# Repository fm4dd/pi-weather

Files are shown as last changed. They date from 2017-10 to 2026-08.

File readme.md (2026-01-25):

# Pi-Weather

An outdoor weather station build around the Raspberry Pi

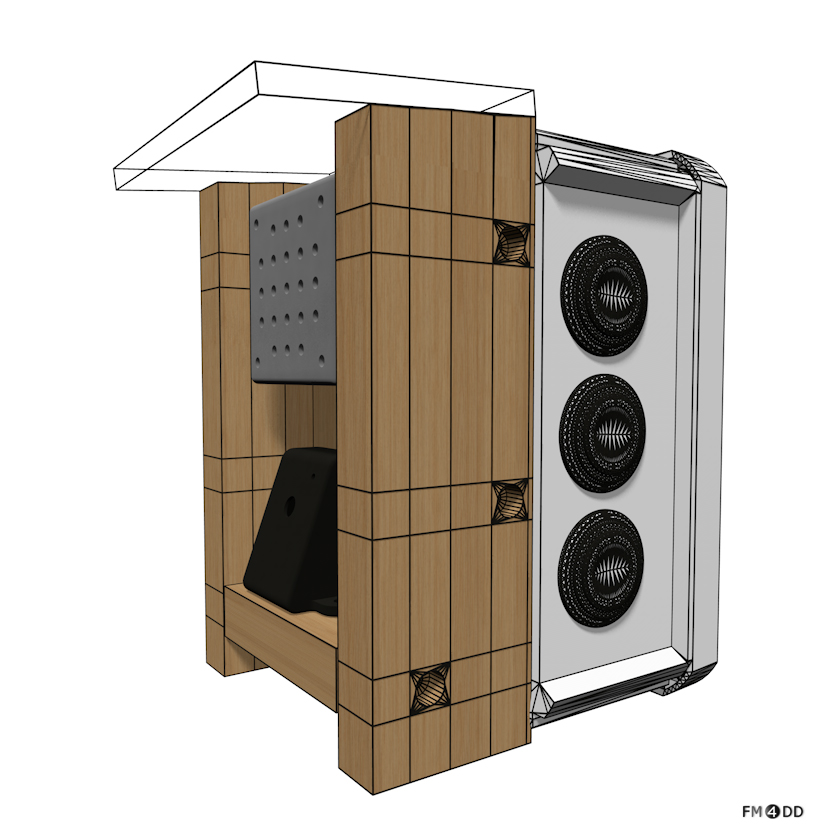
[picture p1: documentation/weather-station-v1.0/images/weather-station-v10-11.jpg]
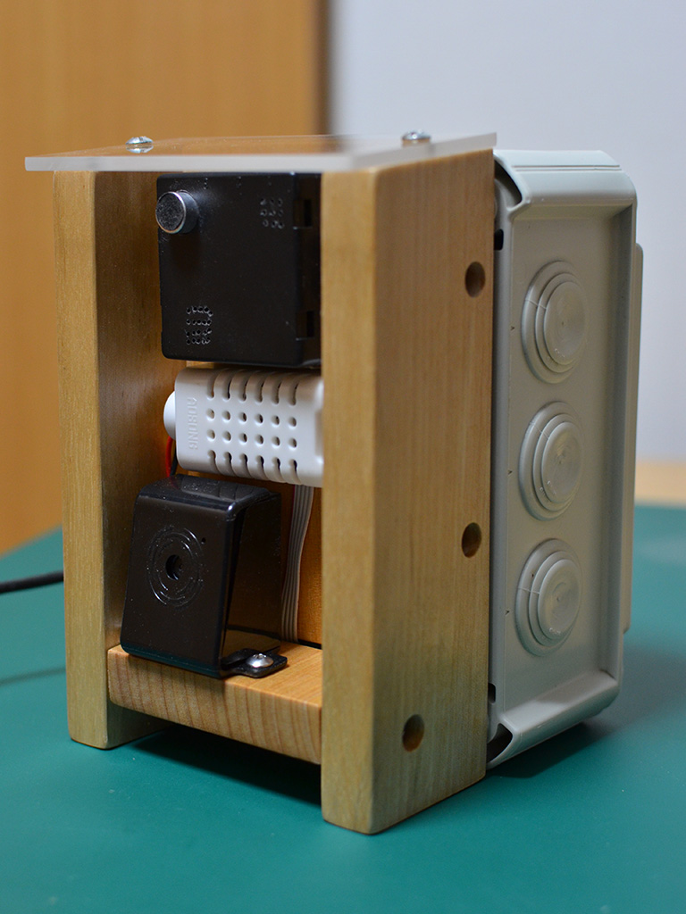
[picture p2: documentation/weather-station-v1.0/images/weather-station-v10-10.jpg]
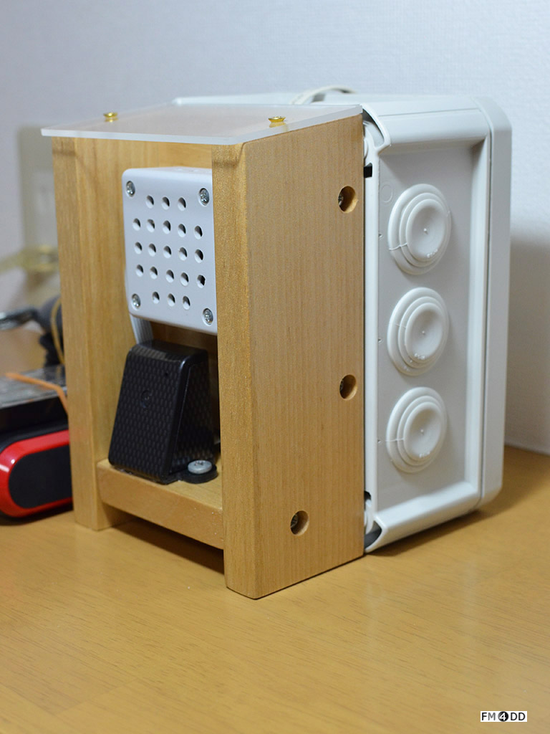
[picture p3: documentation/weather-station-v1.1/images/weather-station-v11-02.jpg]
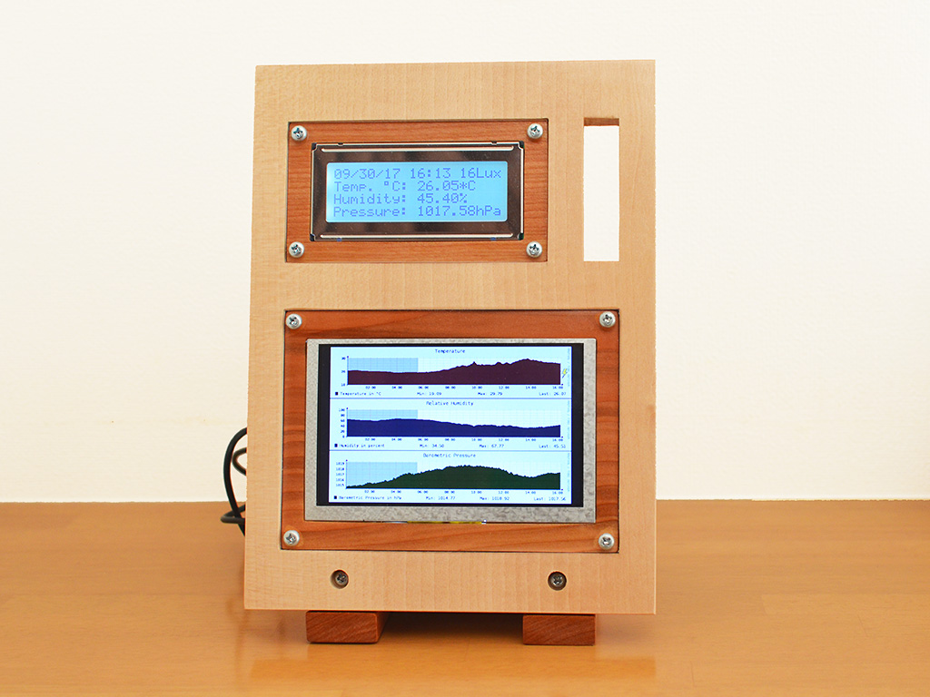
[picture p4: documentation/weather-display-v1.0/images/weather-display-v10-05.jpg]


This project contains the physical build documentation and software for running a Raspberry Pi powered outdoor weather station. With the rise of small form factor single board computers coupled with affordable sensors, monitoring of weather parameters like temperature, humidity, and air pressure allows for longterm observation, data logging and trending.

## Live Weather URL

The weather station started to work in September 2016, and its data can be seen live at <a href="http://weather.fm4dd.com/">http://weather.fm4dd.com/</a>. Besides showing actual data data readings, the weather data is presented as a graph over time. For example, the temperature data graph looks like this:

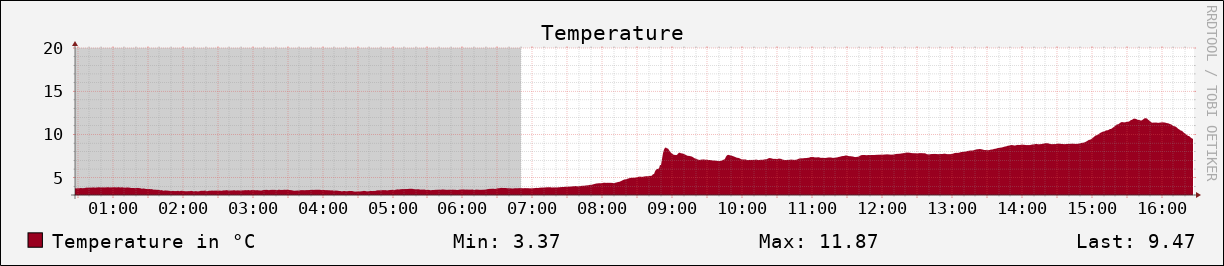
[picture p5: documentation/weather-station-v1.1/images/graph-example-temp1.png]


## Project Goals

Weather is defined as the temporary, day-to-day, minute-to-minute state of the atmosphere at a specific time and place. It is characterized by the interaction of several physical variables in the lower atmosphere (troposphere), which is constantly changing. The primary physical weather characteristics are:
* **Temperature**: Describes how hot or cold the air is, influenced by solar radiation and heat absorption.
* **Atmospheric Pressure**: The weight of the air above a given point. High pressure indicates clear skies, low pressure unsettled, cloudy, or stormy weather.
* **Wind**: The movement of air caused by differences in pressure, characterized by both speed and direction.
* **Humidity**: The amount of water vapor in the air, expressed as relative humidity, the percentage of water vapor relative to the maximum.
* **Precipitation**: Water in liquid or solid form falling from the sky as rain, snow, sleet, or hail.
* **Clouds**: Visible masses of water droplets or ice crystals suspended in the atmosphere, precursor to eventual precipitation.
* **Visibility**: The distance at which objects can be seen, which is reduced by fog, rain, or snow.

Based on available sensors, this weather station collects 3 input values, recording **Temperature**, **Atmospheric Pressure**, and **Humidity**. Because **Temperature** is strongly impacted by solar radiation, a **"Daylight"** flag based on sunrise/sunset times for the specific location provides the reference tho visualize daytime/nightime temperature ranges.

## High-level Design

Building a weather station around a Raspberry Pi allows to create a system that can long-term operate stand-alone, and has enough CPU power process environmental images in addition to sensor data. The built-in network stack can send collected data into a central consolidation site, and electrical power needs are still within range for small scale solar power. A waterproof switchbox protects the Raspberry, and a wood frame mounts the sensors together with the Raspberry Pi camera.

The <a href="documentation">documentation</a> directory has hardware BOM and CAD drawings to build the weather station and the weather display.

The necessary software can be cloned from the branches for the <a href="weather-station">weather station</a>, the optional <a href="weather-display">weather display</a>, and for the Internet accessible <a href="weather-web">website</a> that consolidates multiple weather stations from various time zones. Each weather station can operate "standalone" and self-contained, without needign to connect to a central portal.

The environmental weather data is collected through a Bosch BME280 sensor, connected to the RaspBerry Pi GPIO terminal, using the I2C bus.

## RRD Database

Sensor data is written in 1-minute intervals to an RRD database named `weather.rrd`. This database has been designed for 20 years longterm trending. It has the following parameters:

### 1. Data Source (DS) Configuration
These are the input variables stored in the database:

| DS Name | Index | Type | Min Value | Max Value | Heartbeat | Description |
| :--- | :---: | :--- | :---: | :---: | :---: | :--- |
| **temp** | 0 | GAUGE | -100 | 100 | 300s | Temperature |
| **humi** | 1 | GAUGE | 0 | 100 | 300s | Humidity (%) |
| **bmpr** | 2 | GAUGE | 0 | 200,000 | 300s | Barometric Pressure |
| **dayt** | 3 | GAUGE | 0 | 1 | 300s | Daylight Flag (Boolean) |

### 2. Round Robin Archive (RRA) Configuration
These are the retention settings, showing how data is consolidated and how long it is retained:

| RRA | Consolidation (CF) | Steps (PDP) | Resolution | Rows | Retention Period |
| :--- | :--- | :---: | :--- | :---: | :--- |
| **0** | AVERAGE | 1 | 1 Minute | 20,160 | 14 Days |
| **1** | AVERAGE | 60 | 1 Hour | 17,568 | 2 Years |
| **2** | AVERAGE | 1440 | 1 Day | 7,320 | 20 Years |
| **3** | MIN | 60 | 1 Hour | 17,568 | 2 Years |
| **4** | MAX | 60 | 1 Hour | 17,568 | 2 Years |
| **5** | MIN | 1440 | 1 Day | 7,320 | 20 Years |
| **6** | MAX | 1440 | 1 Day | 7,320 | 20 Years |

### 3. Database Characteristics

#### Data Integrity & Heartbeat:

The `minimal_heartbeat` is set to **300s** (5 minutes). With a base step of 60 seconds, the database will tolerate up to 4 consecutive missing updates. If no data is received for 5 minutes (5), the entry will be recorded as `UNKNOWN` (NaN).

All archives use an Consolidation Threshold `xff` of **0.5**. This is called the xfiles factor, and means that as long as at least 50% of the primary data points in a given interval are known, the consolidated archive entry will be calculated; otherwise, it will be stored as `UNKNOWN`.

#### High Resolution:

With a base step of **60 seconds**, the database keeps 1-minute granular data for exactly **14 days** (20,160 rows) in RRA 0.

#### Long-Term History:

The daily archives (RRA 2, 5, 6) are configured to retain data for **20 years** (7,320 rows), making this schema ideal for long-term climate trend analysis.

#### Statistical Tracking:

The schema tracks not only the **AVERAGE** values but also the **MIN** and **MAX** values for hourly and daily intervals. This prevents "averaging out" extreme weather events (like temperature spikes or pressure drops) in long-term logs.

#### Database Size:

The database uses 3MB disk space.

```
pi@pi-ws01:~ $ du -sh /home/pi/pi-ws01/rrd/weather.rrd
2.9M    /home/pi/pi-ws01/rrd/weather.rrd
```
The xml extracted database dump is 13MB.
```
pi@pi-ws01:~ $ du -sh /tmp/tmp.xml
13M     /tmp/tmp.xml
```

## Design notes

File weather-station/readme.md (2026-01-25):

## Pi Weather Station Software Package

This directory is tagged as a branch, to be cloned or copied into the weather stations Raspberry Pi OS. It contains the scripts for setup, upgrade and maintenance of weather station code and data. The weather station software is a mix of C programs and shell scripts. Data collection is using standard cron entries. RRD is used as the backend database.

## Installer Directory Overview

```
weather-station/
├── backup/ ................. (empty) Used to store local configuration and data during software upgrades
│
├── etc/ .................... Contains the configuration template, which is the first file that needs to be edited.
│
├── install/ ................ Contains the scripts to create and upgrade the station software, or repair data.
│
├── src/ .................... Contains C source code for the station software.
│                             Compilation and install is done through setup.sh inside the install directory.
└── web/ .................... Contains the template files for the local website that runs on the weather station.
                              The files are moved into place through setup.sh located in the "install" folder.
 ```

## Prerequisites

The weather stations Raspberry Pi's use Rasbian OS in the "lite" version, which fills the SD cards disk space to about 1.2 GB. The network should be configured for Internet access. The install process will get about 300 MB of additional required packages. The network connectivity can be either through Wifi or Ethernet, the weather station can work with either one.

Before I write the Rasbian OS image to SD card, I modify the image to add local network information, which lets me bring up the Pi into the local network and connect immediately at first boot. For modification, I mount the stock image file from a Linux VM as follows:

- Get file system layout

```
root@linvm:~ # fdisk -l 2017-04-10-raspbian-jessie-lite.img 
Disk 2017-04-10-raspbian-jessie-lite.img: 1.2 GiB, 1297862656 bytes, 2534888 sectors
Units: sectors of 1 * 512 = 512 bytes
Sector size (logical/physical): 512 bytes / 512 bytes
I/O size (minimum/optimal): 512 bytes / 512 bytes
Disklabel type: dos
Disk identifier: 0x84fa8189

Device                               Boot Start     End Sectors  Size Id Type
2017-04-10-raspbian-jessie-lite.img1       8192   92159   83968   41M  c W95 FAT32 (LBA)
2017-04-10-raspbian-jessie-lite.img2      92160 2534887 2442728  1.2G 83 Linux
```

- Mount the Linux partition by calculating its offset

```
root@linvm:~ # mount 2017-04-10-raspbian-jessie-lite.img -o loop,offset=$((512 * 92160)) /mnt
root@linvm:~ # ls /mnt/
```

- Update network and other configuration files

```
vi /mnt/etc/network/interfaces
vi /mnt/etc/wpa_supplicant/wpa_supplicant.conf
vi /mnt/etc/hosts
vi /mnt/etc/hostname
vi /mnt/etc/rsyslog.conf
vi /mnt/etc/modprobe.d/bcm2835_gpiomem.conf
ln -s /etc/init.d/ssh /etc/rc3.d/S02ssh
ln -s /etc/init.d/ssh /etc/rc5.d/S02ssh (or manually create a empty file called "ssh" in the boot partition of the SD card).
umount /mnt
```

Latest version of Rasbian was updated to Debian 9 Stretch, and works. It required only two package name updates (librrd4->librrd8, php5-cgi->php-cgi). Stretch added systemd logging noise which  had to be filtered to save the sdcard from extra wear.

## Software Installation

After first boot, run raspi-config to enable the I2C-bus and camera, configure timezone. Download the weather-station SW package (git or manual .gtgz package download).

First, create or update the configuration file `pi-weather.conf` in the `etc` directory. The following settings are minimum to be configured:

- *pi-weather-sid* --> Station ID that must be unique to each station. The value is used to set the hostname, and for data uploads to the centralized Internet website. The schema is pi-wsXX. XX is a two-digit number that is simply counted up.

- *pi-weather-lat* --> GPS latitude of the weather stations location. Value needs to be in decimal format.

- *pi-weather-lon* --> GPS longitude of the weather stations location. Decimal format.

- *pi-weather-tzs* --> Weather stations timezone setting (match entry in /usr/share/zoneinfo).

- *sensor-type=bme280* --> One of the supported sensor types.
*sensor-addr=0x76* --> The sensors I2C address.

Next, change directory into the `install` folder, and execute the script `setup.sh`. The script should run tests to confirm the sensor function. It creates the weather stations work directory named after the station ID, e.g. `pi-ws01`, containing the binaries and data directories.

#### Installed Spplication Folder Structure

```
pi-ws01/
├── bin/ .................... [Executables & Shell Scripts]
│                             (Data processing binaries and .sh scripts)
├── etc/ .................... [Configuration & Batch Files]
│                             (System .conf and SFTP transfer .bat files)
├── log/ .................... [Text Logs]
│                             (.log files for monitoring background tasks)
├── rrd/ .................... [Database Files]
│                             (.rrd files for time-series weather data)
├── var/ .................... [Data, Compressed XML & Logs]
│   │                         (Raw .txt data, .xml.gz, and .log files)
│   └── tmp/ ................ [Temporary Directory]
└── web/ .................... [Web Application Files]
    │                         (Web logic .php, templates .htm, and .json)
    ├── images/ ............. [Visual Assets & Generated Charts]
    │                         (UI .gif files and sensor .png/.jpg graphs)
    └── wcam/ ............... [Webcam Directory]
                              (Sub-folders for webcam media storage)
```

## Local Station Operation

After completion, reboot the Pi. The weather station software installed a local web service (Lightttp) that allows pointing a browser to the stations IP address. The cron jobs should start collecting sensor data filling the RRD, and taking camera pictures in 1 minute intervals. Any issues can be investigated by looking at the files in `var` and `log` directories.

- Check the sensor data file existence and timestamp

```
pi@pi-ws01:~ $ ls -l pi-ws01/var/sensor.txt
-rw-r--r-- 1 pi pi 61 Oct 29 11:54 pi-ws01/var/sensor.txt
```

- Check the sensor data content

```
pi@pi-ws01:~ $ cat pi-ws01/var/sensor.txt
1509245646 Temp=14.83*C Humidity=91.26% Pressure=100555.85Pa
```

- Check the RRD database update log

```
pi@pi-ws01:~ $ cat pi-ws01/var/rrdupdate.log
rrdupdate.sh: Run at Sun 29 Oct 11:55:11 JST 2017
rrdupdate.sh: Config file [/home/pi/pi-ws01/bin/../etc/pi-weather.conf]
rrdupdate.sh: Sensor Data [1509245706 Temp=14.84*C Humidity=91.20% Pressure=100561.37Pa]
rrdupdate.sh: Temperature [14.84] outlier detection OK.
rrdupdate.sh: Humidity [91.20] outlier detection OK.
rrdupdate.sh: Pressure [100561.37] outlier detection OK.
rrdupdate.sh: daytime flag /home/pi/pi-ws01/bin/daytcalc -t 1509245706 -x 139.628999 -y 35.610381
rrdupdate.sh: daytcalc 1509245706 returned [0] [day].
/usr/bin/rrdtool update /home/pi/pi-ws01/rrd/weather.rrd 1509245706:14.84:91.20:100561.37:0
return_value = 0
[1509245700]RRA[AVERAGE][1]DS[temp] = 1.4839000000e+01
[1509245700]RRA[AVERAGE][1]DS[humi] = 9.1206000000e+01
[1509245700]RRA[AVERAGE][1]DS[bmpr] = 1.0056081800e+05
[1509245700]RRA[AVERAGE][1]DS[dayt] = 0.0000000000e+00
Creating image /home/pi/pi-ws01/web/images/daily_temp.png... 700x150
Creating image /home/pi/pi-ws01/web/images/daily_humi.png... 700x150
Creating image /home/pi/pi-ws01/web/images/daily_bmpr.png... 700x150
rrdupdate.sh: Finished Sun 29 Oct 11:55:12 JST 2017
```

## Integration with the Internet-based Web Server

The weather station is typically part of a private (home) network that allows only outbound Internet access. To access the weather stations data remotely, the station can be set to send its sensor and camera data to the central Internet web server (e.g. http://weather.fm4dd.com). The script `send-setup.sh` in the `install` directory collects the necessary information and copies it into the Internet server.

After the Internet web server has been set up, the sensor data is feed to Internet web server in parallel to the local RRD database updates. To compensate for temporary local network outages, a daily transmission sends the full RRD database to the Internet server. 

Because RRD databases are CPU-specific, they can't be copied from a Raspi (ARM) to an Intel environment. For RRD database migrations, the `rrdtool dump` command creates a XML extract that can be restored to different platforms. For manal DB transmission, below commands serve as an example:

- Raspi side

```
pi@pi-ws01:~ $ rrdtool dump /home/pi/sensor/rrd/weather.rrd > weather.xml
pi@pi-ws01:~ $ scp weather.xml user@weather.fm4dd.com:~
```

- Internet server side

```
ws01@weatherweb:~ $ rrdtool restore /home/ws01/weather.xml pi-ws01.rrd
```

## Optional Hardware Setup

The script `rtcenable.sh` can enable an optional battery-buffered real-time clock module. The RTC is helpful for weather stations without permanent Internet access. If they are unable to sync their time from the net, they are at risk of running wrong system time, which in turn could break the sensor data collection.

## Sensor Failures and Recovery

Due to age or sever weather conditions, sensors break down after some time. Instead of just stopping operations, they often start to send wrong data readings. It is not uncommon to see -2 temperature, 500000 Pa pressure or 100% humidity in such circumstances. While the weather station has a "outlier" function to identify and eliminate sporadic, single miss-reads, the continous reporting of false data from a broken sensor is harder to handle. After fixing the sensor hardware, database cleanup is done to eradicate the erroneous longterm data which take hold in the MIN/MAX aggregations. With the database type being RRD, there is no easy way to edit or update individual entries.

### rrdrepair.sh

The script `rrdrepair.sh` was created to help with database cleanup in between current data updates. It exports the RRD content into XML, which is then updated by a prepared vi source file before being re-imported into RRD. Due to the RRD size, XML line count is quite high, which slows down vi's line matching. Ideally the RRD repair process is done in between the 1-minute data readings to prevent loss of a reading. `rrdrepair.sh` therefore catches the moment right after the latest file update to maximise the time window.

### wsreplace.sh

The script `wsreplace.sh` automates the transfer of the weather station work directory and other necessary data to a second station in order to let it take over the function of the first. This allows for a quick swap of a complete weather station for repairs or upgrades. Before, this swap needed too much time for extracting the old stations micro SD card.

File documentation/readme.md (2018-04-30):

# Pi-Weather Design and Build Documentation

This folder contains documentation for the physical build of the outdoor weather station and the weather display. It includes CAD drawings, wiring schemas, bill of materials (BOM) and build pictures.

## Weather Display, Version 1.0

A permanent weather display was on the back of my mind. A 20x4 LCD character display for displaying the weather stations data, and a 5 inch TFT screen for showing the graphs. The control unit is a Raspberry Pi A Plus. It is interfacing with the TFT display though a HDMI board, and through an I2C with the character LCD. 

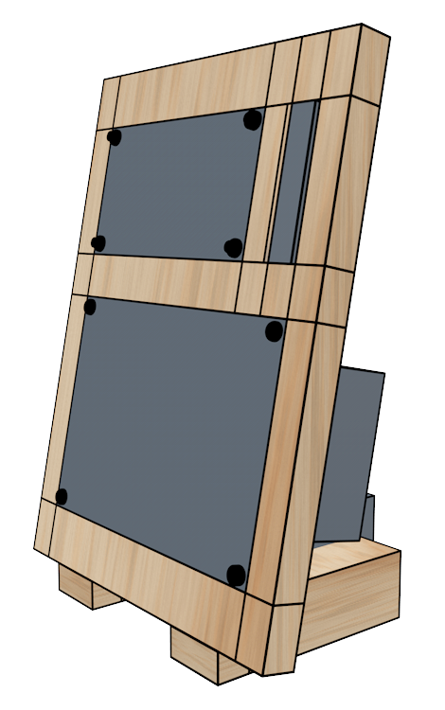
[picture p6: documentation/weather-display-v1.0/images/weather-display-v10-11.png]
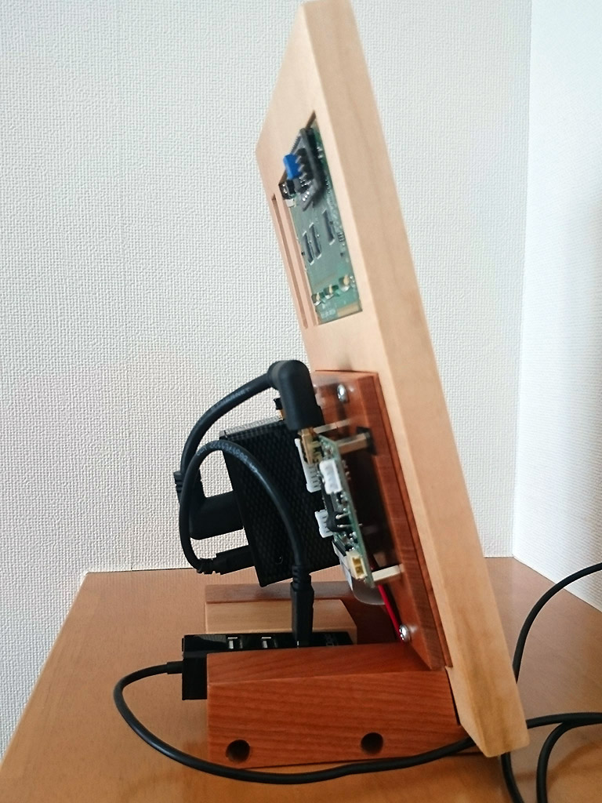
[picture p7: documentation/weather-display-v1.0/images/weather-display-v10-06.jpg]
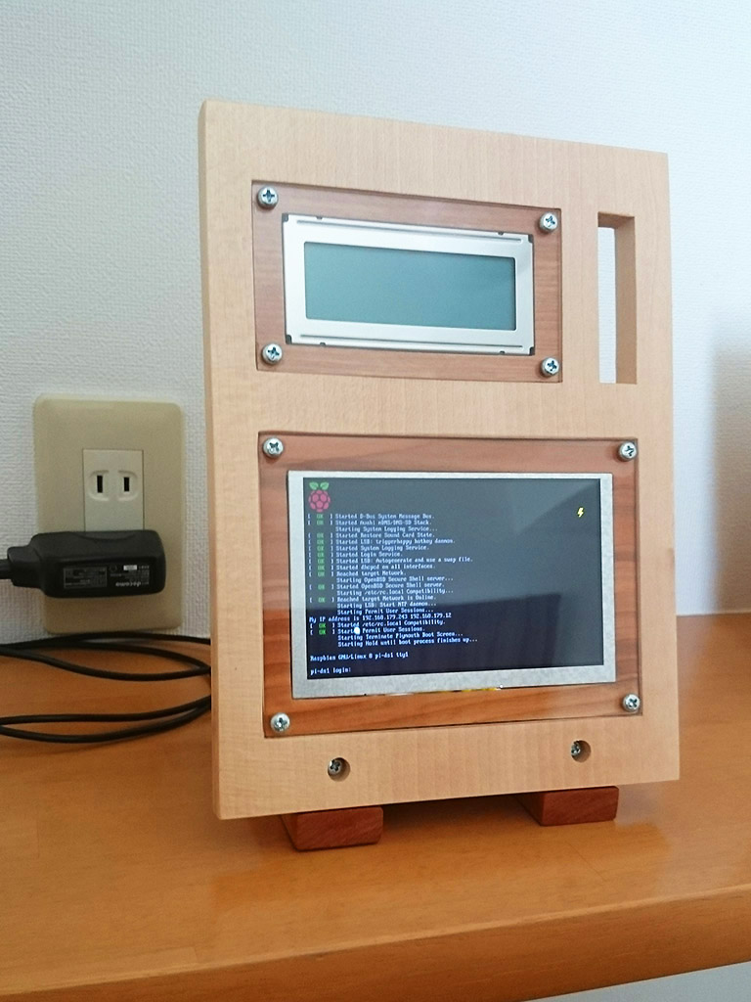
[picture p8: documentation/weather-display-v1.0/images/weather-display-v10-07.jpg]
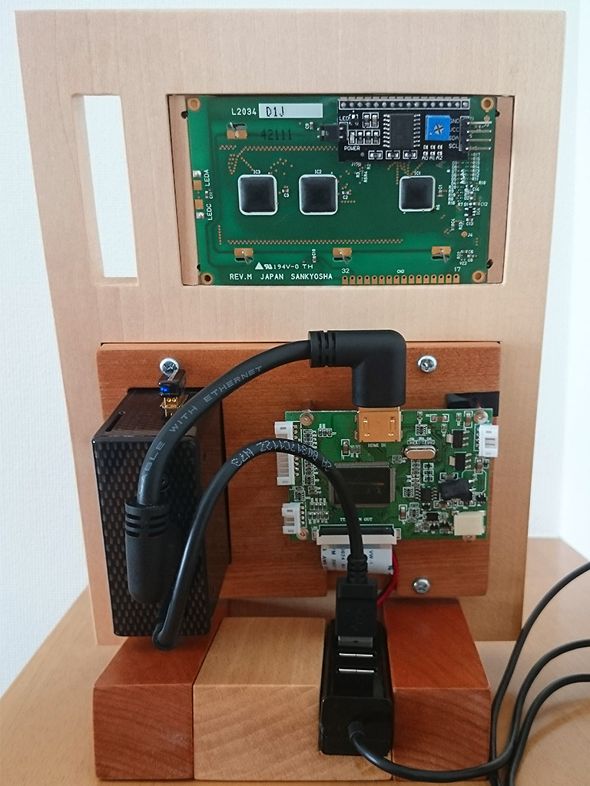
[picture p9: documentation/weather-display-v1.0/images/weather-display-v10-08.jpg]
    

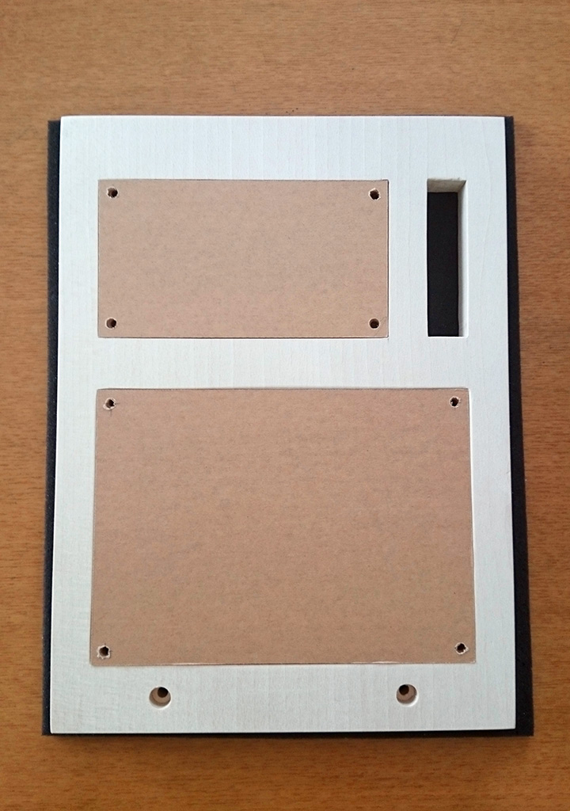
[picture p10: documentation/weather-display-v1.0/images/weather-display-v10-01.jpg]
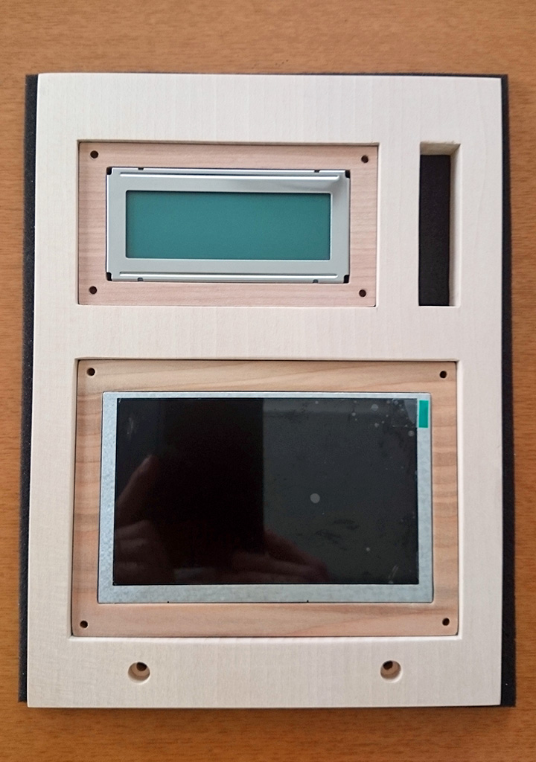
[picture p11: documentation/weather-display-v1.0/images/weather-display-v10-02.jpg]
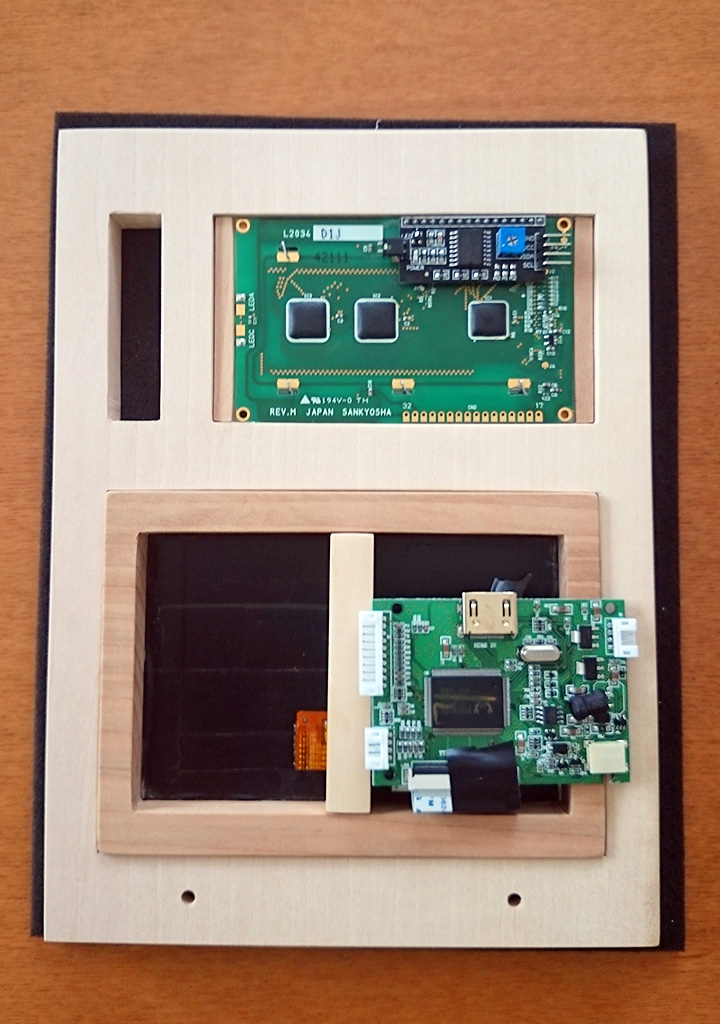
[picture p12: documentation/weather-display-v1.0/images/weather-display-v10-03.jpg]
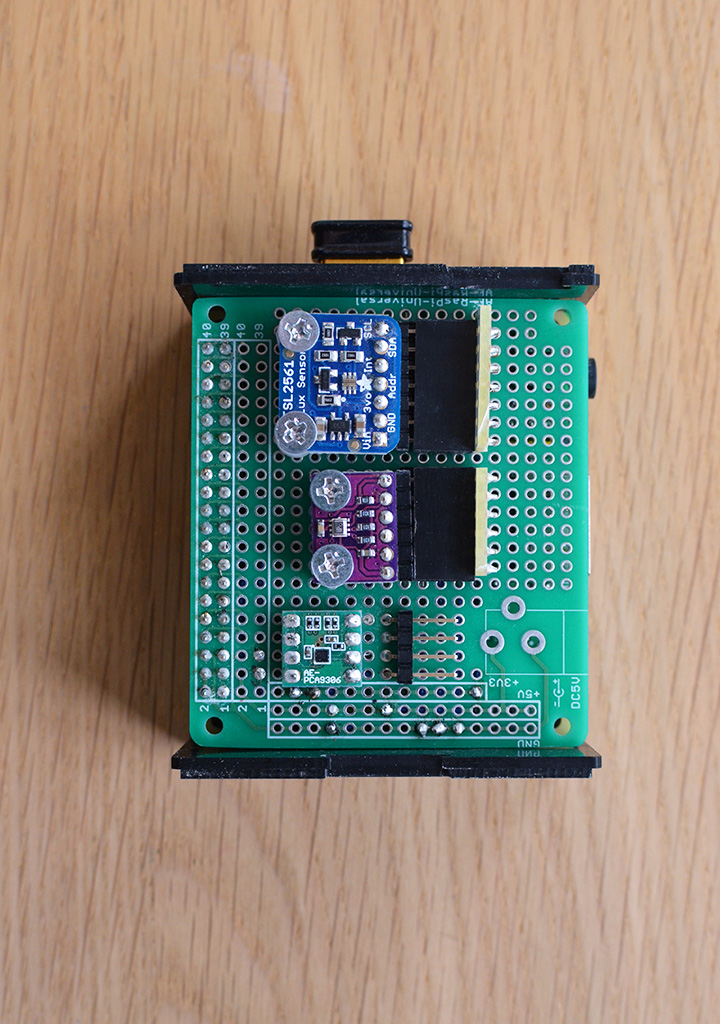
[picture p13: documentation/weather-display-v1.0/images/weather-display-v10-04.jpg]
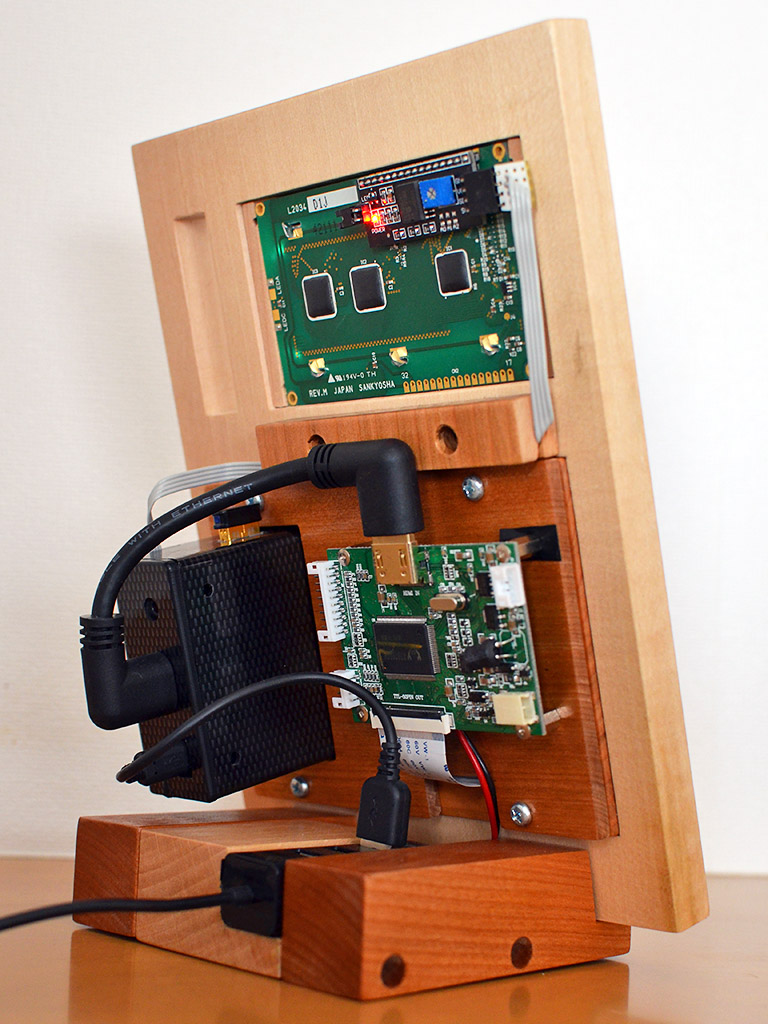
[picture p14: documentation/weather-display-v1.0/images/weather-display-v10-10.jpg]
    

## Weather Station, Version 1.1

 After five months of operation, the weather stations sensor AM2302 started to fail, with humidity getting stuck permanently at 100%. Research found this is a common and rather frequent problem. The search of an alternate sensor lead to the Bosch BME280. It offered several benefits by combining temperature, humidity and air pressure in one small package. The I2C interface seemed easier to handle than the non-standard bit-banging protocol of the AM2302. A suitable case was found for housing the BME280 sensor, and the wood frame received small changes to reduce manufacture effort. The sensor is made pluggable for easy replacement.

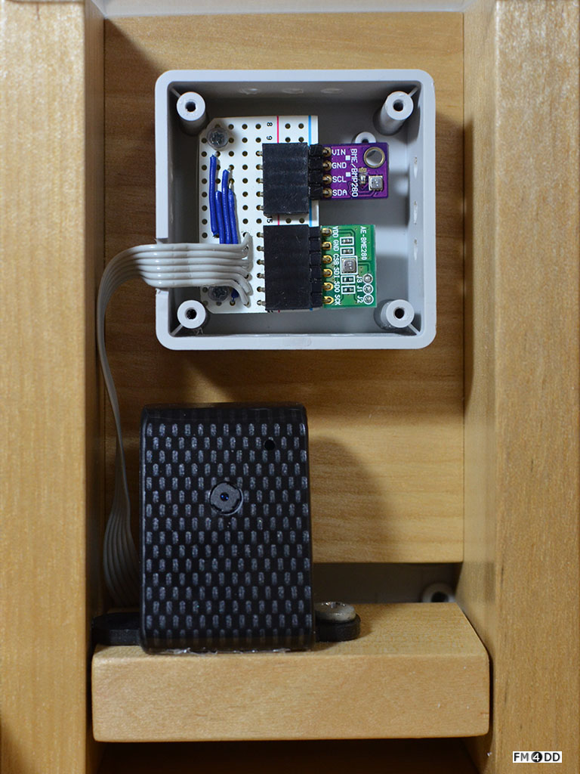
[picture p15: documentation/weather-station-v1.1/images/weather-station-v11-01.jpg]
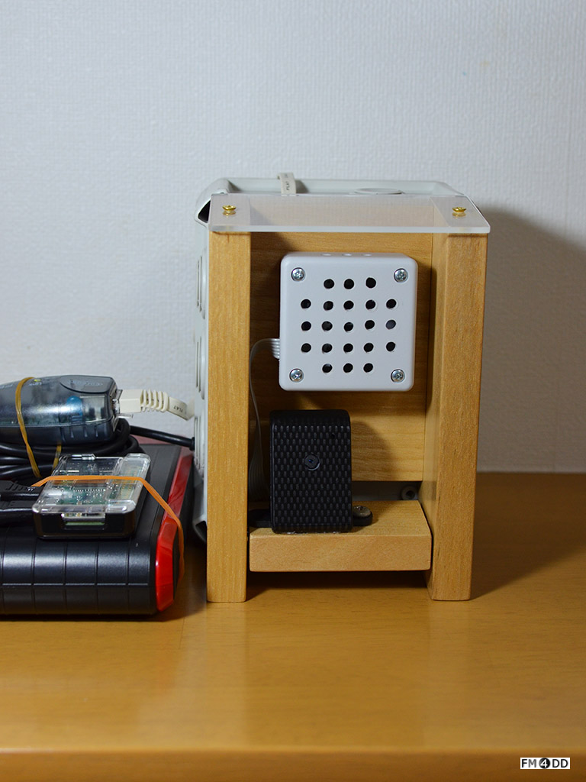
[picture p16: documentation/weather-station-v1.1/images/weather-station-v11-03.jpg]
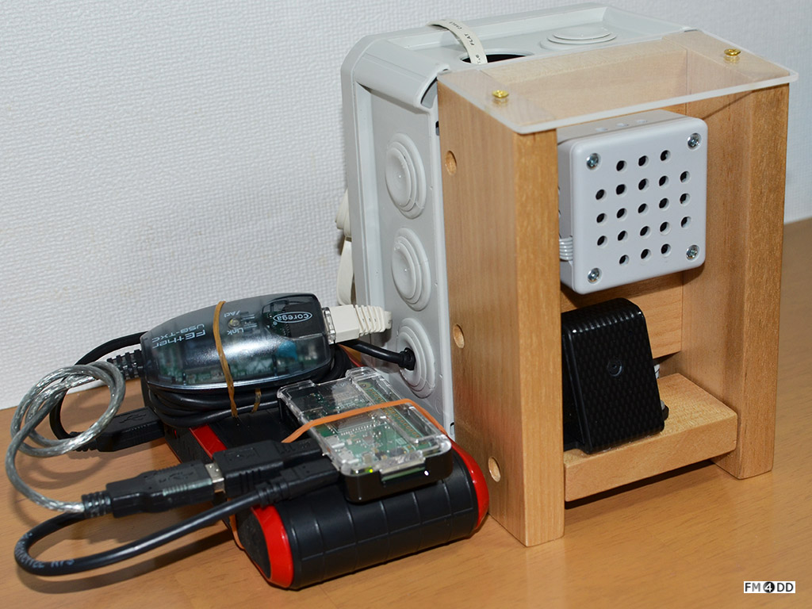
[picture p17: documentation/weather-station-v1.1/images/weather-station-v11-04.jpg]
   

This version started to use the Raspberry Pi 3 with built-in WiFi for network connectivity. Together with the new sensor case, the interface wiring slightly changed from version 1.0. A serial line addition is prepared to obtain data from a Victron charge controller (solar-powered "off-the-grid" operation).

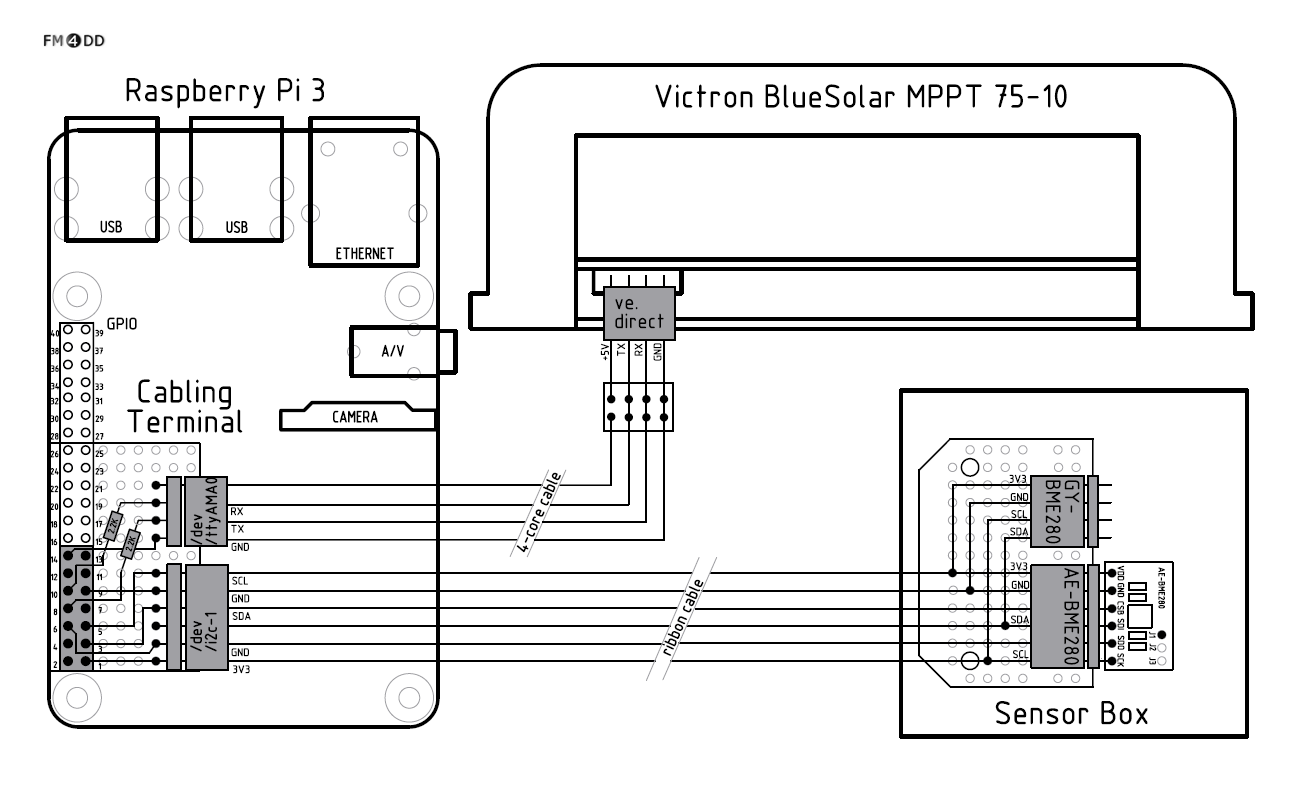
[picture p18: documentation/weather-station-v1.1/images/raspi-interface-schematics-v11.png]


## Weather Station, Version 1.0

This was the first weather station build. It used a AM2302 temperature/humidity sensor from <a href="http://www.aosong.com/en/home/index.asp">Aosong</a>. After functional tests confirmed the sensors function, a suitable weather-proof box for housing the Raspberry Pi was found at <a href="https://www.conrad.de/">Conrad</a>, Bettermans junction box <a href="https://obo.de/article/display/en-wo/junction-box-t-100-plug-in-seal.html">OBO T100</a>.

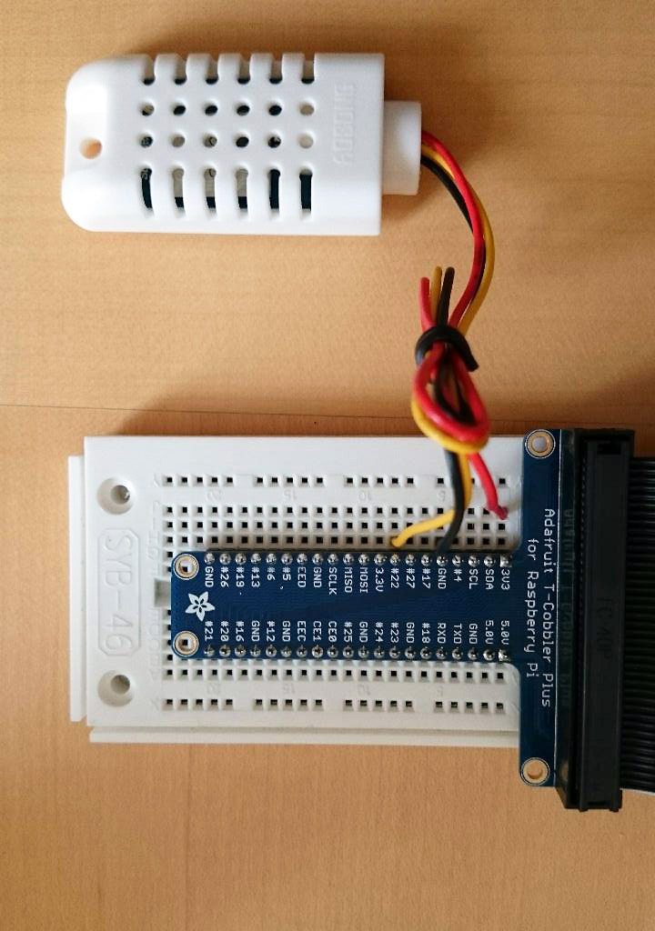
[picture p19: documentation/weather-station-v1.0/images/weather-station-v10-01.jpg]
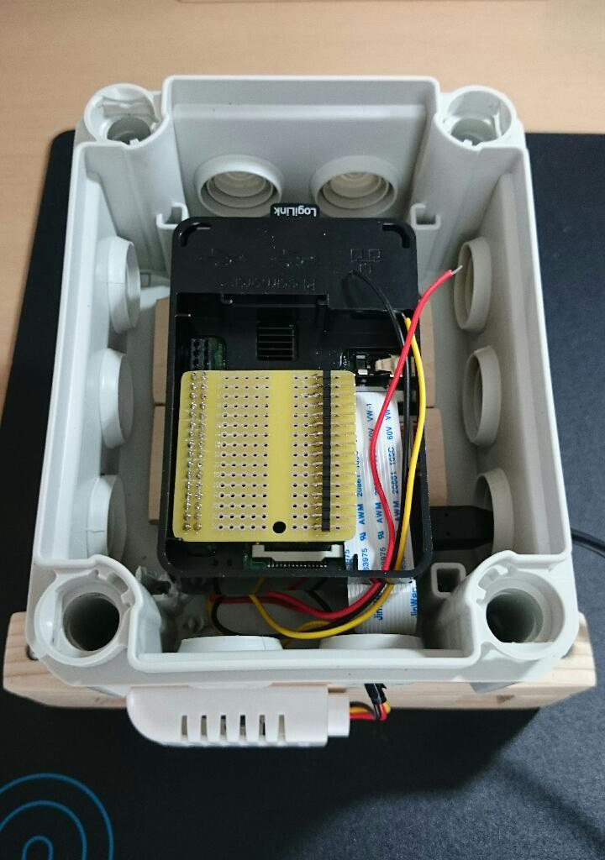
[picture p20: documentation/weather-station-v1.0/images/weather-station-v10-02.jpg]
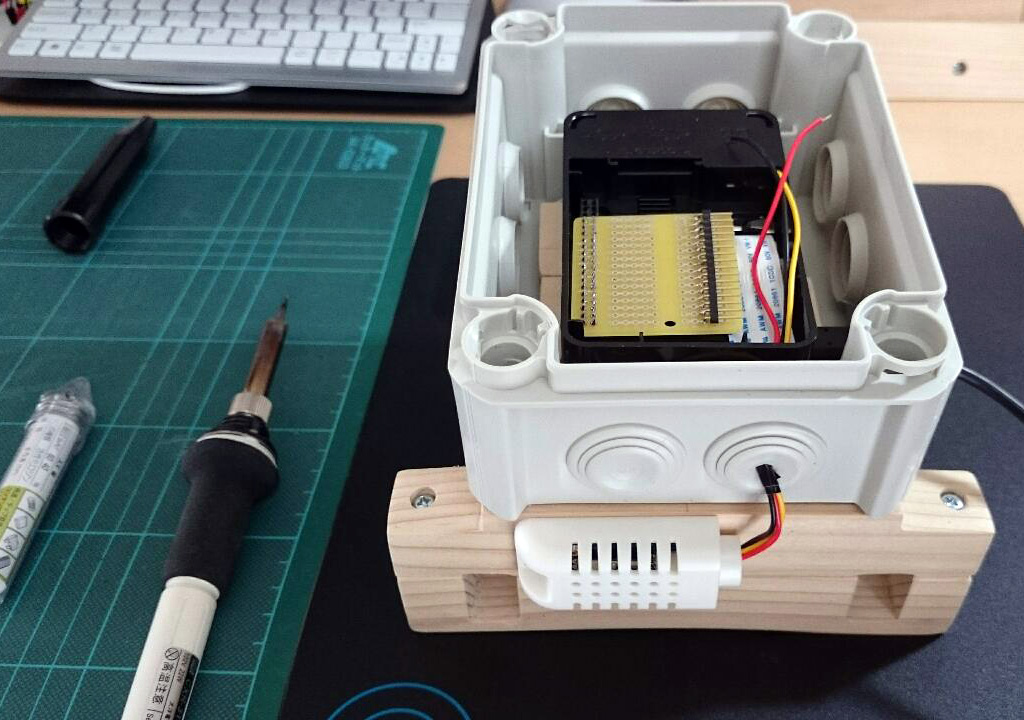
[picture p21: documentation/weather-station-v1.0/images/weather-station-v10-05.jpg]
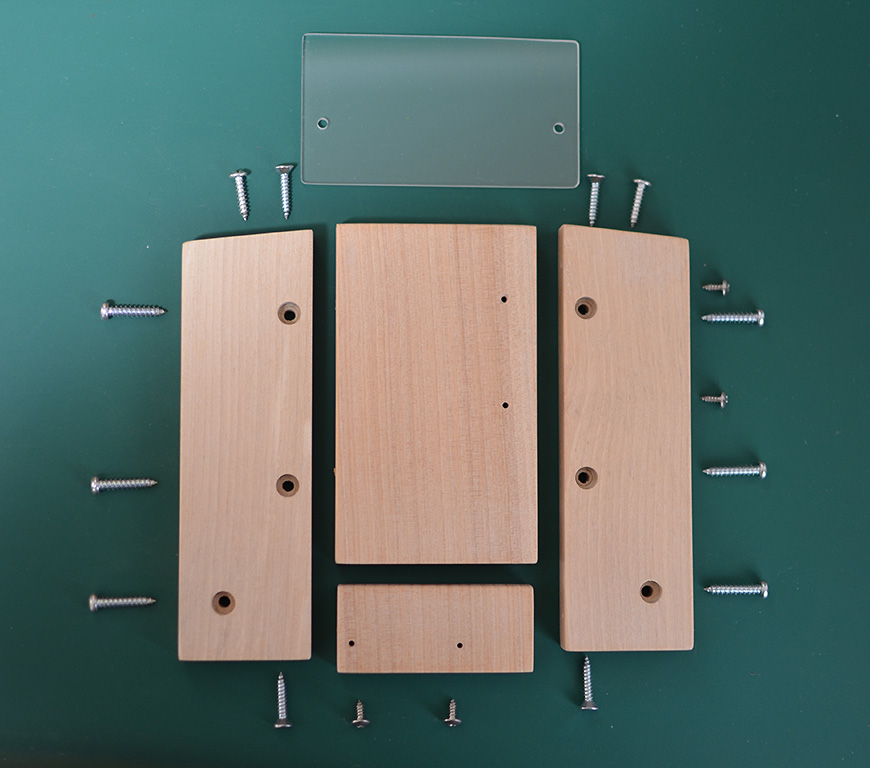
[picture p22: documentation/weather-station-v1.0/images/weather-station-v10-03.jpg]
   

With the AM2302 sensor working, adding Raspberry Pi camera required a suitable mount. The wooden frame was drawn up and made.

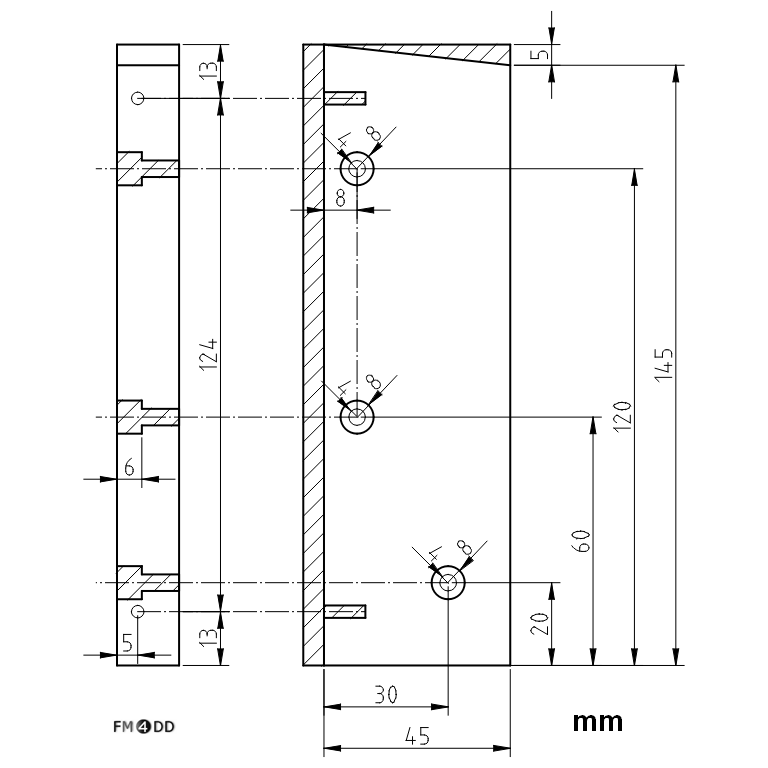
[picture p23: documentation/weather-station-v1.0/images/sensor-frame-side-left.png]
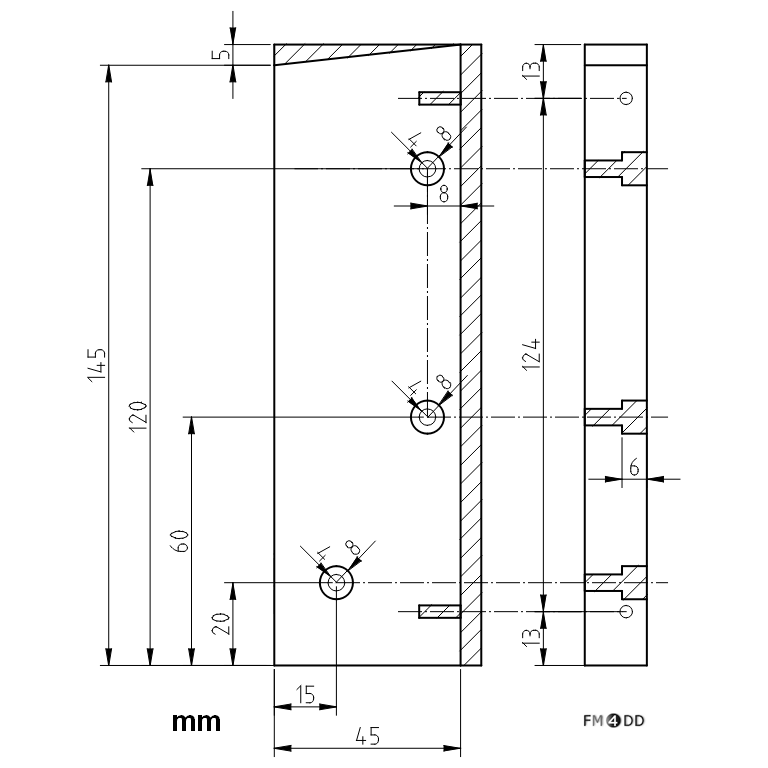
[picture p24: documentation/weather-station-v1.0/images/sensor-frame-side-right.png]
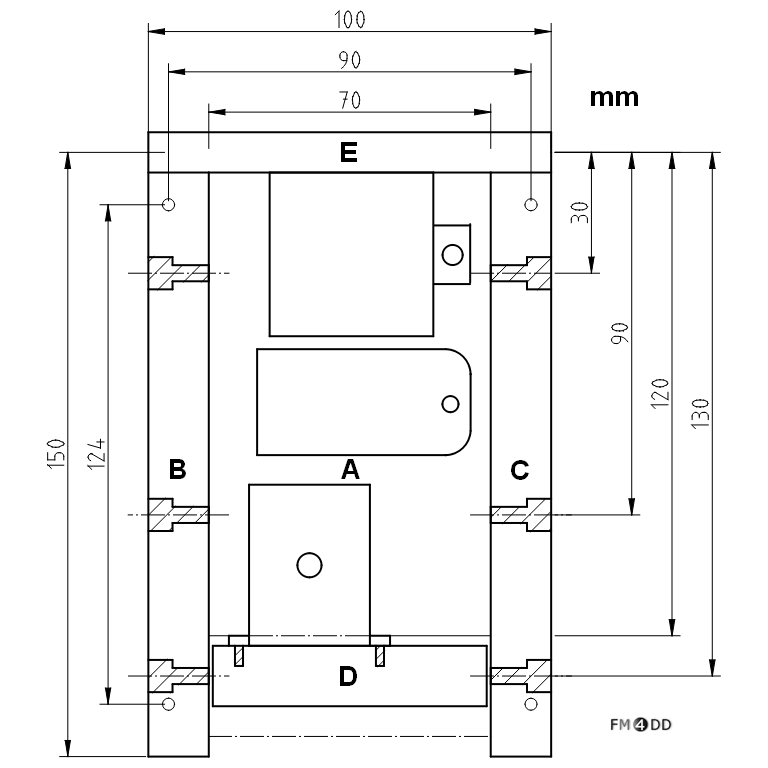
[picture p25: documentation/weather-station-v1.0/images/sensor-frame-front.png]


After 3 months of operation, a second sensor Bosch BMP180 has been added through i2C for recording barometric air pressure. The wiring schematics below show the connectivity.

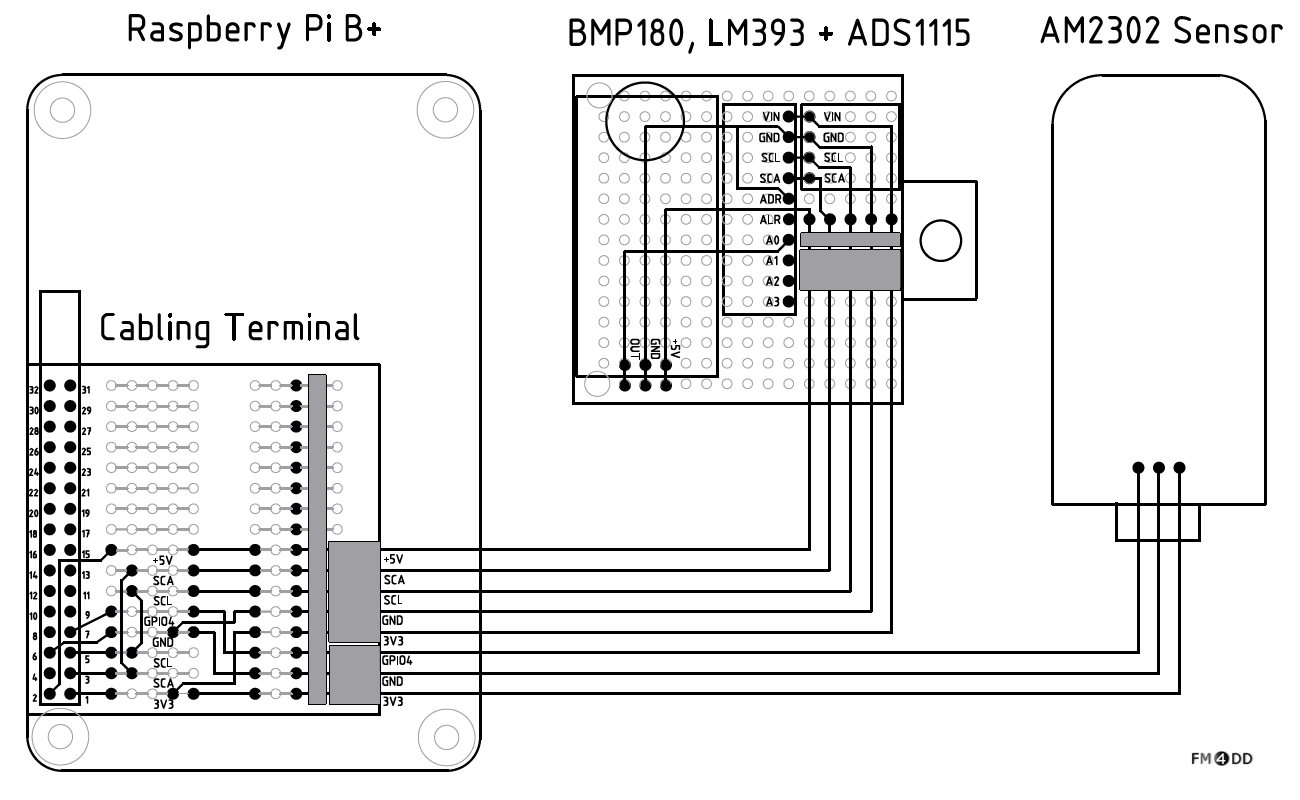
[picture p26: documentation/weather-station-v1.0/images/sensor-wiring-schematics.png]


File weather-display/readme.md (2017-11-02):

# Weather Display Software Package

## Background

The Pi-Weather Display is a Raspberry Pi A+ powered device for
permanently showing the outdoor weather data provided by the
Pi-Weather station. In its current design, it has a 20x4 Char
LCD screen for text output of date, temperature, humidity and
barometric pressure.

Additionally, a 5 inch TFT display connects through HDMI, and
shows the current data graphs vertically aligned. Both LCD and
TFT data is refreshed in 1 minute intervals, matching the data
collection frequency of the Raspberry Pi weather station.

It is equipped with a Adafruit TSL2561 light sensor to power
down the display at night, and wake it up with first light.

## 5 inch TFT screen component function

By default and out of the box, the TFT screen runs the Raspberry 
Pi commandline console. to display images, the "fbi" package has
been installed.

To display images on the TFT with the "fbi" program, see the
following example:

```sudo fbi --autozoom --noverbose --vt 1 out.png```

If it does not work try another vt terminal number, sometimes it
runs on 2. 

Raspbian runs multiple virtual terminals, they can be switched with
command "chvt".

The TFT screen can be turned off with command "tvservice -o", and
on with "tvservice -p". It seems more reliable to use the command 
"vcgencmd display_power 0" and "vcgencmd display_power 1".

For displaying a single picture with the "fbi" command, we need
to combine the separate graph pictures into a single image. This
can be done with the ImageMagick package. Using the "convert"
program, images can be aligned vertically, horizontally, clockwise,
embedding text or logos, etc. Its very powerful.

This is an example for aligning the 3 graph images into a single pic:

```convert \( daily_temp.png daily_humi.png daily_bmpr.png -append \) +append out.png```

## 20x4 character LCD component function

The 20x4 character LCD connects via a PCF8574 I2C-to-HD44780 LCD 
backpack module. Since the LCD is a 5V device while the Raspberry Pi
GPIO level is 3.3V, the PCA9306 I2C-bus 3.3-5V level converter
is in line. I am currently using a small python driver library for
writing to the LCD display. The driver is lightweight and only needs
installation of the " python-smbus" package.

## Component integration

Above display and sensor components are controlled though a main bash
script "display.sh", which in turn calls "lux" for reading the light
sensor, and sensor.py for parsing the raw weather data and displaying
it to the character LCD. 

## Power consumption

Daylight mode:	approx 760 ~ 830 mA
Nighttime mode: approx 360 ~ 410 mA

## TODO

Implement improved error handling to identify various conditions
such as Weather Station down, Wifi down, SCP error.

Build and integrate a push-button control panel to switch modes,
e.g. use the integrated I2C sensor GY-BME280 for indoor temperature
display mode.

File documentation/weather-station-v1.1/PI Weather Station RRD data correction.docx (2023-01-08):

### Pi Weather Station RRD Data Correction

### Introduction

### The PI weather station writes sensor data into the RRDtool database - https://oss.oetiker.ch/rrdtool/.

### In severe weather conditions, a sensor may fail which results in recording wrong values, such as high negative temperatures at -37 C, humidity at 0%, or barometric pressure at 600 hPa.

### Although the sensor update code function eliminates only very short one-time outliers, sensor failures occurring over several minutes to hours will create wrong database entries. Below are outlier.log entries showing the start of a failure.

Mon, 29 Mar 2021 13:35:01 +0900 [1616992446 Temp=-2.00*C Humidity=0.00% Pressure=nanPa] -> temperature outlier [-2.00].

Mon, 29 Mar 2021 13:36:01 +0900 [1616992506 Temp=99.73*C Humidity=100.00% Pressure=406245.38Pa] -> temperature outlier [99.73].

Mon, 29 Mar 2021 16:22:01 +0900 [1617002466 Temp=-89.14*C Humidity=0.00% Pressure=909878.38Pa] -> temperature outlier [-89.14].

Sun, 04 Apr 2021 19:29:01 +0900 [1617532086 Temp=-2.00*C Humidity=0.00% Pressure=nanPa] -> temperature outlier [-2.00].

Sun, 04 Apr 2021 19:29:01 +0900 [1617532086 Temp=-2.00*C Humidity=0.00% Pressure=nanPa] -> humidity outlier [0.00].

Mon, 05 Apr 2021 01:05:01 +0900 [1617552246 Temp=-143.99*C Humidity=0.00% Pressure=165870.38Pa] -> temperature outlier [-143.99].

### Sensor failures on March 29 and April 4, shown as gaps in the database-extracted temperature graph:

The Bosch BME280 sensor often recovers from these failures when weather conditions improve. Appropriate sensor protection from direct water intake in severe storms is very important. Here is the procedure to manually update wrong sensor data inside RRD to restore proper data aggregation. Keeping wrong recorded values distorts the average, and sets from min/max values.

### Identify Failed Database Entries:

### The first step is to create the instructions for database record updates in the file rrdrepair.vi located under /home/pi/pi-weather/install. We extract the database values as readable XML format into the tmp folder:

pi@pi-ws01:~/pi-weather/install $ rrdtool dump /home/pi/pi-ws01/rrd/weather.rrd /tmp/tmp.xml

pi@pi-ws01:~/pi-weather/install $ ls -l /tmp/tmp.xml

-rw-r--r-- 1 pi pi 13307568 Apr 26 09:47 /tmp/tmp.xml

pi@pi-ws01:~/pi-weather/install $ head -3 /tmp/tmp.xml

<?xml version="1.0" encoding="utf-8"?>

<!DOCTYPE rrd SYSTEM "http://oss.oetiker.ch/rrdtool/rrdtool.dtd">

<!-- Round Robin Database Dump -->

### Now we identify failed records inside the XML extract. A sensor failure would record NaN values as below:

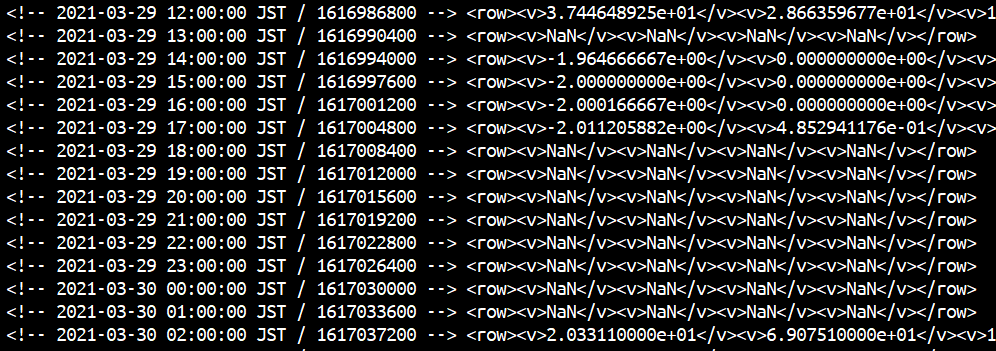
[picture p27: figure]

### Create Database Record Update Instructions:

The database update instructions will be written into a VI instruction file named repair.vi. We can re-use a old repair.vi.<date> backup as an example. The content typically has a positioning instruction that identifies the wrong entry by its data and time, followed by a substitute instruction that updates the wrong values. Important is the correct escaping of forward slash (/) and dot (.) characters to replace correctly.

pi@pi-ws01:~/pi-weather/install $ cp rrdrepair.vi.20190803 rrdrepair.vi

pi@pi-ws01:~/pi-weather/install $ vi rrdrepair.vi

:" ##########################################################

:" rrdrepair.vim: This file is read by rrdrepair.sh as input.

:" Below lines have been prepared to fix the RRD data lines

:" with wrong sensor readings, e.g. -13.7 Celsius instead of 30

:" ##########################################################

:/<!-- 2021-03-29 13:00:00 JST \/ 1616990400 --> <row><v>NaN

:.,+12:s/NaN<\/v><v>NaN<\/v><v>NaN<\/v><v>NaN/2.844648925e+01<\/v><v>2\.866359677e+01<\/v><v>1\.000874246e+05<\/v><v>0\. 000000000e+00/

:1

:/<!-- 2021-03-29 14:00:00 JST \/ 1616994000 --> <row><v>-1\.964666667e+00

:.,+4s/-[12]\..........e+00<\/v><v>.\..........e.0.<\/v><v>NaN/2.944648925e+01<\/v><v>2\.866359677e+01<\/v><v>1\.0008742 46e+05/

:1

:" 1st set done

### For position control, its good practice to jump back to the beginning of the file with ‘:1’.

### Test Database Record Update Instructions:

### The DB instructions should be tested on the temporary extracted DB. Verify the update of the correct records. Check correct line selection, and check correct update format, e.g. no missing field markers.

### Update the DB:

To make the DB update run rrdrepair.sh. If run without options, the update is simulated. The argument ‘-p’ does the real production update. The script catches the moment right after the last DB update by monitoring the file age. With an update frequency of every minute, there are 60 seconds time to repair before the next data update comes in.

pi@pi-ws01:~/pi-weather/install $ ./rrdrepair.sh

rrdrepair.sh start: Mon Apr 26 12:30:57 JST 2021

# 1. Check for prd argument, and load the config file

rrdrepair.sh: Reading file [../etc/pi-weather.conf] with [17] values

rrdrepair.sh: test run, simulating execution. Use ./rrdrepair.sh -p for PRD run.

Done.

# 2. Catch the time after the existing RRD DB was updated

date: Mon Apr 26 12:30:57 JST 2021 file update: Mon Apr 26 12:30:11 JST 2021 rrdage: 46

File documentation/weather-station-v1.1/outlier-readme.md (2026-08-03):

# outlier

THe program "outlier" is a pre-write sanity check. It is given a freshly
measured sensor value that is *about to be written* to the RRD, and compares
it against the last recorded RRD value for that data source.
It checks whether the new measurement is implausible before it gets written to
the RRD database. It returns '0' if the measurement looks plausible, and '1'
if the measurement is too far outside of a expected deviation range.

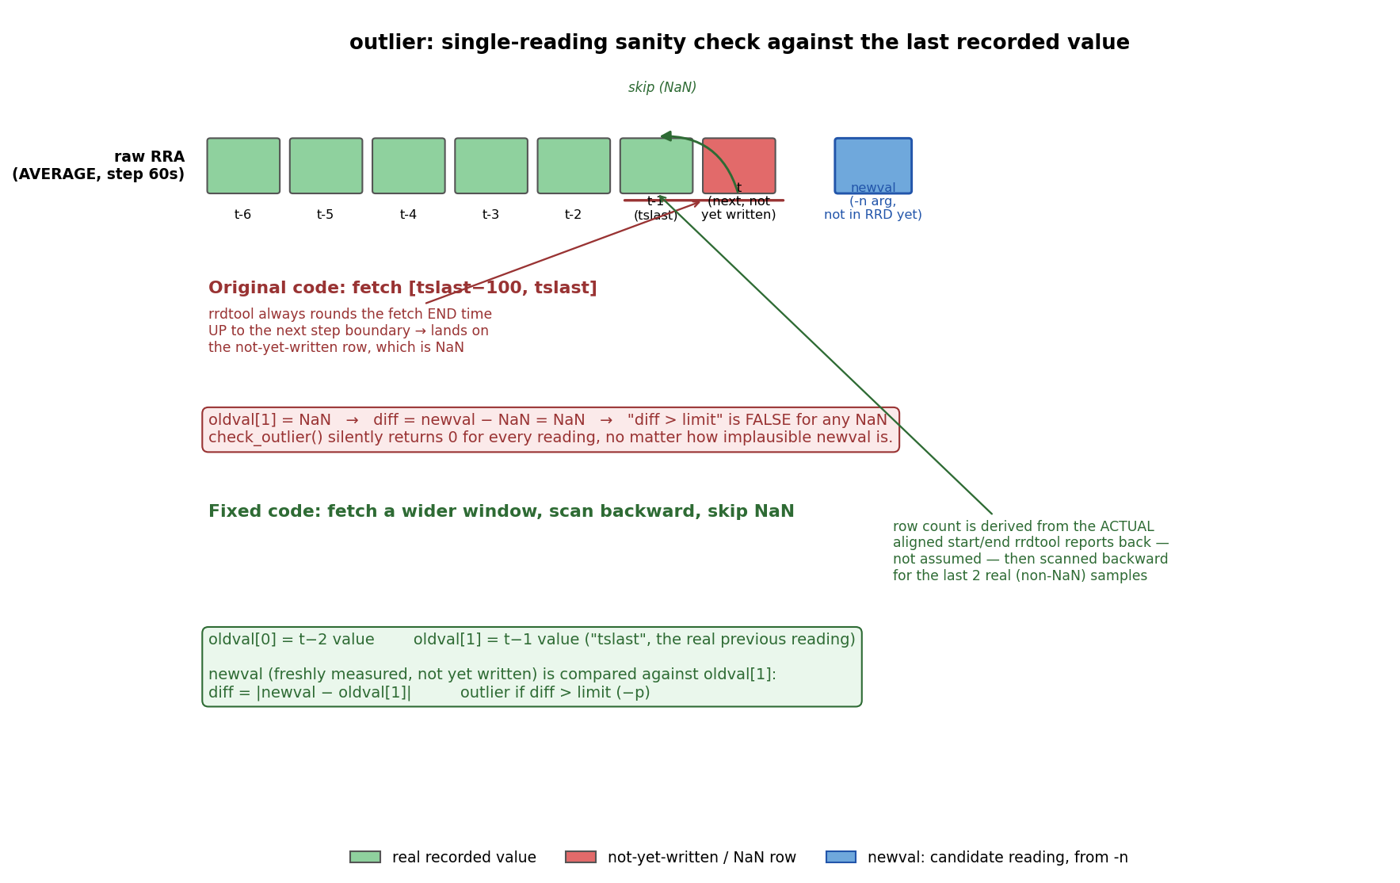
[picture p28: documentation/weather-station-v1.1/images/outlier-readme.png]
outlier detection diagram


## 1. Purpose

`outlier` is meant to run **inline**, as part of the read/write cycle:

1. `getsensor` takes a fresh reading.
2. `outlier` is called with that reading (`-n`) before it's written.
3. If `outlier` returns 1, the caller can choose to retry the sensor read
   (or fall back to a second sensor), instead of ever writing the bad value.

Because of this, `outlier` only ever needs to know about **one previous
value** - the last one actually recorded - not a rolling window.

## 2. What it reads from the RRD

`outlier` doesn't need to know anything about the station's full archive
schema. It only calls `rrd_fetch_r()` with consolidation function
`AVERAGE`, for a short window ending at `rrd_last_r()` (the RRD's
`last_update` timestamp). From that single fetch it gets back both the data
source names (`ds_namv`) - used to resolve which column corresponds to the
`-d` argument - and the values themselves, so no separate lookup of the
database's `DS` list is required.

## 3. Detection method

### 3.1 Fetching the last real value

`rrd_fetch_r()`'s start/end times are always rounded outward to the
archive's step boundaries: **start** rounds down, **end** rounds up. Since
`last_update` is the *exact* wall-clock time of the last `rrdtool update`
call (not necessarily aligned to a clean 60-second boundary), a naive fetch
ending exactly at `last_update` gets rounded up past the real last row and
onto the *next, not-yet-written* row - which is always NaN.

`outlier` fetches a window wide enough to comfortably contain several past
steps, then uses the *actual* aligned start/end/step values that
`rrd_fetch_r()` reports back (not the originally requested ones) to work
out how many rows really came back, and scans backward from the newest row
looking for the most recent 2 non-NaN samples for the requested data
source - skipping over any trailing not-yet-written row.

### 3.2 The comparison

```
diff = | newval − oldval[most recent real value] |
outlier if diff > limit          (limit is the -p argument)
```

`newval` is the value passed on the command line via `-n` - a reading that
hasn't been written to the RRD yet. `oldval` holds the last two genuinely
recorded values for the requested data source (`oldval[1]` being the most
recent); only `oldval[1]` is used in the comparison itself, `oldval[0]` is
fetched as available context for the caller (via `-v`) but isn't required
by the check.

### 3.3 Return code

| Exit code | Meaning |
|---|---|
| 0 | `newval` is within `limit` of the last recorded value - looks fine. |
| 1 | `newval` deviates from the last recorded value by more than `limit` - looks like a bad reading. |
| -1 (255) | Error: bad arguments, can't open the RRD, unknown data source, or not enough valid recent history to compare against. |

## 4. Usage

```
outlier -s <rrd-file> -d <datasource> -n <newvalue> -p <variance> [-v] [-h]
```

```
./outlier -s /opt/raspi/data/am2302.rrd -d temp -n 9.2 -p 5
```

`-v` prints the resolved data-source index, the fetch window actually used,
each row scanned (and whether it was skipped as NaN), and the final
diff/limit comparison.

## 5. Known limitations

- A single fixed `-p` variance is used regardless of time of day or season;
  a fast but legitimate change (e.g. right at sunrise) close to the
  threshold could in principle be flagged. Unlike `fix-weatherdb`, there's
  no rolling multi-sample baseline here by design - it's meant to be a fast,
  stateless, single-reading gate, not a historical-data repair pass.
- If the RRD doesn't yet have 2 valid recorded values to compare against
  (e.g. right after creation, or after a long prior outage), `outlier` exits
  with an error rather than a pass/fail verdict - the caller should treat
  that as "can't judge yet", not as "value accepted".

# 6. Reference

There is also the more sphisticated program `fix-weatherdb`, which repairs
measurement faults that made it into the RRD database. `fix-weatherdb` uses
a rolling multi-sample baseline for higher accuracy of failure detection.
The detection method can be standardized between the two eventually.

For now, this program and `fix-weatherdb`'s raw-resolution outlier check are
intentionally different in method (single-previous-value vs. rolling
baseline) and use separate threshold values, to avoid cascading changes
to scripts that depend on `outlier`'s existing `-p` argument and behaviour.

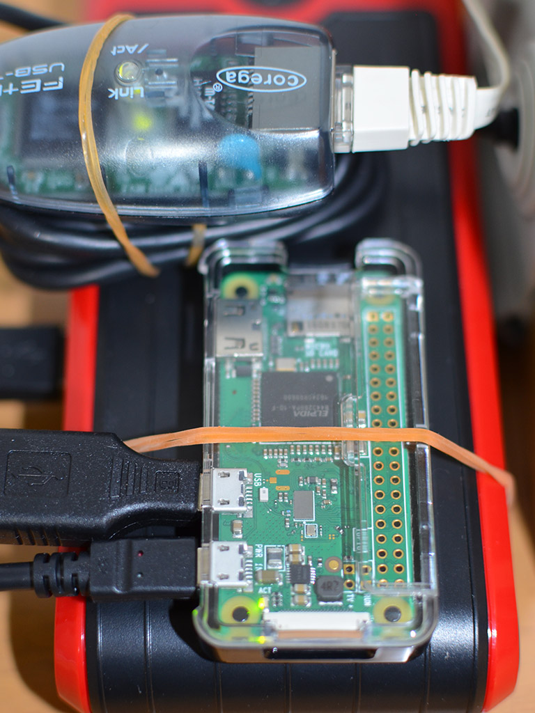
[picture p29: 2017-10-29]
documentation/weather-station-v1.1/images/weather-station-v11-06.jpg

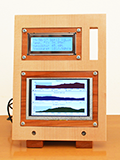
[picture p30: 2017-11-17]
weather-web/web/img/weather-display-v10-05s.png

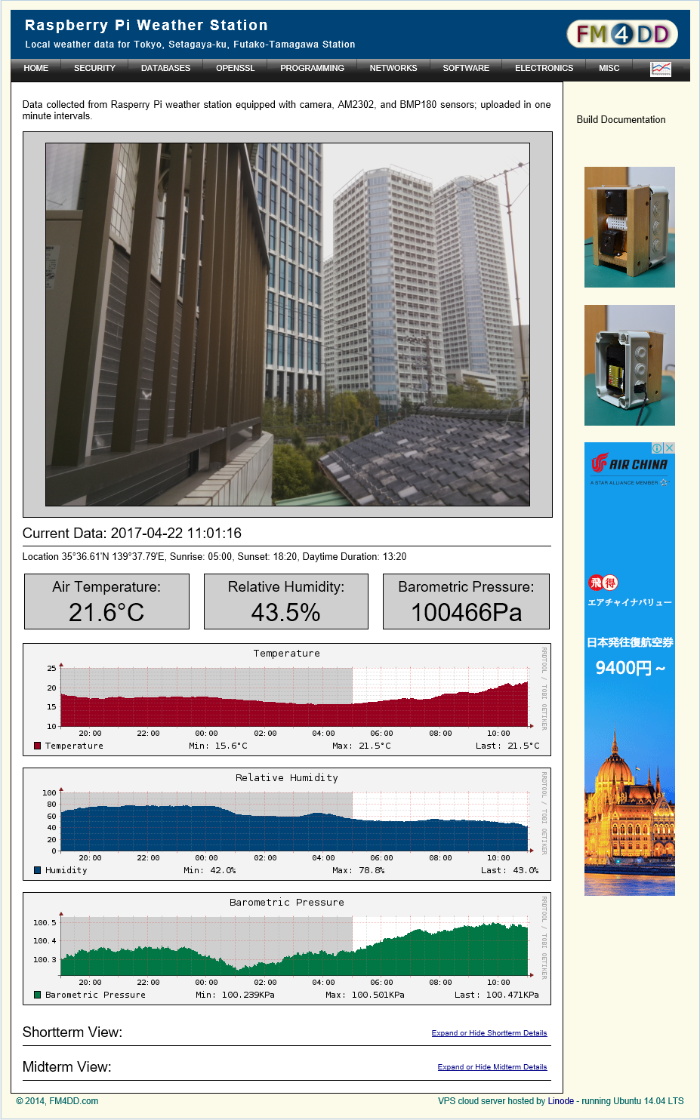
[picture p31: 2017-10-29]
documentation/weather-web-v1.0/images/weather-web-v10-02.png

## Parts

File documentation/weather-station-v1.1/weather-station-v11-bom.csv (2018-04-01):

Quantity | Description | Distributer | Distributer P/N | Manufacturer | Manufacturer P/N | Price/Unit | Price Total | Currency | Notes
1 | Waterproof Junction Box T100 | conrad.de | 394654-62 | OBO Bettermann | 2007077 | 14.99 | 2000 | YEN | 14.99 EUR
1 | Inner Frame Standoff Sakura | Tokyu Hands | 200x15x15 | n/a | n/a | 120 | 120 | YEN
1 | Inner Frame Top Cross Sakura | Tokyu Hands | 160x110x15 | n/a | n/a | 270 | 270 | YEN
2 | Sensor Frame Side Panel Sakura | Tokyu Hands | 150x50x15 | n/a | n/a | 180 | 360 | YEN
1 | Sensor Frame Back Panel Sakura | Tokyu Hands | 150x110x15 | n/a | n/a | 240 | 240 | YEN
1 | Sensor Frame Camera Mount Sakura | Tokyu Hands | 68x30x15 | n/a | n/a | 0 | 0 | YEN | material included in back panel
1 | Sensor Frame Roof Panel Acryl Clear 2mm | Tokyu Hands | 100x55x2 | n/a | n/a | 200 | 200 | YEN
1 | Clear Lack Spray 100ml | Tokyu Hands | Tamiya TS13 | Tamiya | 85013 | 640 | 640 | YEN
8 | Tapping Screws 4x20 bag | Tokyu Hands | 4979874452283 | n/a | n/a | 200 | 200 | YEN
4 | Tapping Screws 4x12 bag | Tokyu Hands | 4x12 | n/a | n/a | 200 | 200 | YEN
2 | Washer 8/4x0.5 bag | Tokyu Hands | 8/4x0.5 | n/a | n/a | 50 | 50 | YEN
1 | Raspberry Pi 3 | Akizuki Denshi | M-10414 | Element 14 | n/a | 5600 | 5600 | YEN
1 | Raspi3 Heatsink Set | Akizuki Denshi | P-09282 | Seed Studio | n/a | 100 | 100 | YEN
1 | 64GB MicroSD card | Amazon JP | B01H3R8LCG | Samsung | MB-MC64DA | 2900 | 2900 | YEN
1 | Raspberry Pi Case | Akizuki Denshi | P-10364 | RS Components | n/a | 1280 | 1280 | YEN
1 | USB Cable A-microB 1 | Akizuki Denshi | C-07607 | Xiamen | GYAYM-UB04002 | 120 | 120 | YEN
1 | Power Supply 5V 2A | Akizuki Denshi | M-08310 | Xiamen | AD-P50B200 | 580 | 580 | YEN
1 | Raspberry Pi Camera v2 | Akizuki Denshi | M-10518 | RS Components | n/a | 4300 | 4300 | YEN
1 | Raspberry Pi Camera Case Black | Sengoku | EEHD-4RL7 | SparkFun | PRT-12846 | 1280 | 1280 | YEN
1 | Pin Frame 2x7 | Akizuki Denshi | C-00169 | Useconn Electronics | n/a | 30 | 30 | YEN
1 | Universal Prototyping Board | Akizuki Denshi | P-04303 | Picotec | n/a | 80 | 80 | YEN
2 | Pin Frame 1x6 | Akizuki Denshi | C-03784 | n/a | n/a | 20 | 40 | YEN
1 | I2C Sensor AE-BME280 | Akizuki Denshi | K-09421 | Akizuki Electronics | n/a | 1080 | 1080 | YEN
1 | Sensor Case 25x15x5 | Akizuki Denshi | P-12045 | Takachi | TW5-3-5G | 150 | 150 | YEN
1 | Ribbon Cable 10-wire | Akizuki Denshi | C-06973 | Herwell Asia Limited | n/a | 60 | 60 | YEN
1 | Universal Board | Marutsu | TNF2535 | Takachi | TNF 25-35 | 120 | 120 | YEN
 |  |  |  |  |  | total | 21900 | YEN

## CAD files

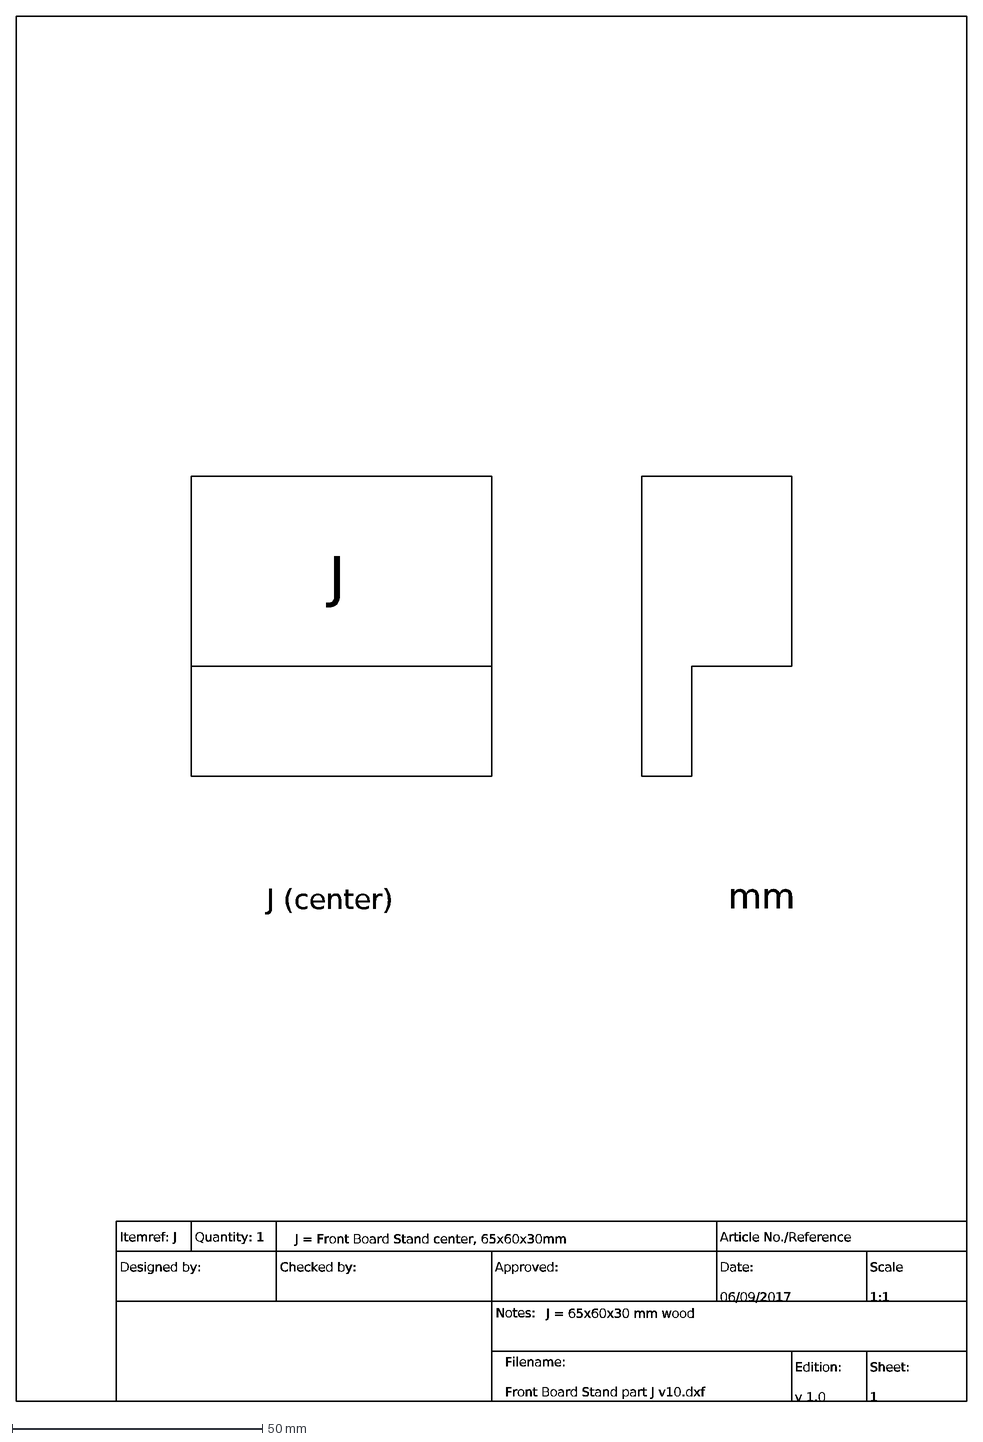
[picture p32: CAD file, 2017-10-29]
documentation/weather-display-v1.0/cad/07 Front Board Stand part J v10.dxf
Itemref: J
Quantity: 1
J = Front Board Stand center, 65x60x30mm
Article No./Reference
Designed by:
Checked by:
Approved:
Filename: Front Board Stand part J v10.dxf
Date: 06/09/2017
Scale 1:1
Edition: v 1.0
Sheet: 1
J = 65x60x30 mm wood
Notes:
mm
J (center)
J

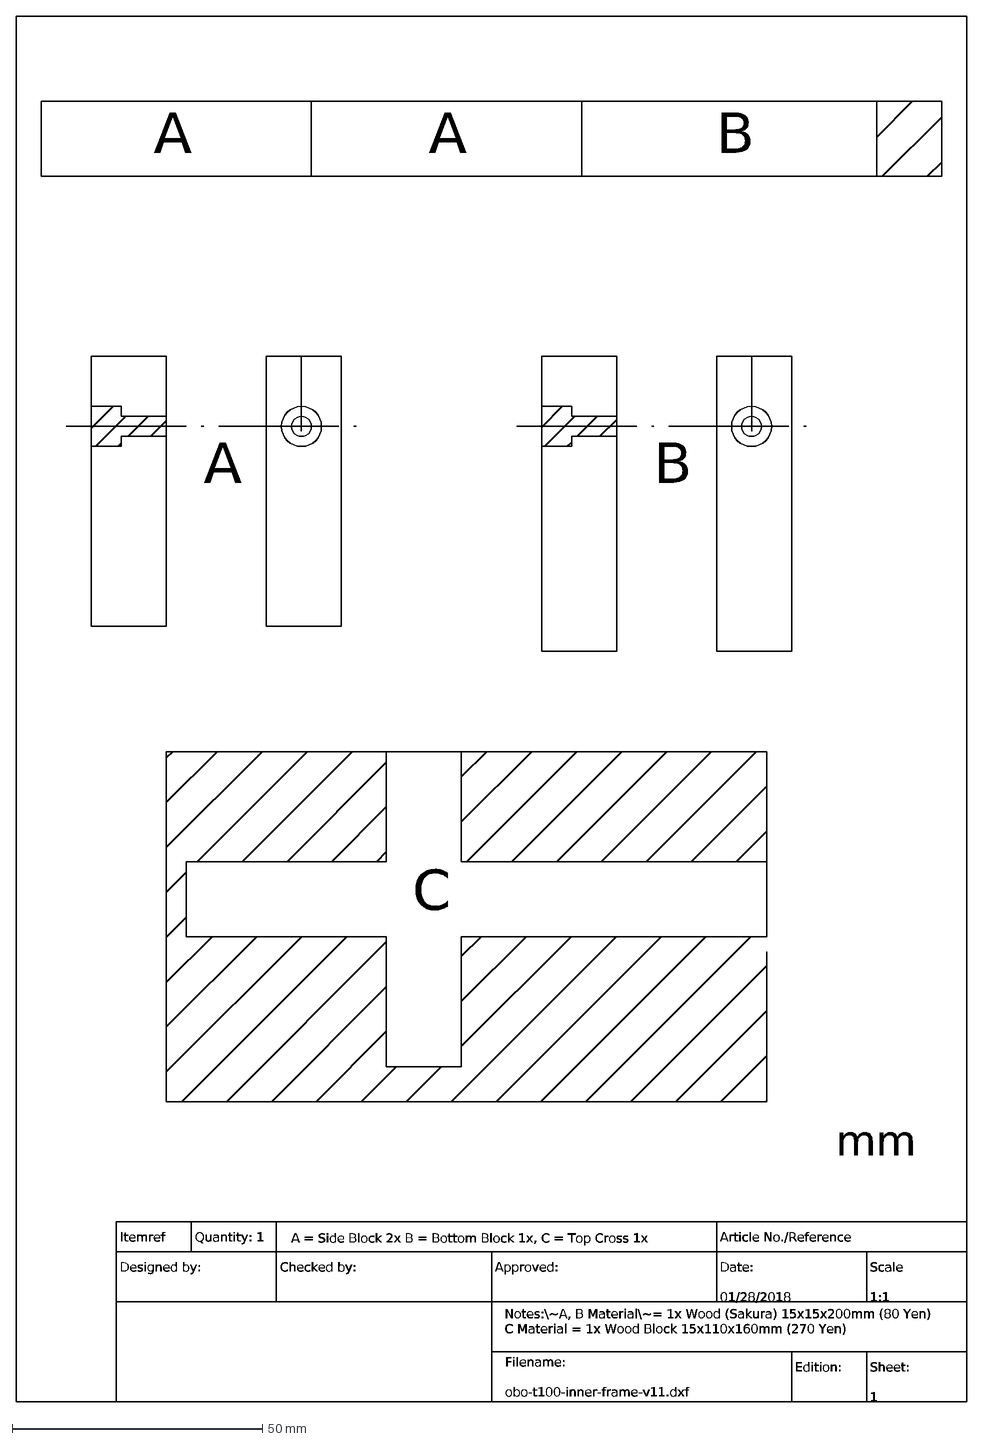
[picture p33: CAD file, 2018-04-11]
documentation/weather-station-v1.1/cad/obo-t100-inner-frame-v11.dxf
Itemref
Quantity: 1
A = Side Block 2x B = Bottom Block 1x, C = Top Cross 1x
Article No./Reference
Designed by:
Checked by:
Approved:
Filename: obo-t100-inner-frame-v11.dxf
Date: 01/28/2018
Scale 1:1
Edition:\p v 1.0
Sheet: 1
Notes:\~A, B Material\~= 1x Wood (Sakura) 15x15x200mm (80 Yen) C Material = 1x Wood Block 15x110x160mm (270 Yen)
A
C
B
mm

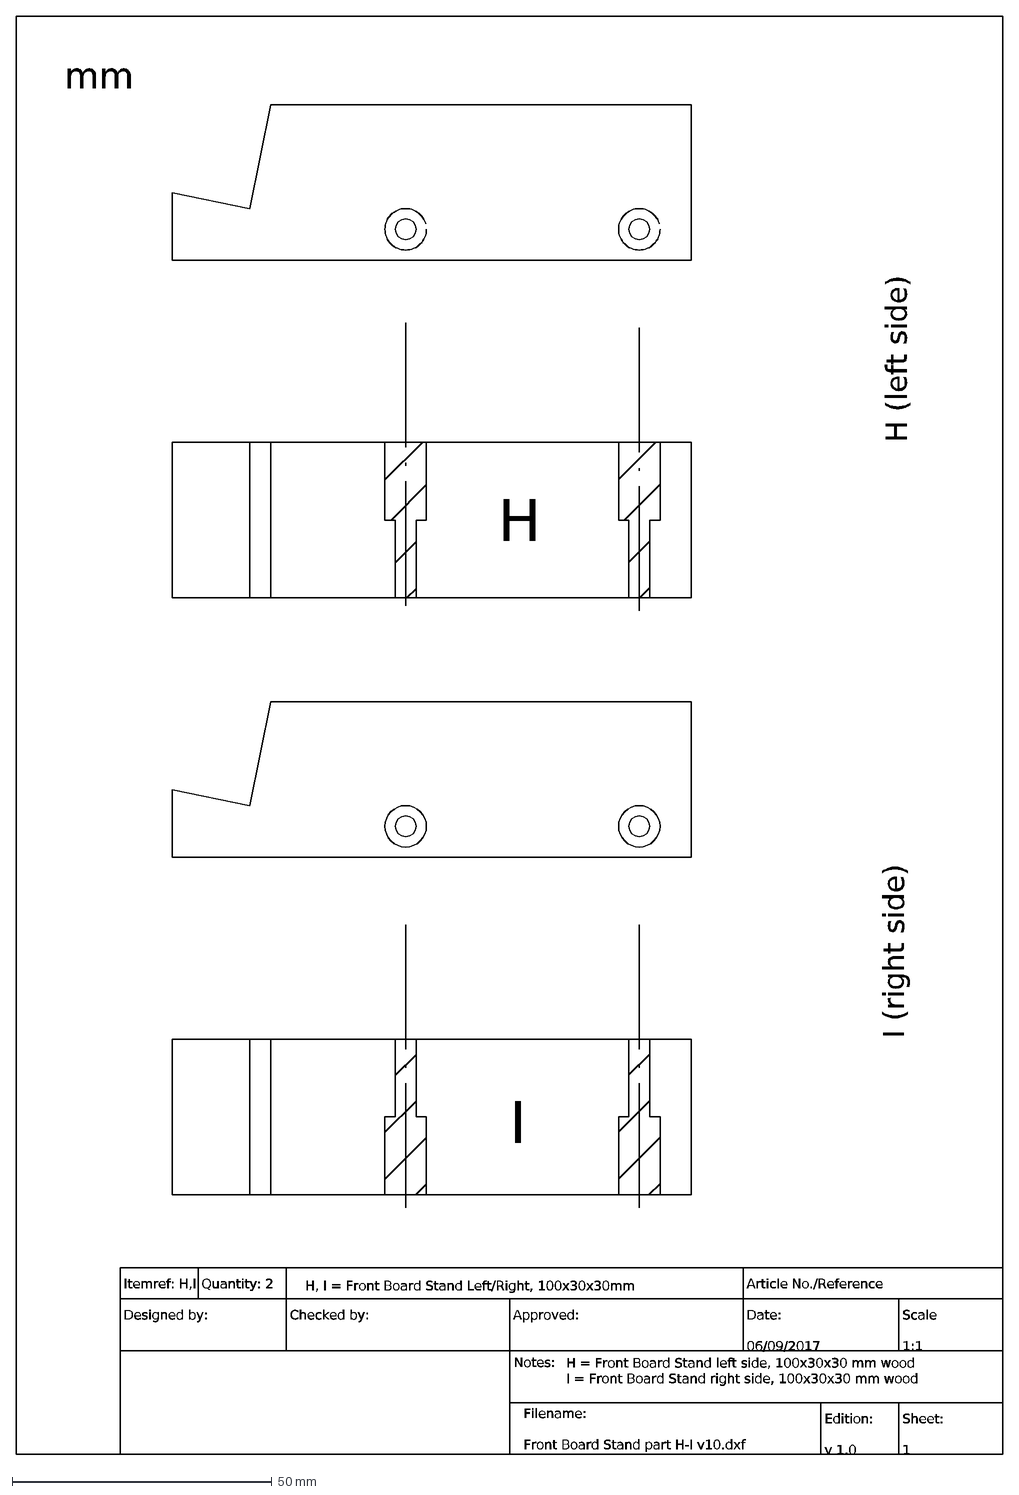
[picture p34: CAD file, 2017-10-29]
documentation/weather-display-v1.0/cad/06 Front Board Stand part H-I v10.dxf
Itemref: H,I
Quantity: 2
H, I = Front Board Stand Left/Right, 100x30x30mm
Article No./Reference
Designed by:
Checked by:
Approved:
Filename: Front Board Stand part H-I v10.dxf
Date: 06/09/2017
Scale 1:1
Edition: v 1.0
Sheet: 1
H = Front Board Stand left side, 100x30x30 mm wood I = Front Board Stand right side, 100x30x30 mm wood
Notes:
mm
I (right side)
I
H
H (left side)

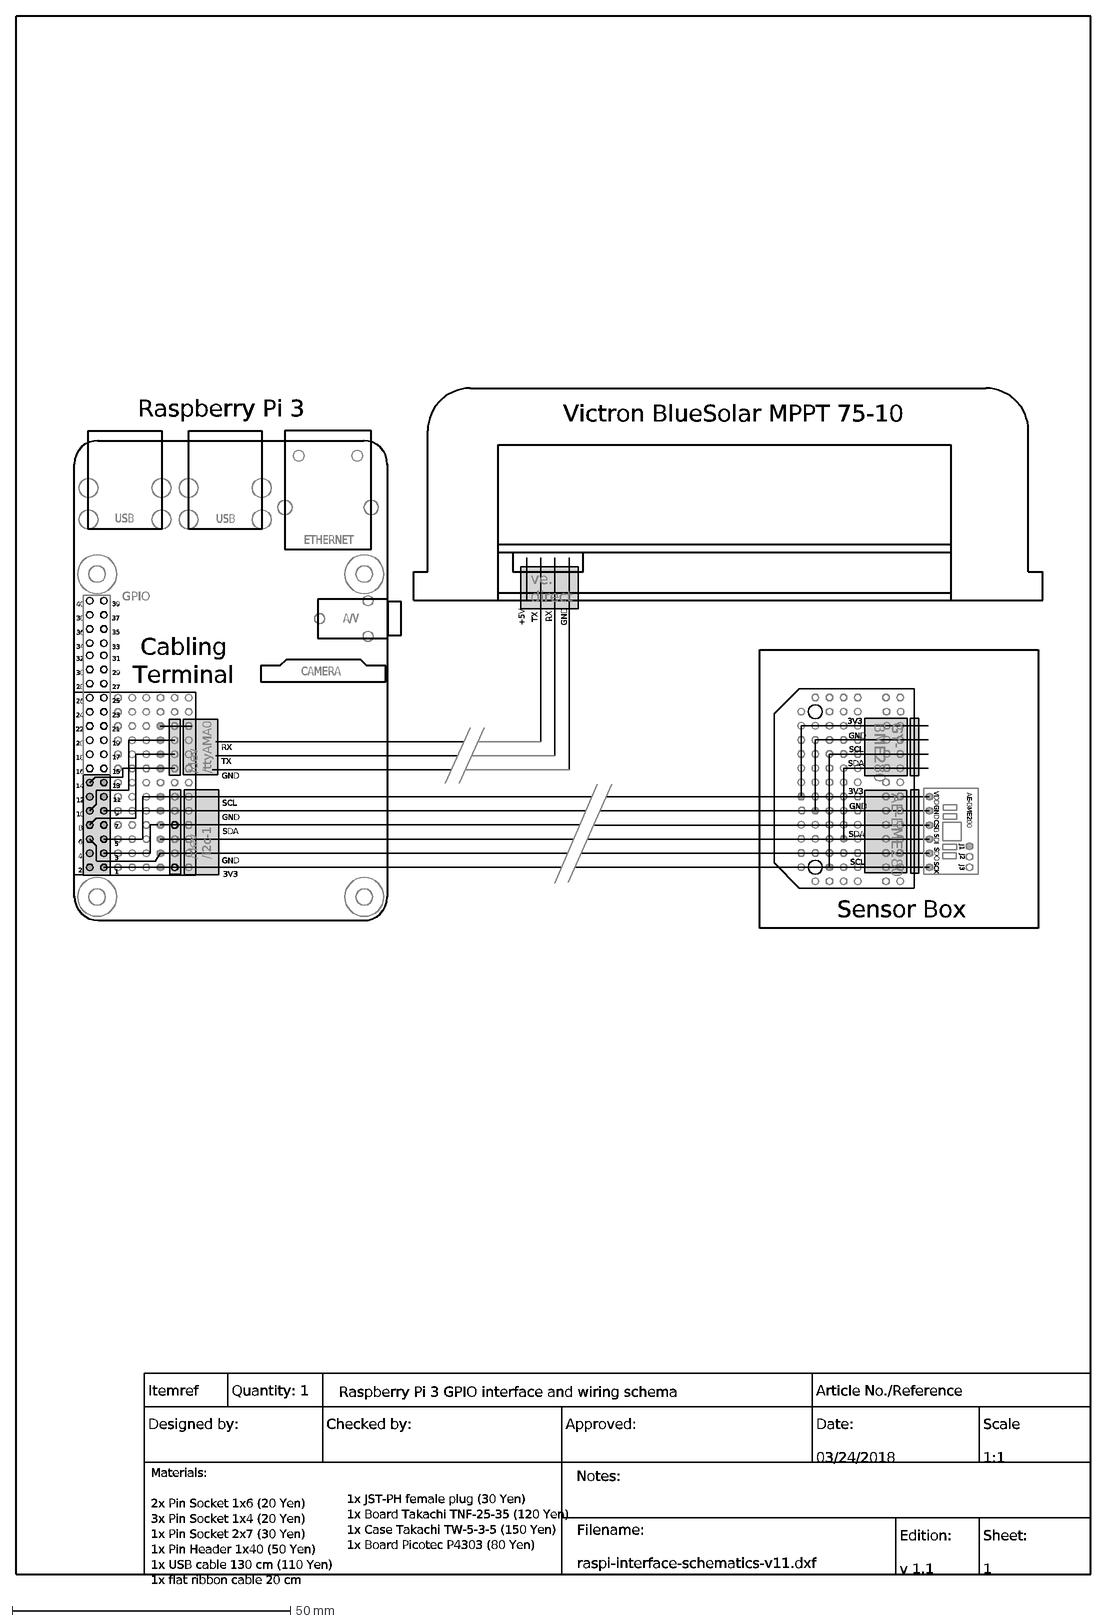
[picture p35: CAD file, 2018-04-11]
documentation/weather-station-v1.1/cad/raspi-interface-schematics-v11.dxf
Itemref
Quantity: 1
Raspberry Pi 3 GPIO interface and wiring schema
Article No./Reference
Designed by:
Checked by:
Approved:
Filename: raspi-interface-schematics-v11.dxf
Date: 03/24/2018
Scale 1:1
Edition: v 1.1
Sheet: 1
Notes:
Materials: 2x Pin Socket 1x6 (20 Yen) 3x Pin Socket 1x4 (20 Yen) 1x Pin Socket 2x7 (30 Yen) 1x Pin Header 1x40 (50 Yen) 1x USB cable 130 cm (110 Yen) 1x flat ri
1x JST-PH female plug (30 Yen) 1x Board Takachi TNF-25-35 (120 Yen) 1x Case Takachi TW-5-3-5 (150 Yen) 1x Board Picotec P4303 (80 Yen)
SDA
SCL
SCK
SDO
SDI
CSB
GND
VDD
J1
J2
J3
AE-BME280
3V3
TX
RX
+5V
26
25
23
24
29
30
28
27
32
34
36
38
40
31
33
35
37
39
2
4
15
17
10
12
6
8
18
14
16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

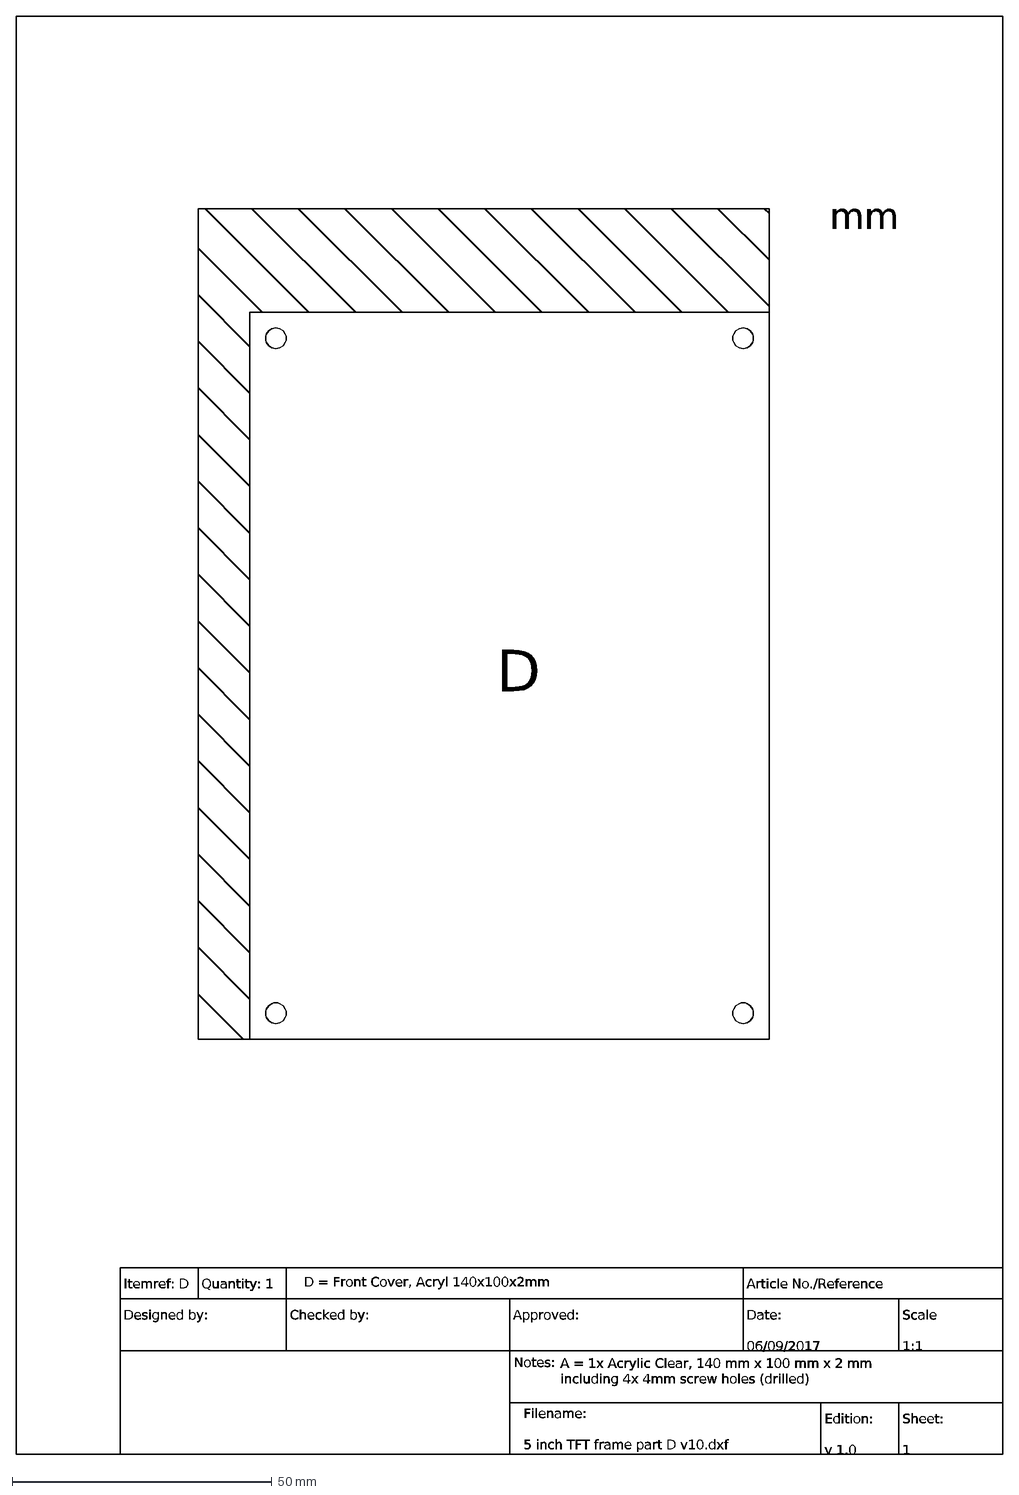
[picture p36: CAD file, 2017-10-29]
documentation/weather-display-v1.0/cad/03 5 inch TFT frame part D v10.dxf
Itemref: D
Quantity: 1
D = Front Cover, Acryl 140x100x2mm
Article No./Reference
Designed by:
Checked by:
Approved:
Filename: 5 inch TFT frame part D v10.dxf
Date: 06/09/2017
Scale 1:1
Edition: v 1.0
Sheet: 1
A = 1x Acrylic Clear, 140 mm x 100 mm x 2 mm including 4x 4mm screw holes (drilled)
Notes:
mm
D

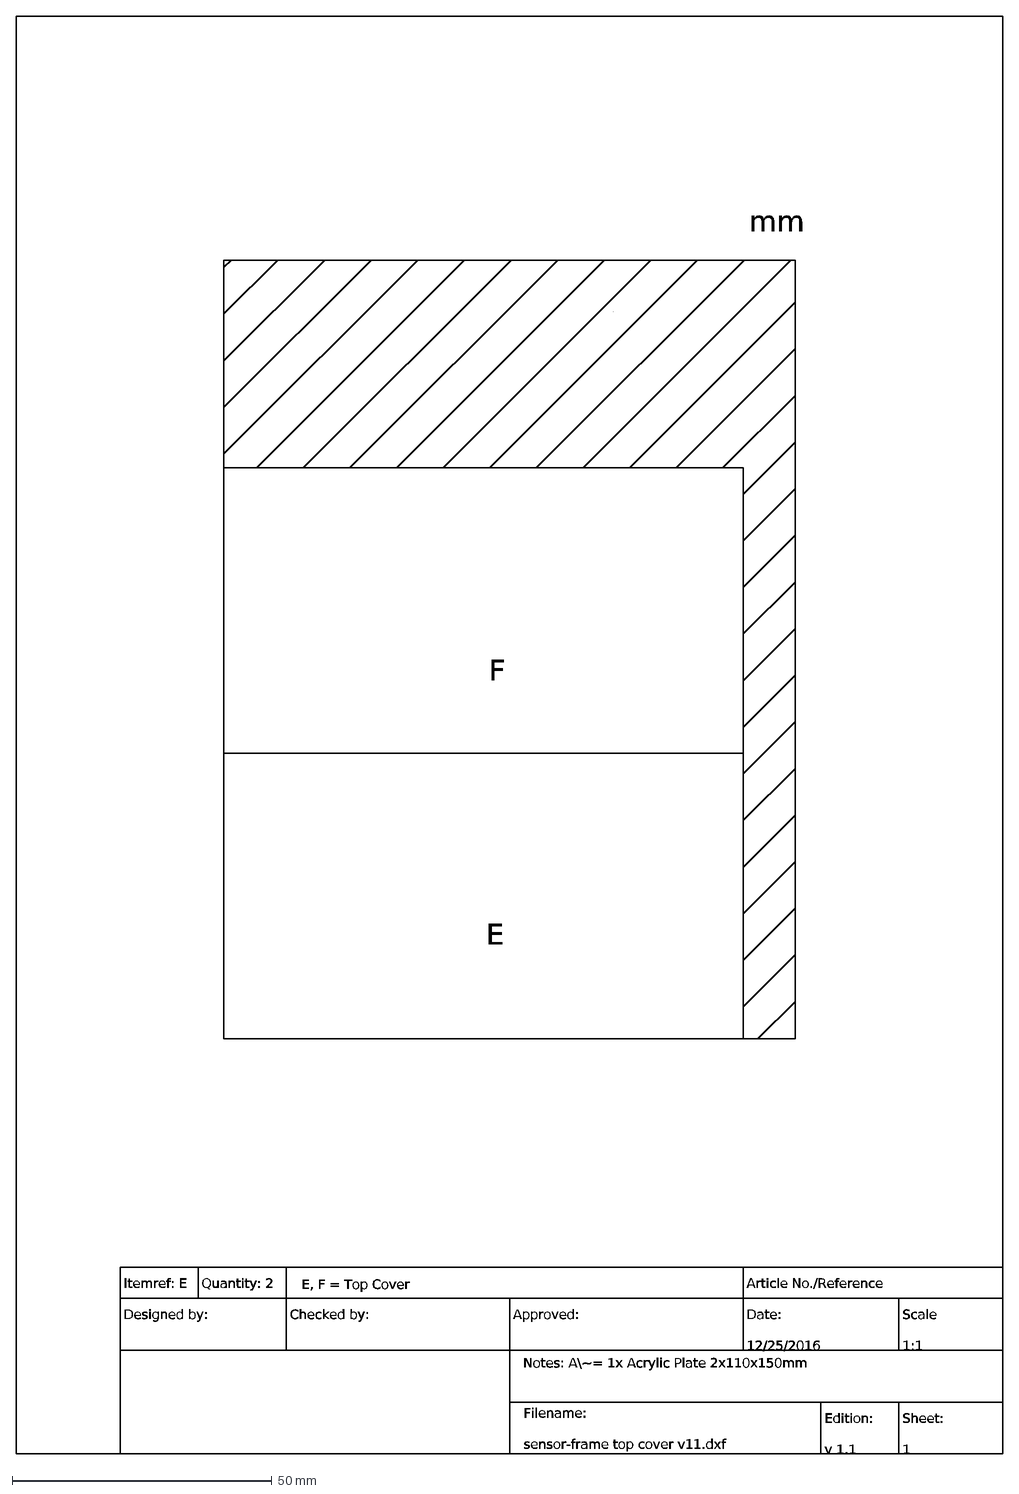
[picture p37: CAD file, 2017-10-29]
documentation/weather-station-v1.1/cad/sensor-frame top cover v11.dxf
Itemref: E
Quantity: 2
E, F = Top Cover
Article No./Reference
Designed by:
Checked by:
Approved:
Filename: sensor-frame top cover v11.dxf
Date: 12/25/2016
Scale 1:1
Edition: v 1.1
Sheet: 1
Notes: A\~= 1x Acrylic Plate 2x110x150mm
F
mm
E

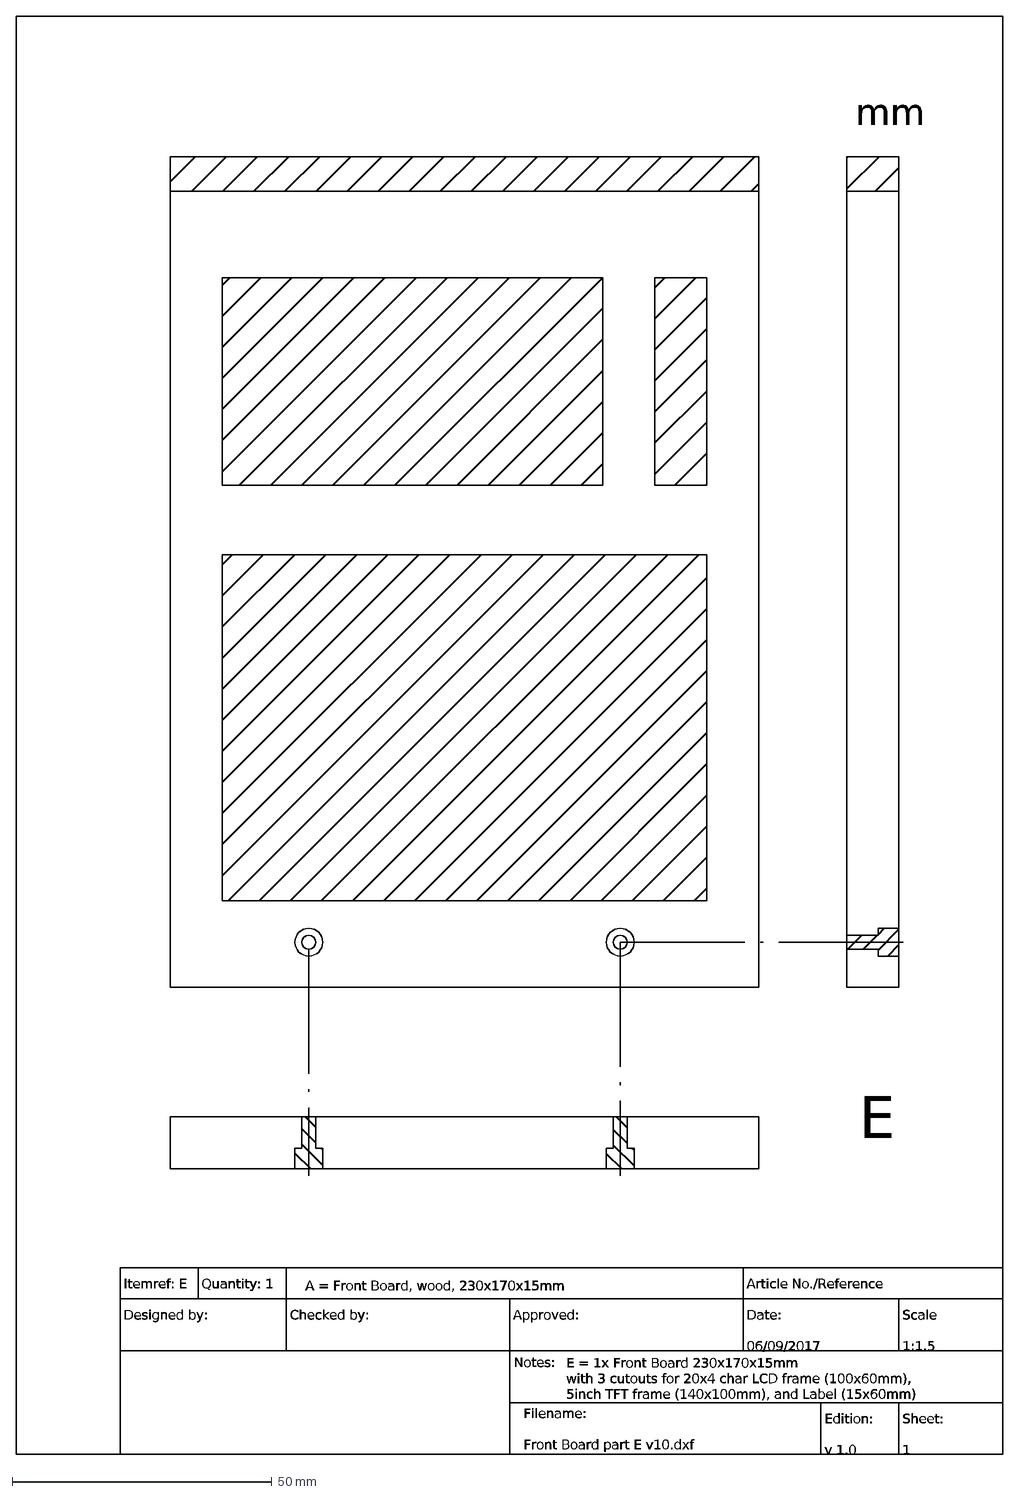
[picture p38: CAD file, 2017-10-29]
documentation/weather-display-v1.0/cad/04 Front Board part E v10.dxf
Itemref: E
Quantity: 1
A = Front Board, wood, 230x170x15mm
Article No./Reference
Designed by:
Checked by:
Approved:
Filename: Front Board part E v10.dxf
Date: 06/09/2017
Scale 1:1.5
Edition: v 1.0
Sheet: 1
E = 1x Front Board 230x170x15mm with 3 cutouts for 20x4 char LCD frame (100x60mm), 5inch TFT frame (140x100mm), and Label (15x60mm)
Notes:
mm
E

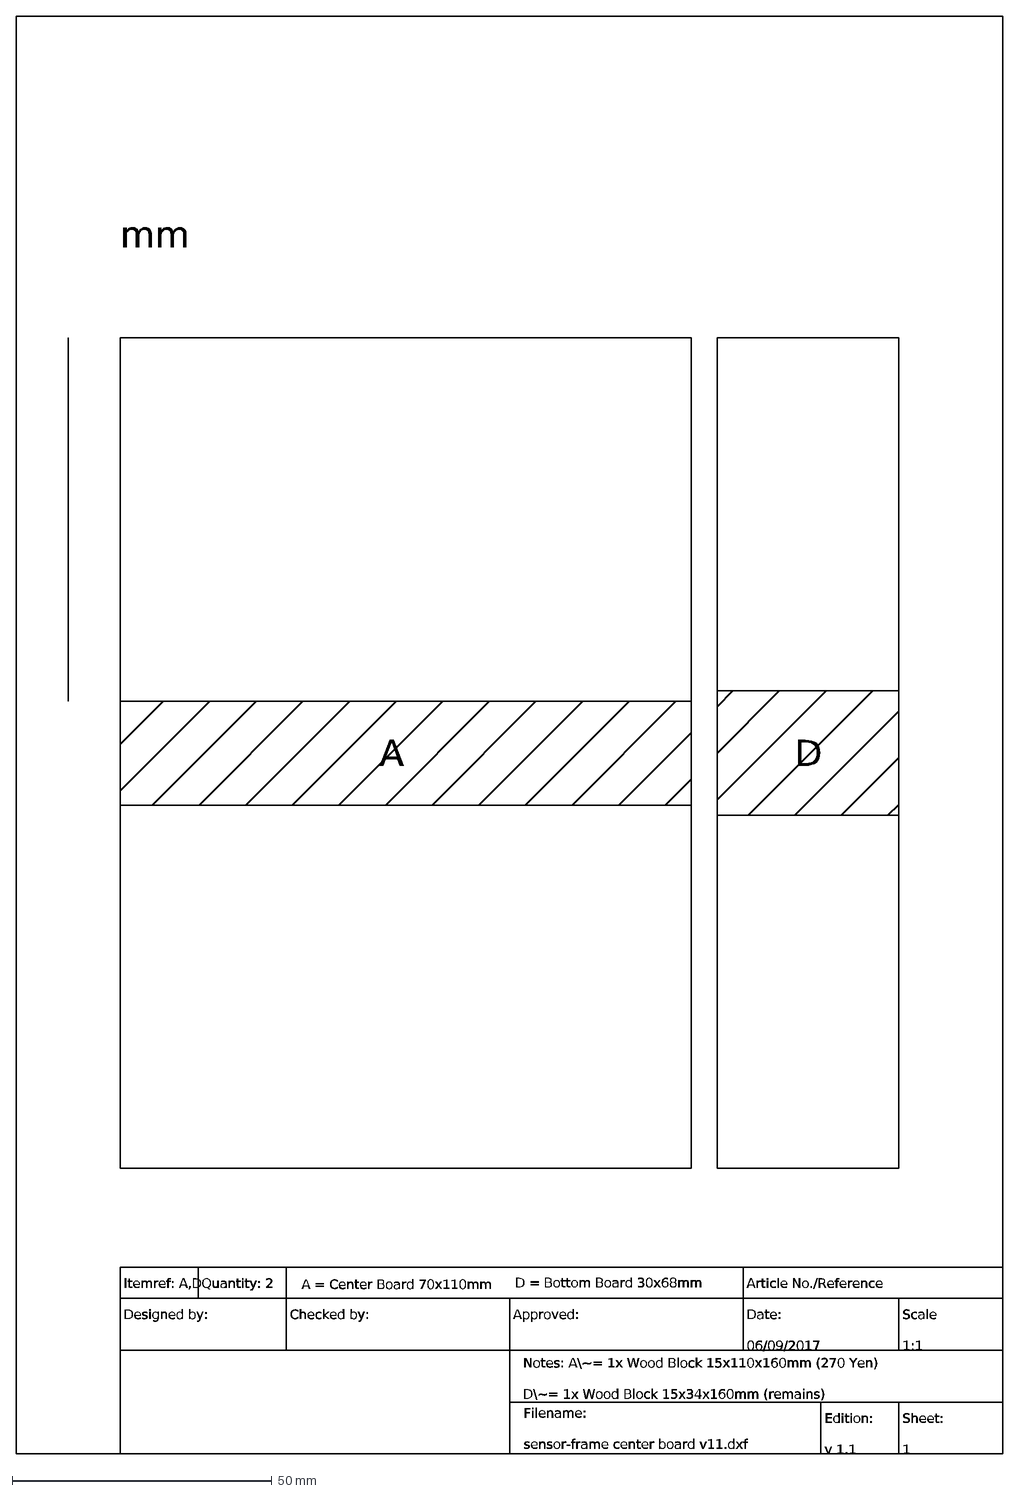
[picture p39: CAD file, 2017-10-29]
documentation/weather-station-v1.1/cad/sensor-frame center board v11.dxf
Itemref: A,D
Quantity: 2
D = Bottom Board 30x68mm
A = Center Board 70x110mm
Article No./Reference
Designed by:
Checked by:
Approved:
Filename: sensor-frame center board v11.dxf
Date: 06/09/2017
Scale 1:1
Edition: v 1.1
Sheet: 1
Notes: A\~= 1x Wood Block 15x110x160mm (270 Yen) D\~= 1x Wood Block 15x34x160mm (remains)
mm
D
A

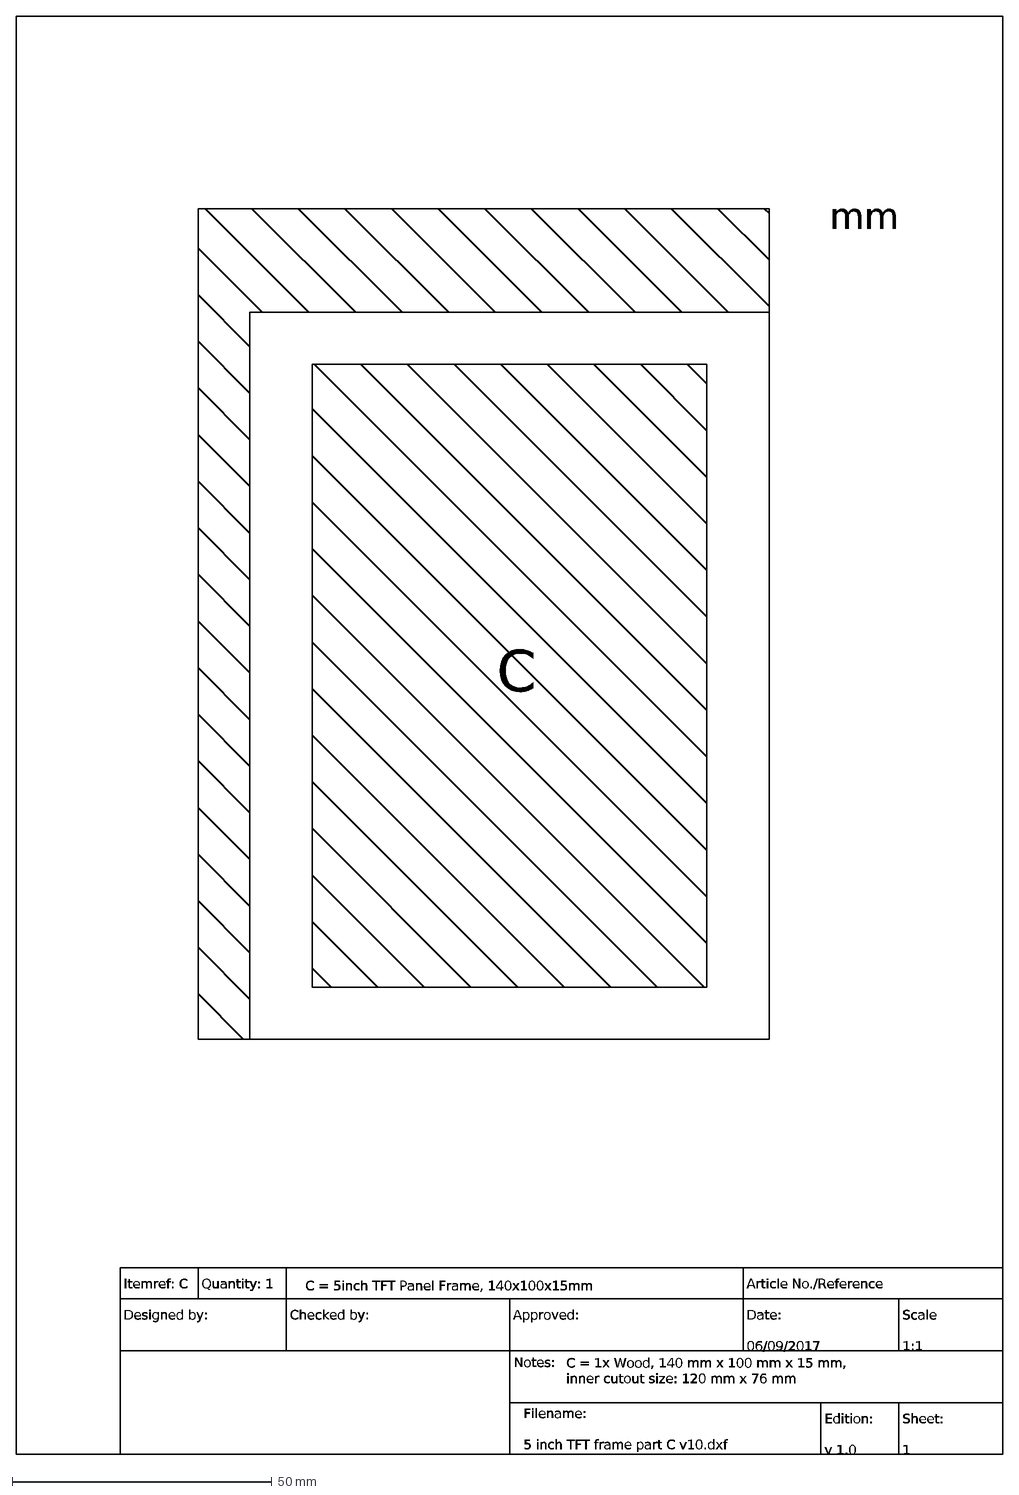
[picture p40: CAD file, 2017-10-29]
documentation/weather-display-v1.0/cad/02 5 inch TFT frame part C v10.dxf
Itemref: C
Quantity: 1
C = 5inch TFT Panel Frame, 140x100x15mm
Article No./Reference
Designed by:
Checked by:
Approved:
Filename: 5 inch TFT frame part C v10.dxf
Date: 06/09/2017
Scale 1:1
Edition: v 1.0
Sheet: 1
C = 1x Wood, 140 mm x 100 mm x 15 mm, inner cutout size: 120 mm x 76 mm
Notes:
mm
C

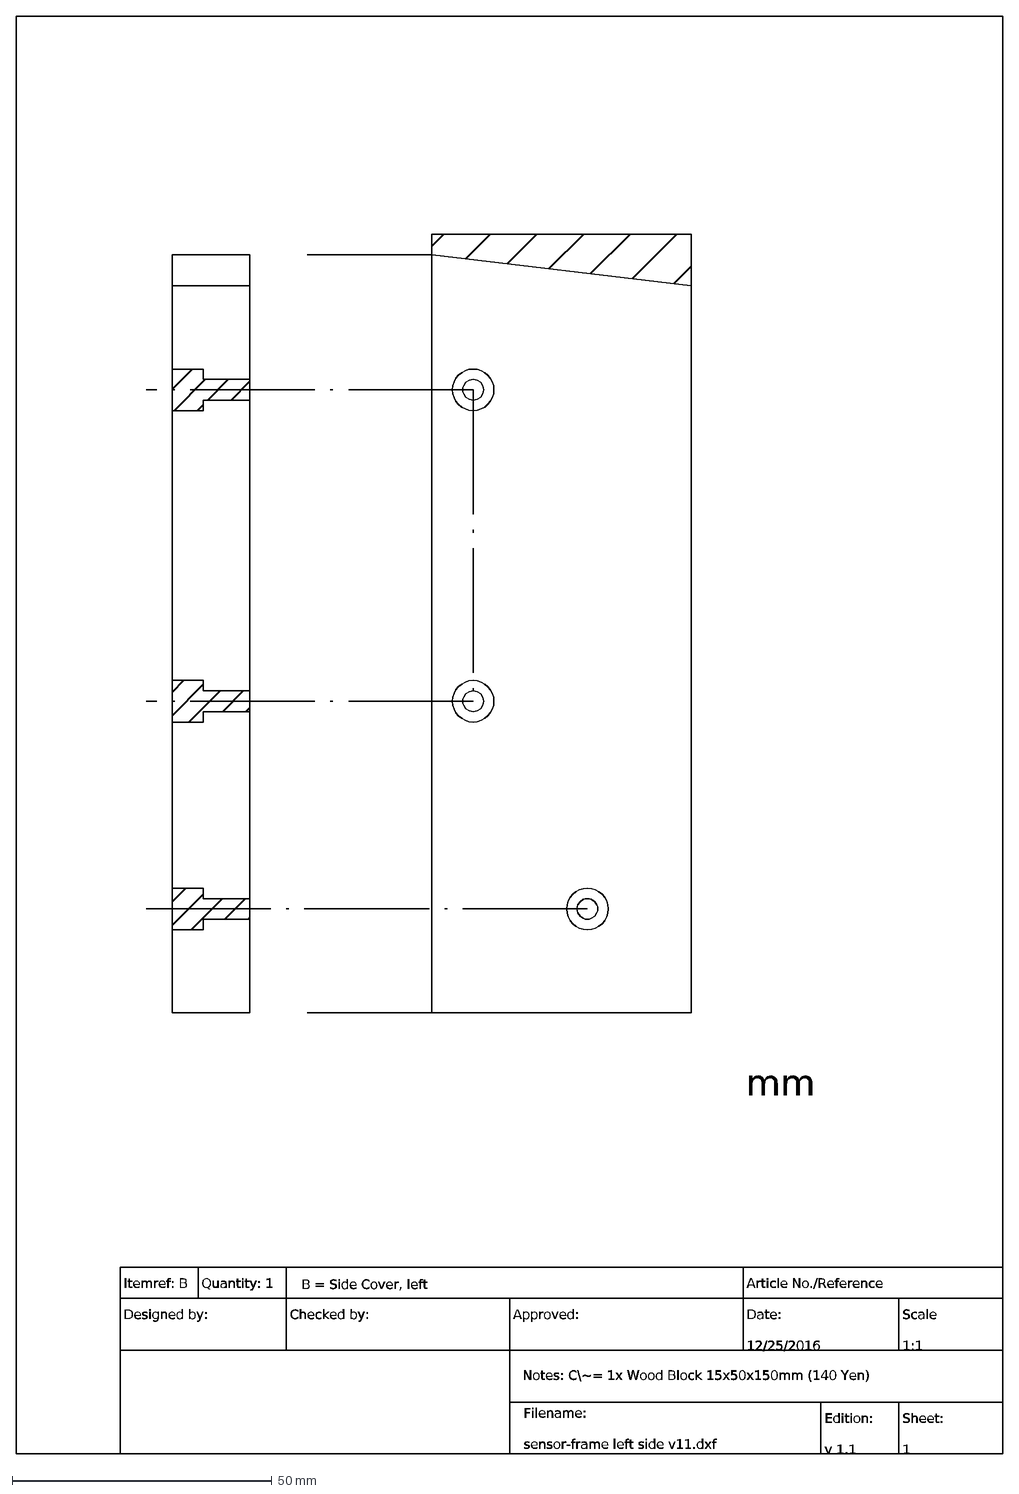
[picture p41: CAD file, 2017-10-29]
documentation/weather-station-v1.1/cad/sensor-frame left side v11.dxf
Itemref: B
Quantity: 1
B = Side Cover, left
Article No./Reference
Designed by:
Checked by:
Approved:
Filename: sensor-frame left side v11.dxf
Date: 12/25/2016
Scale 1:1
Edition: v 1.1
Sheet: 1
Notes: C\~= 1x Wood Block 15x50x150mm (140 Yen)
mm

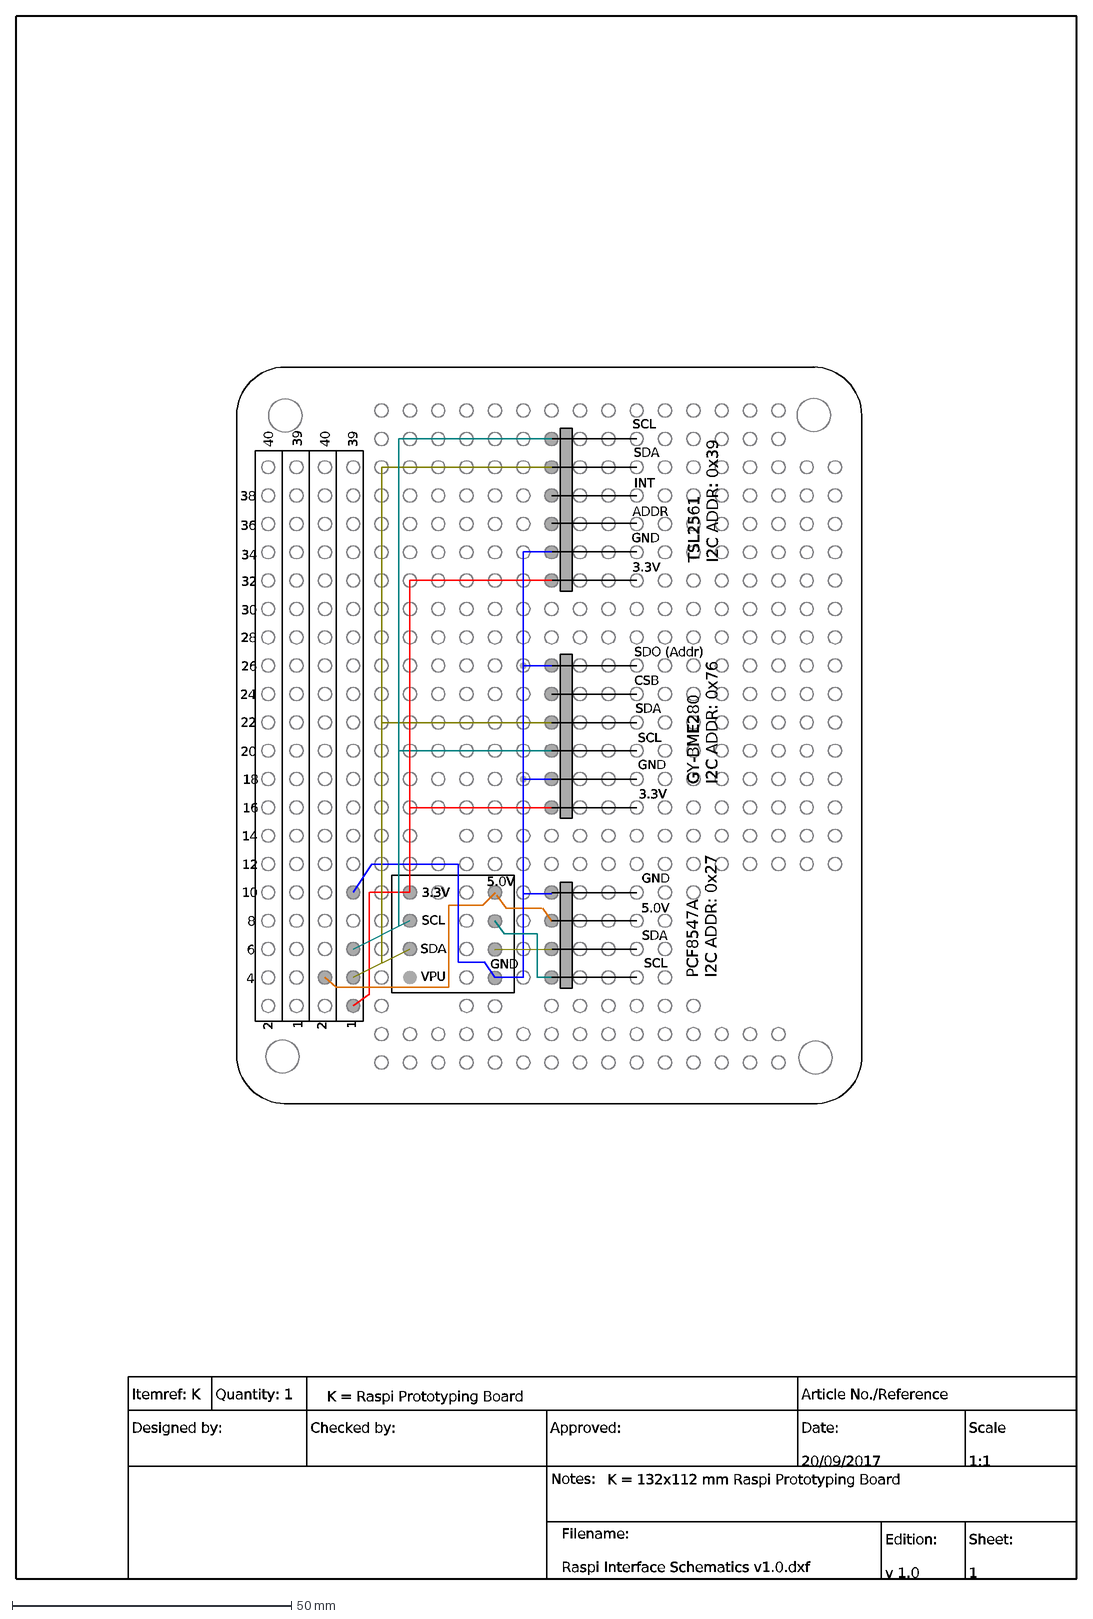
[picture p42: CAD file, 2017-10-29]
documentation/weather-display-v1.0/cad/08 Raspi Interface Schematics K v10.dxf
Itemref: K
Quantity: 1
K = Raspi Prototyping Board
Article No./Reference
Designed by:
Checked by:
Approved:
Filename: Raspi Interface Schematics v1.0.dxf
Date: 20/09/2017
Scale 1:1
Edition: v 1.0
Sheet: 1
K = 132x112 mm Raspi Prototyping Board
Notes:
26
24
30
28
40
GND
INT
ADDR
SCL
SDA
3.3V
VPU
5.0V
SDO (Addr)
CSB
38
36
34
39
32
2
4
10
12
6
8
18
14
16
20
22
1
PCF8547A I2C ADDR: 0x27
TSL2561 I2C ADDR: 0x39
GY-BME280 I2C ADDR: 0x76

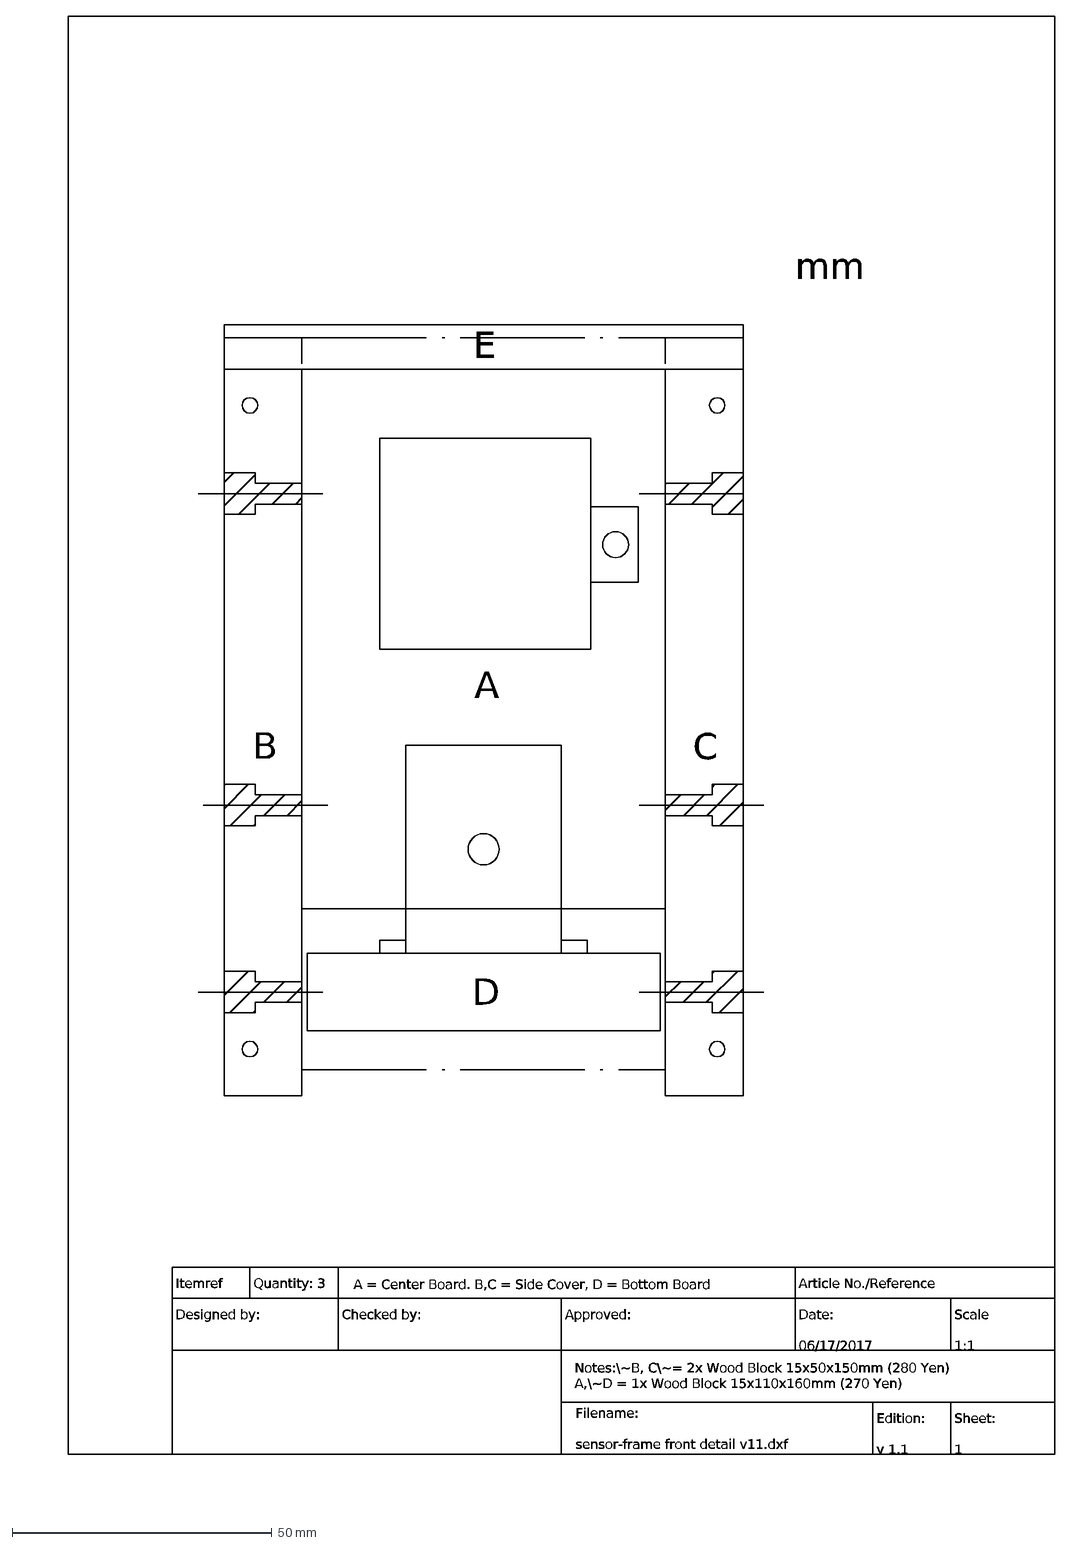
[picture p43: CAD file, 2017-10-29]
documentation/weather-station-v1.1/cad/sensor-frame front detail v11.dxf
Itemref
Quantity: 3
A = Center Board. B,C = Side Cover, D = Bottom Board
Article No./Reference
Designed by:
Checked by:
Approved:
Filename: sensor-frame front detail v11.dxf
Date: 06/17/2017
Scale 1:1
Edition: v 1.1
Sheet: 1
Notes:\~B, C\~= 2x Wood Block 15x50x150mm (280 Yen) A,\~D = 1x Wood Block 15x110x160mm (270 Yen)
A
C
B
D
E
mm

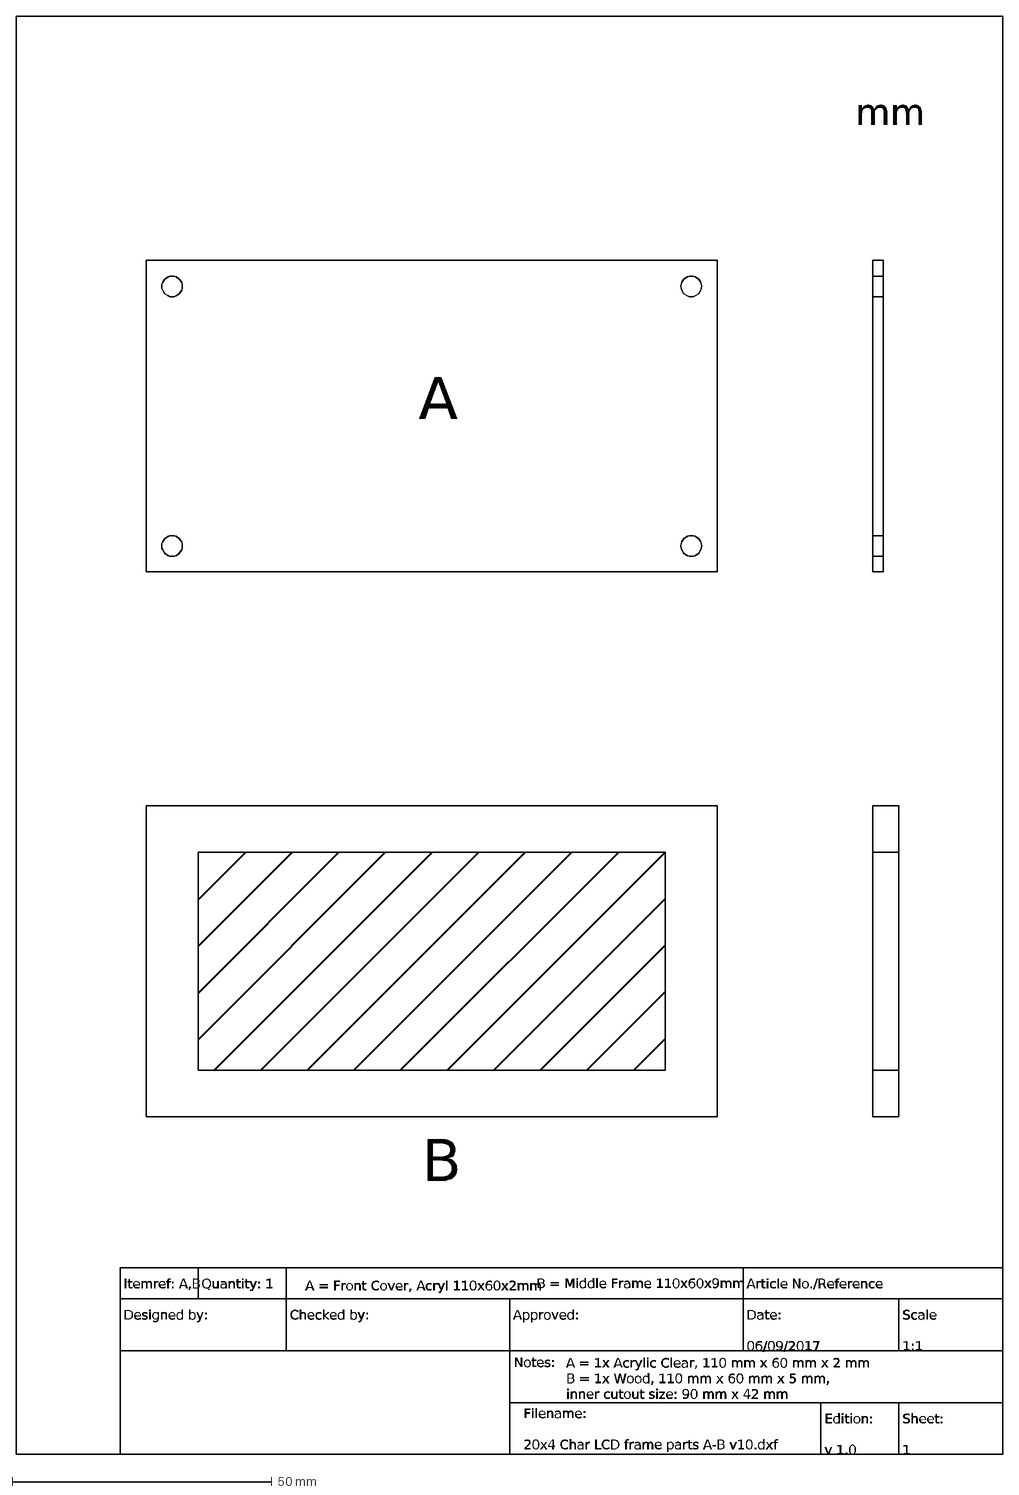
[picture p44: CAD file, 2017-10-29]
documentation/weather-display-v1.0/cad/01 20x4 Char LCD frame parts A-B v10.dxf
Itemref: A,B
Quantity: 1
B = Middle Frame 110x60x9mm
A = Front Cover, Acryl 110x60x2mm
Article No./Reference
Designed by:
Checked by:
Approved:
Filename: 20x4 Char LCD frame parts A-B v10.dxf
Date: 06/09/2017
Scale 1:1
Edition: v 1.0
Sheet: 1
A = 1x Acrylic Clear, 110 mm x 60 mm x 2 mm B = 1x Wood, 110 mm x 60 mm x 5 mm, inner cutout size: 90 mm x 42 mm
Notes:
mm
A
B

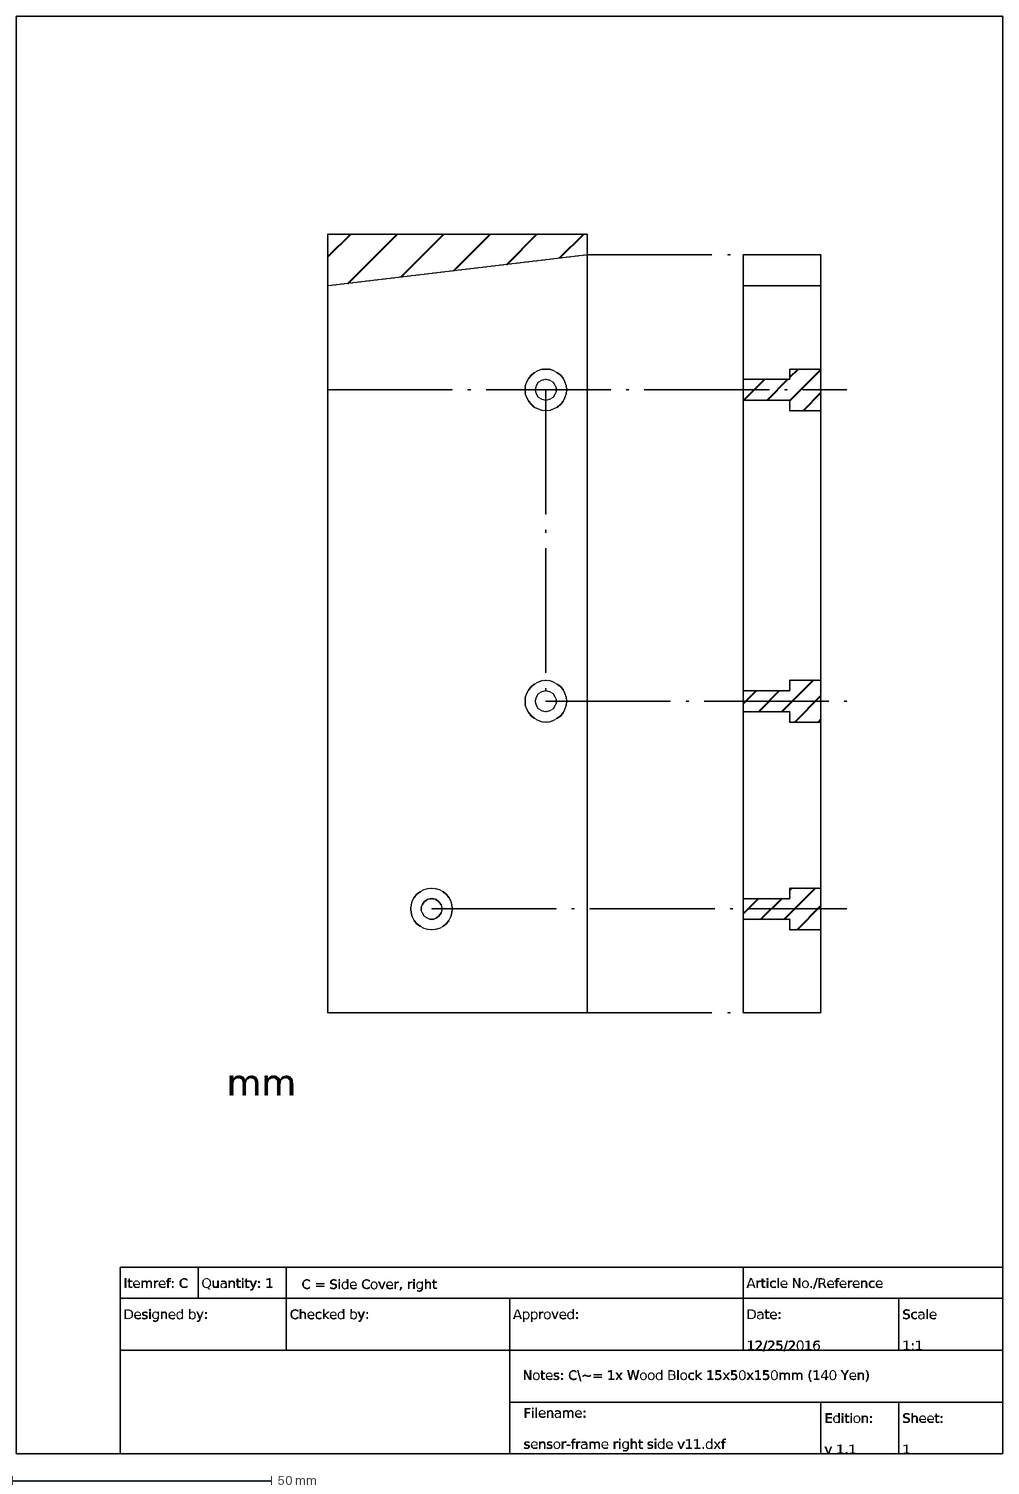
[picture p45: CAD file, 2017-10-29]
documentation/weather-station-v1.1/cad/sensor-frame right side v11.dxf
Itemref: C
Quantity: 1
C = Side Cover, right
Article No./Reference
Designed by:
Checked by:
Approved:
Filename: sensor-frame right side v11.dxf
Date: 12/25/2016
Scale 1:1
Edition: v 1.1
Sheet: 1
Notes: C\~= 1x Wood Block 15x50x150mm (140 Yen)
mm

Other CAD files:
documentation/weather-display-v1.0/cad/05 LCD Frame F and TFT back G v10.dxf
documentation/weather-station-v1.1/cad/sensor-frame side detail v11.dxf
documentation/weather-station-v1.0/cad/sensor-frame front detail v10.dxf
documentation/weather-station-v1.0/cad/sensor-frame left side v10.dxf
documentation/weather-station-v1.0/cad/sensor-frame center board v10.dxf
documentation/weather-station-v1.0/cad/sensor-frame right side v10.dxf
documentation/weather-station-v1.0/cad/sensor-frame side detail v10.dxf
documentation/weather-station-v1.0/cad/sensor-frame top cover v10.dxf

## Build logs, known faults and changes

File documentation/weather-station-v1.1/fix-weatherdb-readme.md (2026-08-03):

# fix-weatherdb

Finds and (optionally) fixes bad samples in a weather-station RRD database,
including the cases where a fault propagates silently into RRDtool's
consolidated (aggregated) archives.

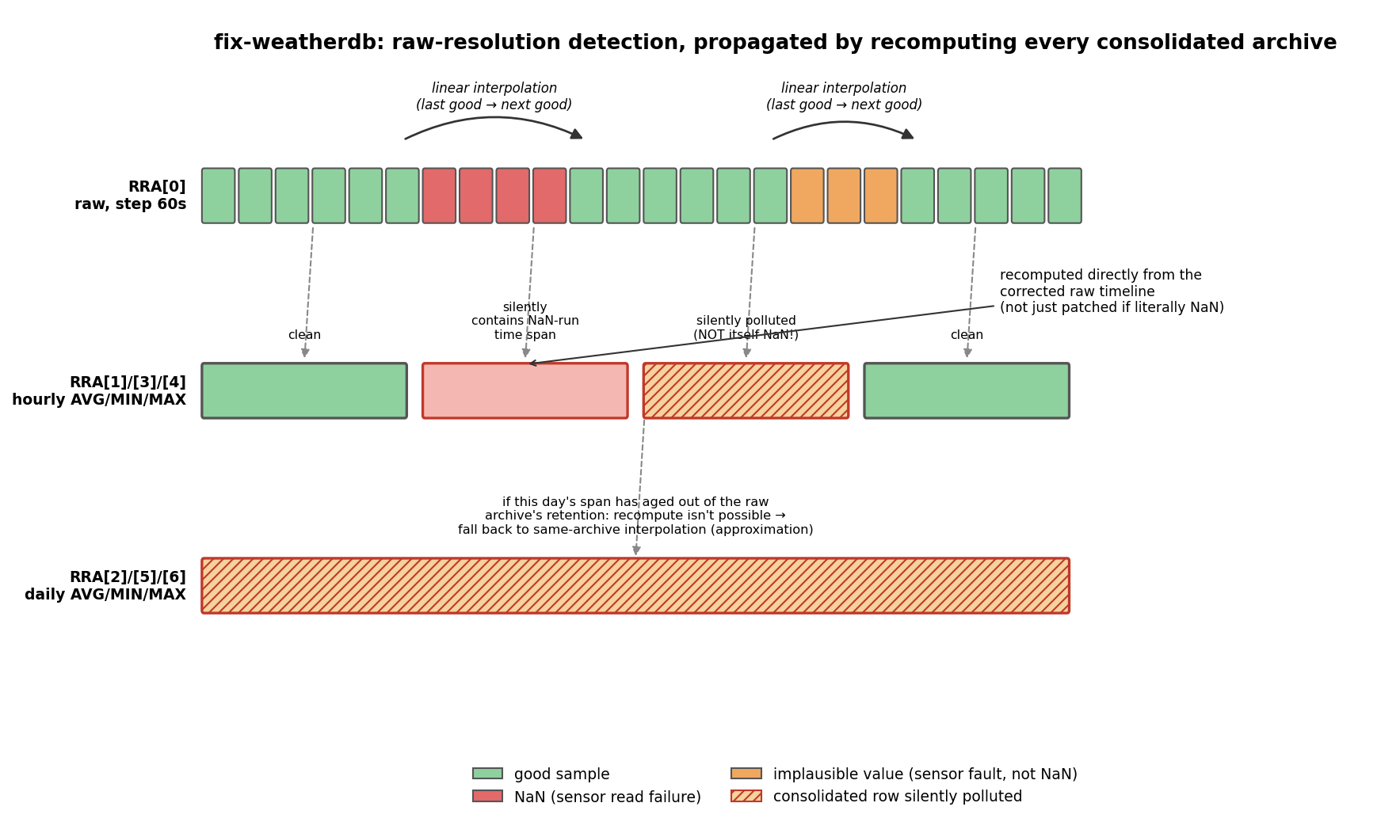
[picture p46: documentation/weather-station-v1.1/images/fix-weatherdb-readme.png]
fix-weatherdb detection and propagation diagram


## 1. Background

The weather station (`getsensor`) writes readings for four data sources
into an RRD every 60 seconds. Sensors occasionally fail to produce a valid
reading. This shows up in the database in one of two ways:

- **NaN** - the sensor read outright failed and no value was written for
  that step.
- **An implausible value** - the sensor returned a *number*, but one that's
  physically nonsensical given the surrounding readings (e.g. a momentary
  `-2 °C` reading in the middle of a `25 °C` day). This is worse than a NaN,
  because RRDtool has no way to know it's wrong - it gets treated exactly
  like a real measurement.

`fix-weatherdb` finds both kinds of fault over a requested lookback period
and, if asked, repairs them by linear interpolation.

## 2. The RRD structure it operates on

This tool is written against the specific schema used by `weather.rrd`:

| Data source | Type | Range | Fixed by this tool? |
|---|---|---|---|
| `temp` | GAUGE | -100..100 °C | yes |
| `humi` | GAUGE | 0..100 % | yes |
| `bmpr` | GAUGE | 0..200000 Pa | yes |
| `dayt` | GAUGE | 0..1 (day/night flag) | **no** - a boolean flag isn't a continuous quantity; interpolating it would produce meaningless fractional values |

Archives (`RRA`s), by index, as created for this station:

| RRA | Function | Native resolution | Retention |
|---|---|---|---|
| 0 | AVERAGE | 60s (raw) | 20160 rows (~14 days) |
| 1 | AVERAGE | 3600s (1h)  | 17568 rows (~2 years) |
| 2 | AVERAGE | 86400s (1d) | 7320 rows (~20 years) |
| 3 | MIN | 3600s (1h)  | 17568 rows |
| 4 | MAX | 3600s (1h)  | 17568 rows |
| 5 | MIN | 86400s (1d) | 7320 rows |
| 6 | MAX | 86400s (1d) | 7320 rows |

All consolidated archives use `xff = 0.5` - i.e. a consolidated row still
produces a value as long as fewer than half of the underlying raw points
feeding it are unknown; beyond that, RRDtool gives up and the row is NaN.

## 3. Detection method

### 3.1 Raw resolution only

Both fault types are only ever *detected* against `RRA[0]`, the raw,
native-step archive. "Sudden jump" is only a meaningful test at native
resolution - an hourly or daily average can legitimately move by a large
amount during real weather, so the same absolute-threshold test can't be
applied at coarser resolutions without producing false positives.

- **NaN**: a literal NaN in the raw archive.
- **Implausible value**: compared against the mean of the last **5** good
  (non-bad) raw samples for that data source. If a reading deviates from
  that rolling baseline by more than a threshold, it's flagged:

  | Data source | Threshold |
  |---|---|
  | `temp` | 15 °C |
  | `humi` | 30 percentage points |
  | `bmpr` | 1000 Pa (10 hPa) |

  These are `#define`s at the top of `fix-weatherdb.c` and can be retuned
  without touching any logic. They're intentionally loose: real weather
  (e.g. a typhoon's pressure drop) moves far slower than a sensor glitch, so
  the goal is to only catch readings that are clearly physically wrong, not
  to flag genuine fast-moving weather.
  A reading only gets judged once at least 3 good samples have been
  collected for its rolling baseline; before that, anything non-NaN is
  accepted (there's not yet enough history to judge it).

A run of one or more consecutive bad raw samples (NaN, implausible, or a
mix of both) is bounded by the last good value *before* it and the first
good value *after* it, then linearly interpolated in time between those two
points. A run that isn't bounded on both sides (e.g. the sensor is *still*
down, or the run starts right at the edge of the database's history) is
reported but left untouched - there's nothing to interpolate towards.

### 3.2 Why the consolidated archives need separate handling

A literal NaN is excluded from RRDtool's own consolidation math. An
implausible-but-numeric value is **not** - it gets averaged/min'd/max'd in
like any other real number. That means a bad raw sample can leave the
hourly or daily archive containing a real, wrong, non-NaN number, with no
outward sign anything is wrong. Scanning each consolidated archive for
literal NaN (as the raw archive is scanned) would completely miss this.

### 3.3 Recompute from the corrected raw timeline

Once the raw archive's bad runs have been interpolated, every row of every
consolidated archive that overlaps a bad time span is **recomputed directly
from the corrected raw data** - a fresh AVERAGE/MIN/MAX over that row's
exact time window, using the archive's own `xff` to decide whether enough
of the underlying data was known. This is compared against - and, with
`-w`, replaces - whatever was already stored there, regardless of whether
that stored value happened to look "fine".

### 3.4 Fallback when raw data has aged out

The raw archive only retains ~14 days. If a consolidated row's time span is
older than that, there's no corrected raw data left to recompute it from.
In that case the tool falls back to the older, simpler method: linear
interpolation using that archive's own neighbouring valid rows. This can
still only catch a literal NaN at that point - an implausible-but-numeric
value in a consolidated row that's aged out of raw retention is
undetectable, since there's no longer any raw evidence that it's wrong.

## 4. Usage

```
fix-weatherdb -f <rrd-file> -b <Nd|Nh> [-w] [-d]
fix-weatherdb -h
```

| Option | Meaning |
|---|---|
| `-f <file>` | Full path to the RRD database to analyze/fix. |
| `-b <Nd or Nh>` | Lookback window, e.g. `7d` or `48h`. Window is `[now-N, now]`. |
| `-w` | Commit fixes to the database. Without it, only reports findings. |
| `-d` | Debug output: every bad row and every consolidated archive row touched. |
| `-h` | Help. |

```
./fix-weatherdb -f /home/pi/pi-ws01/rrd/weather.rrd -b 7d
./fix-weatherdb -f /home/pi/pi-ws01/rrd/weather.rrd -b 48h -w
```

Default (non-debug) console output reports each bounded gap at raw
resolution, its composition (how many samples were NaN vs. implausible),
and, with `-w`, a summary of how many points were written per data source
per archive.

## 5. Safety

- `rrd_dump()`/`rrd_restore()` (the same public API `rrdtool` itself uses)
  are used instead of poking the binary file format directly.
- Before any write, the original file is copied to `<file>.bak`.
- The fixed database is built in a temp file in the *same directory* as the
  target (so the final replace is an atomic `rename()`), and only swapped
  in after a successful restore.

## 6. Known limitations

- A bad run touching either edge of the database's retained history (still
  ongoing, or older than all retained data) can't be interpolated and is
  reported as unresolved.
- Right at the raw-retention boundary (~14 days back), a same-archive
  fallback run that started just before the boundary won't see a recompute
  fixed value just after the boundary as its "next good" neighbour; this is
  a deliberately conservative edge case (better to leave a row untouched
  than guess wrong at that boundary).
- Thresholds are static and don't vary by season or time of day; very rapid
  legitimate weather changes close to the threshold values could in theory
  still be flagged. Retune the `THRESH_*` constants if this happens for your
  station's climate.

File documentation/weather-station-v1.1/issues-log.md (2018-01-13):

# Weather Station Version 1.1 Issue Log

## 1. RRD consolidation function is hard-coded to UTC

I whish RRD had the ability to specify a local timezone offset for the consolidation. 

For example, the weather station records temperature in 1-min intervals, kept for 10 days:

`DS:temp:GAUGE:300:-50:100 RRA:AVERAGE:0.5:1:14400`

For longterm data recording, the stations daily minimum and maximum temperature is kept for, say, 20 years:

`RRA:MIN:0.5:60:17568 RRA:MAX:0.5:60:17568`

With the highest resolution set to 1 minute, RRDtool loads the recorded temperatures in 1 minute intervals, using UTC timestamps. Displaying the 1-minute interval data in reference to a local time zone is no problem. The graph generation observes the timezone offset from UTC.

Now, lets say the days lowest temperature is 2°C, and gets recorded at 4:00 AM local time in a place having a timezone offset of -9 hrs (Japan JST). Because the RRD consolidation function occurs at midnight UTC, the consolidation happens at 9:00 AM JST.

This causes two issues: 

First, the previous day's Min/Max values do not become available at midnight local time, because the consolidation occurs at 9:00 AM local time the following day.

Second, the MIN value that was recorded at 4:00 AM local time gets consolidated with the timestamp using UTC, and because the consolidation happens at 9:00 AM, it will be assigned the UTC date instead of the local time date. In my example, the local timezone is 9 hours ahead of UTC, which means at the time the consolidation runs, our MIN value gets the UTC timestamp of the previous day instead. It is not possible to correct or compensate afterwards, because we no longer know the exact original timestamp of the Min value! This makes the consolidation meaningless under local timezone context.

Possible solutions:

**1)** Fake the initial 1-min UTC recording timestamps with an offset, e.g. by setting the system clock to local time instead of UTC.

This is a serious challenge, say if the weather stations get synced with GPS. It also causes other system issues, e.g  for log timestamps, and file copy, and for the individual weather station data consolidation to a central server. This also breaks the graph's background coloring for local nighttime, because its calculated from GPS locations sunset/sunrise time.

**2)** Implemented. In this workaround, I do not use the RRD consolidation for daily MIN/MAX values. Instead I expanded the lowest resolution range to 2 weeks, and implemented a search through the full RRD data set, which is coded outside of RRD. For monthly consolidation I still use the RRD function and accept the error for now. The chances are much lower that a MIN/MAX value occurs at the month's borders, but its still bothersome.

Ideal would be adding the option to specify a timezone to let RRD consolidation happen at midnight local time, observing UTC offset. Possibly even observe summertime adjustments. Weather data should always be seen in local context, local daytime/nighttime exposure to sunlight framing the temperature ranges.

For example:

`RRA:MIN:0.5:60:17568 RRA:MAX:0.5:60:17568` uses existing default UTC-based consolidation

`RRA:MIN:0.5:60:17568 RRA:MAX:0.5:60:17568:Asia/Tokyo` adding new option to specify a time zone, letting RRD calculate the offset to consolidate at local midnight instead of UTC.

## 2. RRD graphs nighttime background does not extend below zero if temperature becomes negative

I currently color the nighttime with a grey background, using the following expression:

<pre>  DEF:dayt1=$RRD:dayt:AVERAGE \
  'CDEF:dayt2=dayt1,0,GT,INF,UNKN,IF' \
  'AREA:dayt2#cfcfcf' \</pre>

The RRD value dayt stores the info about night (set to '1'), and day ('0'). If its 1, the area is shaded to grey (#cfcfcf) towards infinity (INF). It works great in summer, but wintertime brings temperatures below zero. The nighttime coloring continues to work, but starts at zero, leaving the area with the negative temperature at default white background.

Solution: Add a second area, stacked on top of the first, which adds below-zero coloring against negative infinity (NEGINF). 

<pre>  DEF:dayt1=$RRD:dayt:AVERAGE \
  'CDEF:dayt2=dayt1,0,GT,INF,UNKN,IF' \
  'AREA:dayt2#cfcfcf' \
  'CDEF:tneg1=dayt1,0,GT,NEGINF,UNKN,IF' \
  'AREA:tneg1#cfcfcf' \</pre>

Note 1: A conditional execution, e.g. shade second area only if temp < 0 is not needed, would complicate code without benefit.

Note 2: Initially I thought I would need 'AREA:tneg1#cfcfcf:STACK' to add onto the first area. This created problems because I got a legend entry for STACK. According to rrdtool documentation it should be 'AREA:tneg1#cfcfcf::STACK' with an extra colon, but that broke the second area which did not show at all. I just left it out, and that worked.

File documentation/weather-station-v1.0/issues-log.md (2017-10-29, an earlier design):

# Weather Station Version 1.0 Issue Log

## 1. Pi crash due to syslog data stuck in the xconsole pipe.

See also https://www.raspberrypi.org/forums/viewtopic.php?f=91&t=122601

Solution: Comment out last 4 lines in /etc/rsyslogd.conf:

```
#daemon.*;mail.*;\
#       news.err;\
#       *.=debug;*.=info;\
#       *.=notice;*.=warn       |/dev/xconsole
```

## 2. Extensive logs from cron execution

The seansor data aquisition is done through cron-controlled scripts in 1-minute intervals. Cron created a log entry each time it runs, which leads to excessive wear and logfile growth.

**Solution:** Turn off cron logging by setting `EXTRA_OPTS="-L 0"` in /etc/default/cron

## 3. Reading sensor data creates unnecessary GPIO access log records

Log example:
`Feb 26 14:56:08 raspi2 kernel: [  326.361596] gpiomem-bcm2835 3f200000.gpiomem: gpiomem device opened.`

**Solution 1:** Filter the log message in /etc/rsyslog.conf by setting the following rule as the first entry:
```
#
# Here we supress the gpio messages from reading sensor data
#
:msg, contains, "gpiomem-bcm2835 3f200000.gpiomem: gpiomem device opened." stop
```

**Solution 2:** Disable `CONFIG_DYNAMIC_DEBUG` by modprobe options

```
vi /etc/modprobe.d/bcm2835_gpiomem.conf
...
options bcm2835_gpiomem dyndbg=-p
```

save and reboot.

## 4. Micro SD Card Failure

**Solution 1:** Installation of a backup USB stick (dev/sda1), together with a weekly backup script that creates backups of package list, configuration files, data and script directories.

**Solution 2:** Selection of a reliable brand SD card with sufficient free space for wear-levelling. Standardizing on Samsung model MB-MC64DA microSDXC 64GB EVO+ Class10 UHS-I.

MB-MC64DA	Samsung microSDXC 64GB EVO+ Class10 UHS-I (21 MB/s Windows write speed)
```
Disk /dev/mmcblk0: 59.6 GiB, 64021856256 bytes, 125042688 sectors
Units: sectors of 1 * 512 = 512 bytes
Sector size (logical/physical): 512 bytes / 512 bytes
I/O size (minimum/optimal): 512 bytes / 512 bytes
Disklabel type: dos
Disk identifier: 0x0d1eadf0
```
```
Device         Boot  Start       End   Sectors  Size Id Type
/dev/mmcblk0p1        8192    137215    129024   63M  c W95 FAT32 (LBA)
/dev/mmcblk0p2      137216 125042687 124905472 59.6G 83 Linux
```

Substitute models:

MB-MC64GA/ECO	Samsung microSDXC 64GB EVO Plus Class10 UHS-I U3 (52 MB/s Windows write speed)
```
Disk /dev/mmcblk0: 59.6 GiB, 64021856256 bytes, 125042688 sectors
Units: sectors of 1 * 512 = 512 bytes
Sector size (logical/physical): 512 bytes / 512 bytes
I/O size (minimum/optimal): 512 bytes / 512 bytes
Disklabel type: dos
Disk identifier: 0xafe031c2
```
```
Device         Boot Start       End   Sectors  Size Id Type
/dev/mmcblk0p1       8192     92159     83968   41M  c W95 FAT32 (LBA)
/dev/mmcblk0p2      92160 125042687 124950528 59.6G 83 Linux
```

MB-MD64GA Samsung microSDXC 64GB PRO+ Class10 UHS-I U3 (90 MB/s Windows write speed)
```
Disk /dev/mmcblk0: 59.6 GiB, 64021856256 bytes, 125042688 sectors
Units: sectors of 1 * 512 = 512 bytes
Sector size (logical/physical): 512 bytes / 512 bytes
I/O size (minimum/optimal): 512 bytes / 512 bytes
Disklabel type: dos
Disk identifier: 0xaaa6313d
```
```
Device         Boot  Start       End   Sectors  Size Id Type
/dev/mmcblk0p1       49152    253951    204800  100M 83 Linux
/dev/mmcblk0p2      253952 125042687 124788736 59.5G 83 Linux
```

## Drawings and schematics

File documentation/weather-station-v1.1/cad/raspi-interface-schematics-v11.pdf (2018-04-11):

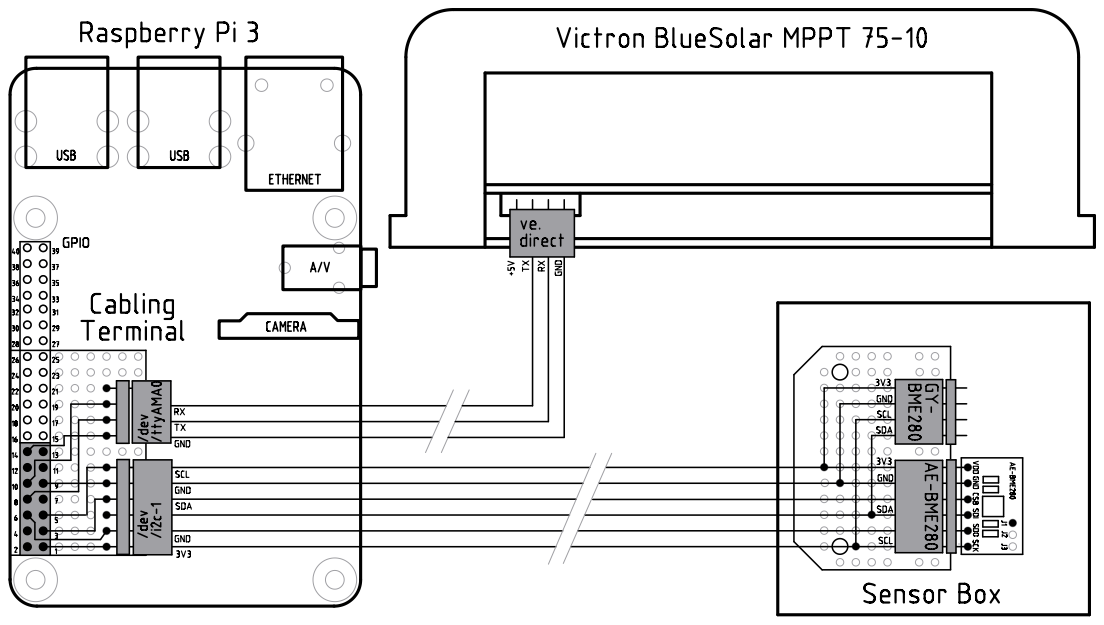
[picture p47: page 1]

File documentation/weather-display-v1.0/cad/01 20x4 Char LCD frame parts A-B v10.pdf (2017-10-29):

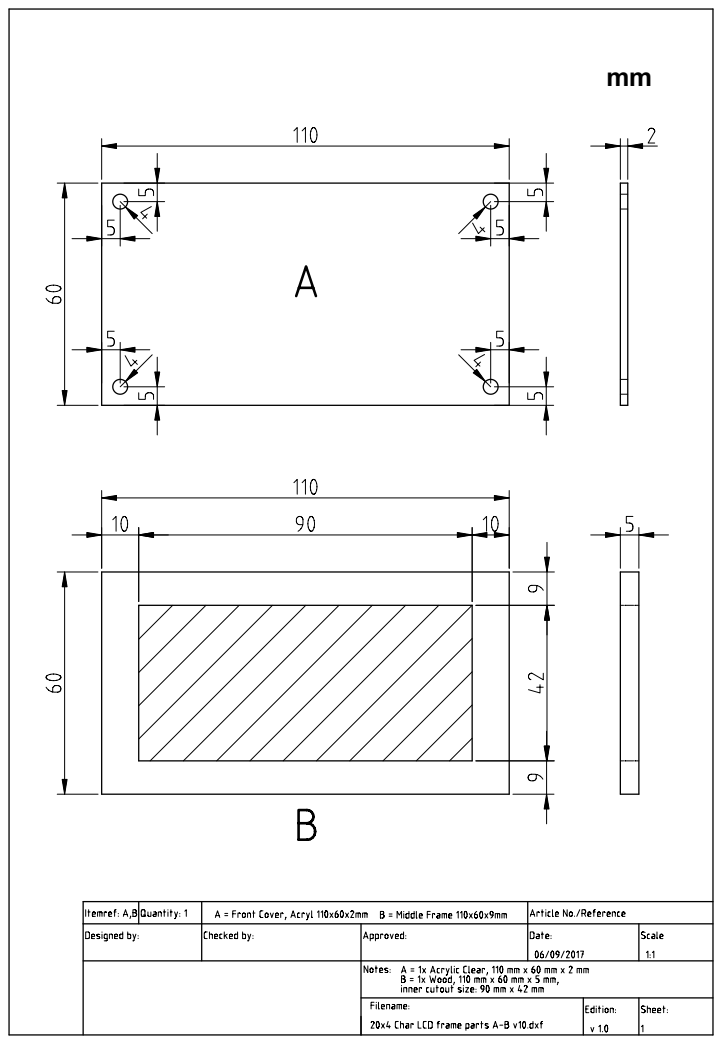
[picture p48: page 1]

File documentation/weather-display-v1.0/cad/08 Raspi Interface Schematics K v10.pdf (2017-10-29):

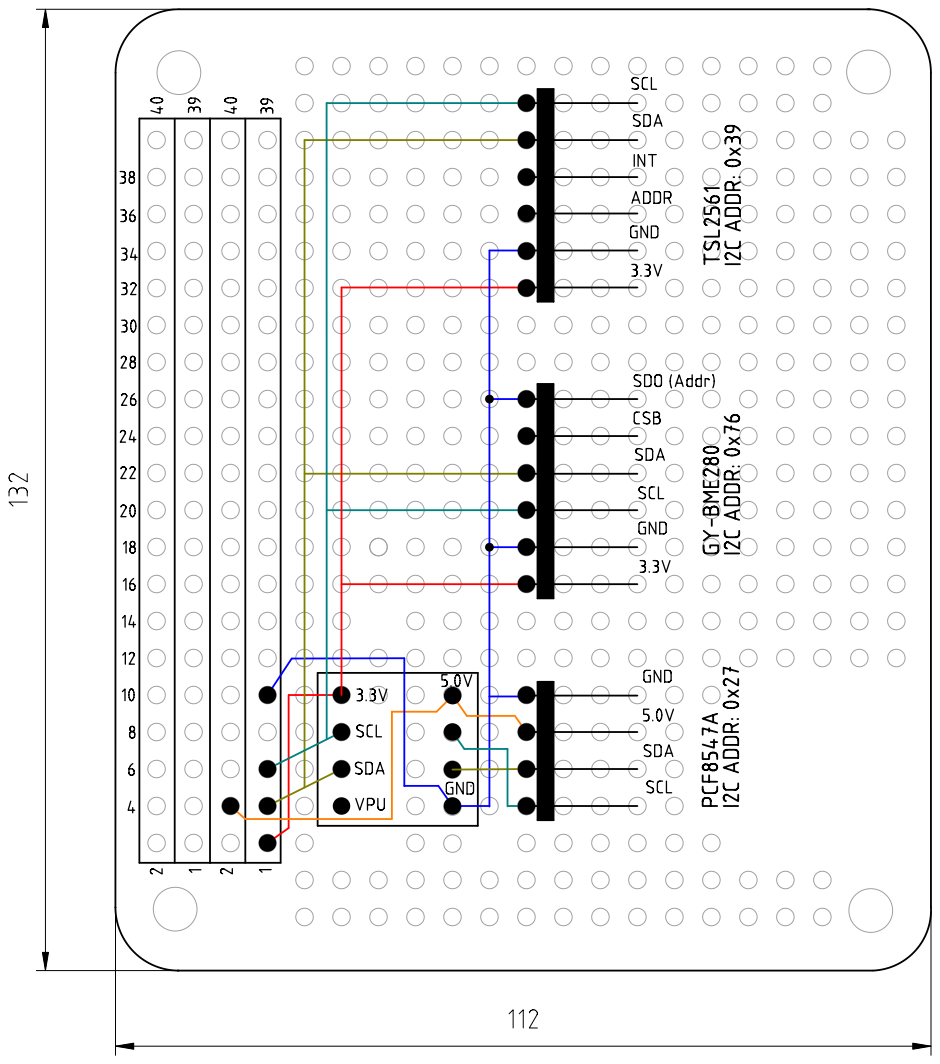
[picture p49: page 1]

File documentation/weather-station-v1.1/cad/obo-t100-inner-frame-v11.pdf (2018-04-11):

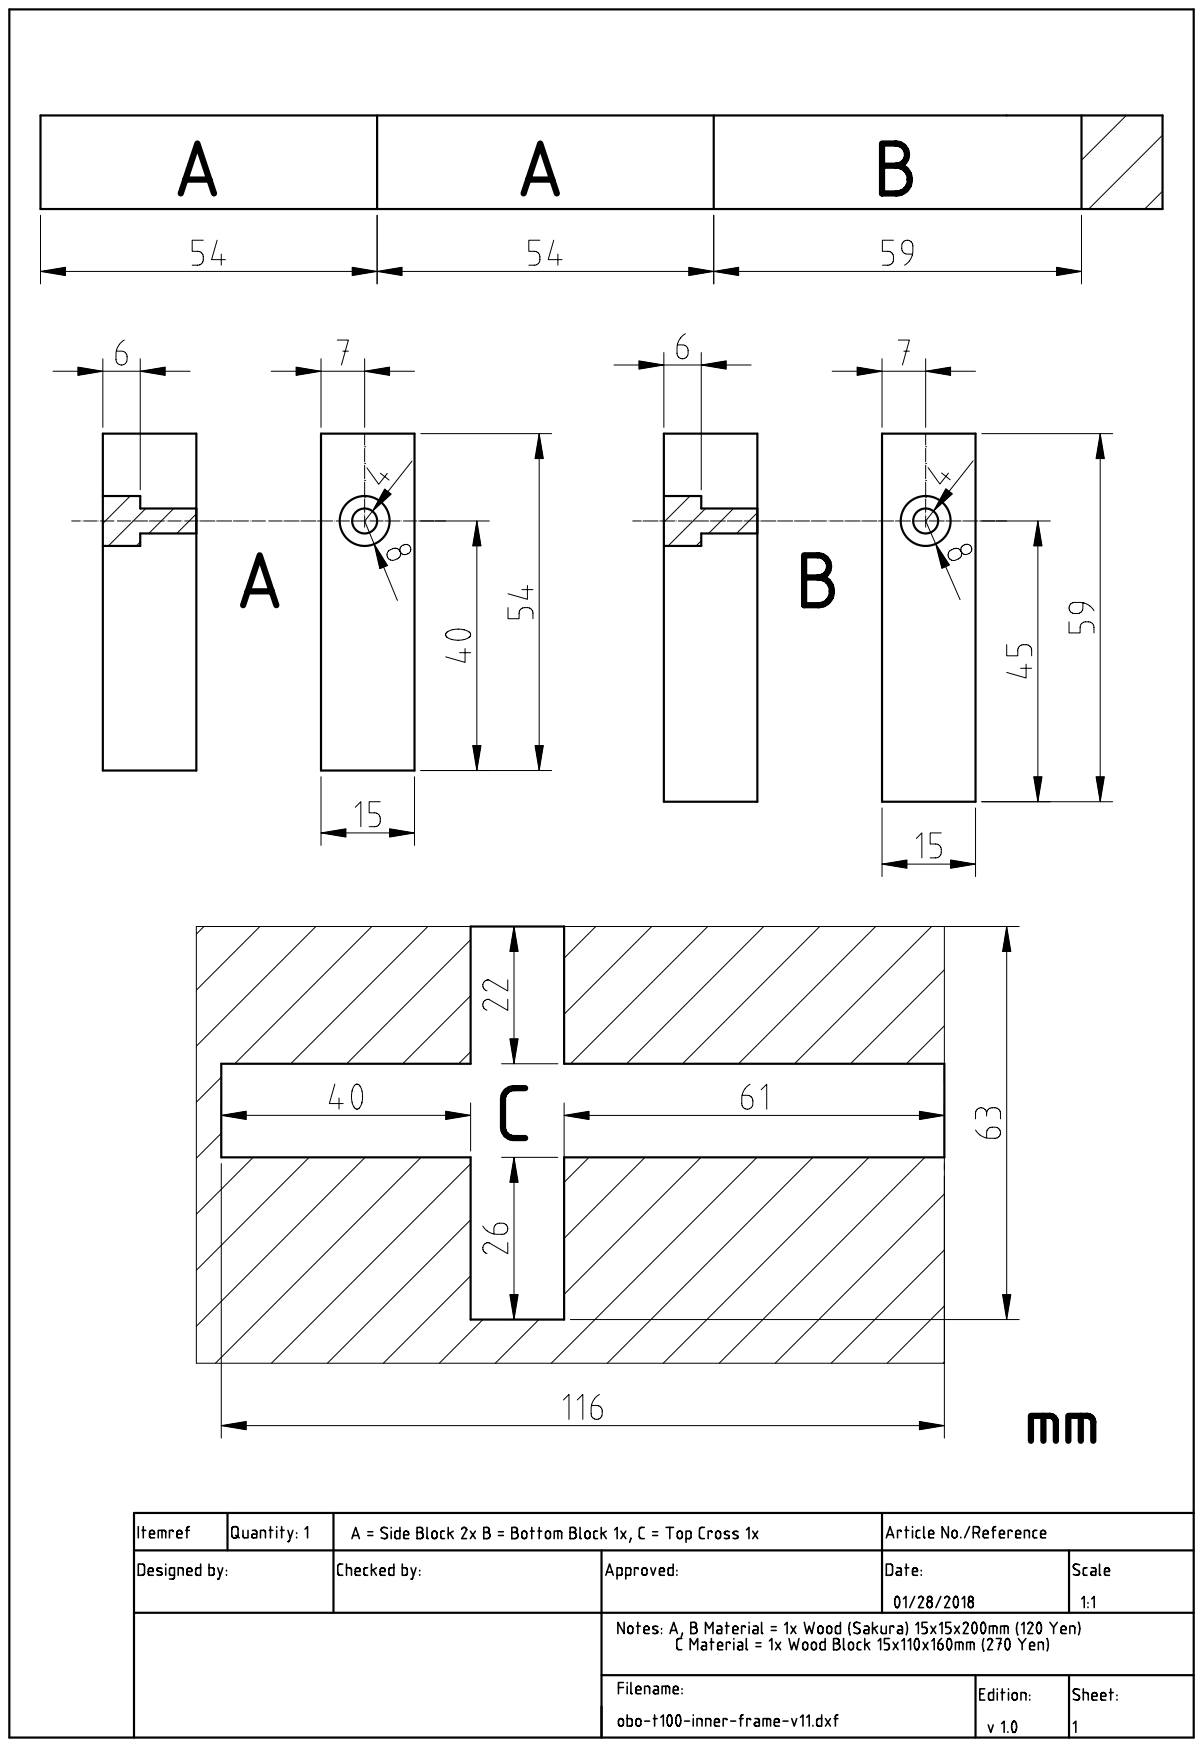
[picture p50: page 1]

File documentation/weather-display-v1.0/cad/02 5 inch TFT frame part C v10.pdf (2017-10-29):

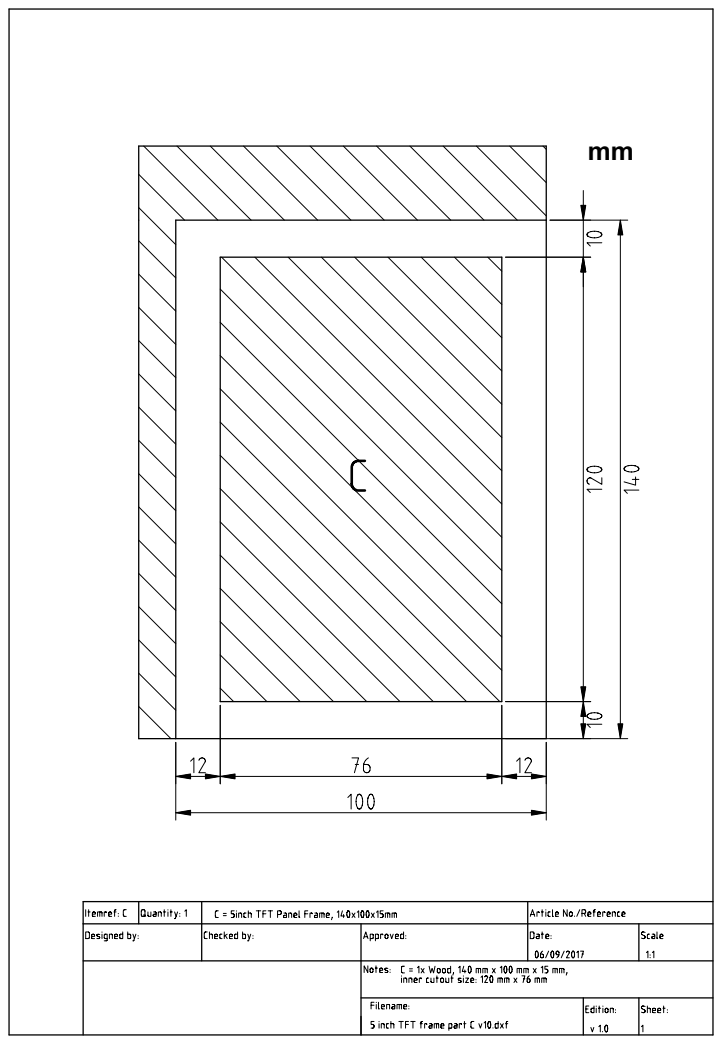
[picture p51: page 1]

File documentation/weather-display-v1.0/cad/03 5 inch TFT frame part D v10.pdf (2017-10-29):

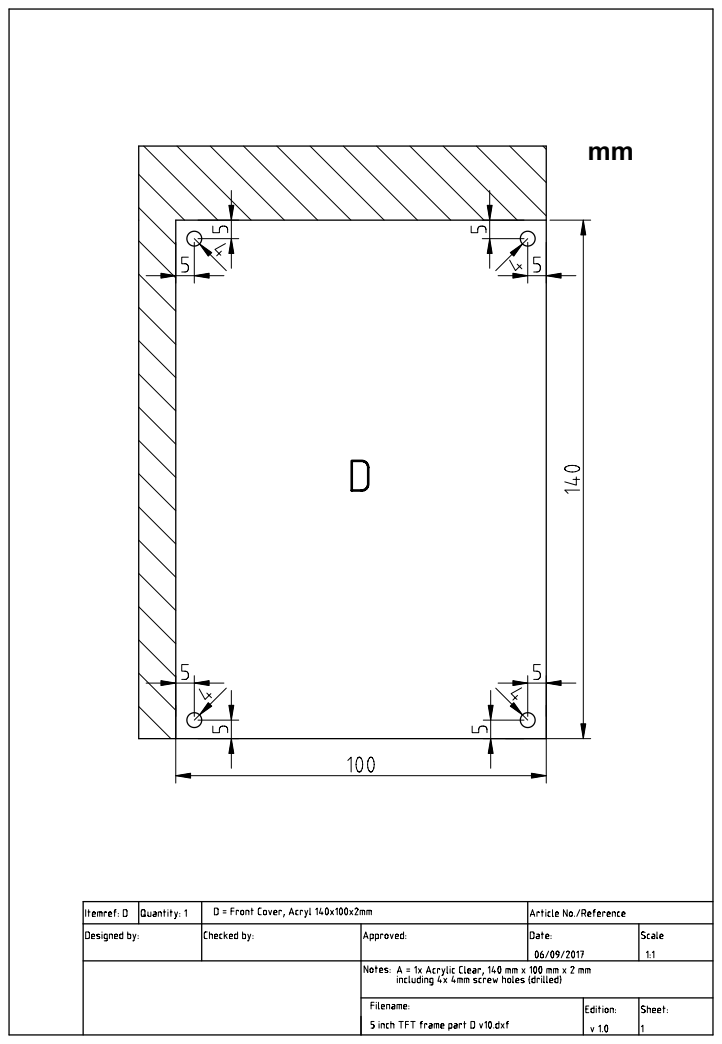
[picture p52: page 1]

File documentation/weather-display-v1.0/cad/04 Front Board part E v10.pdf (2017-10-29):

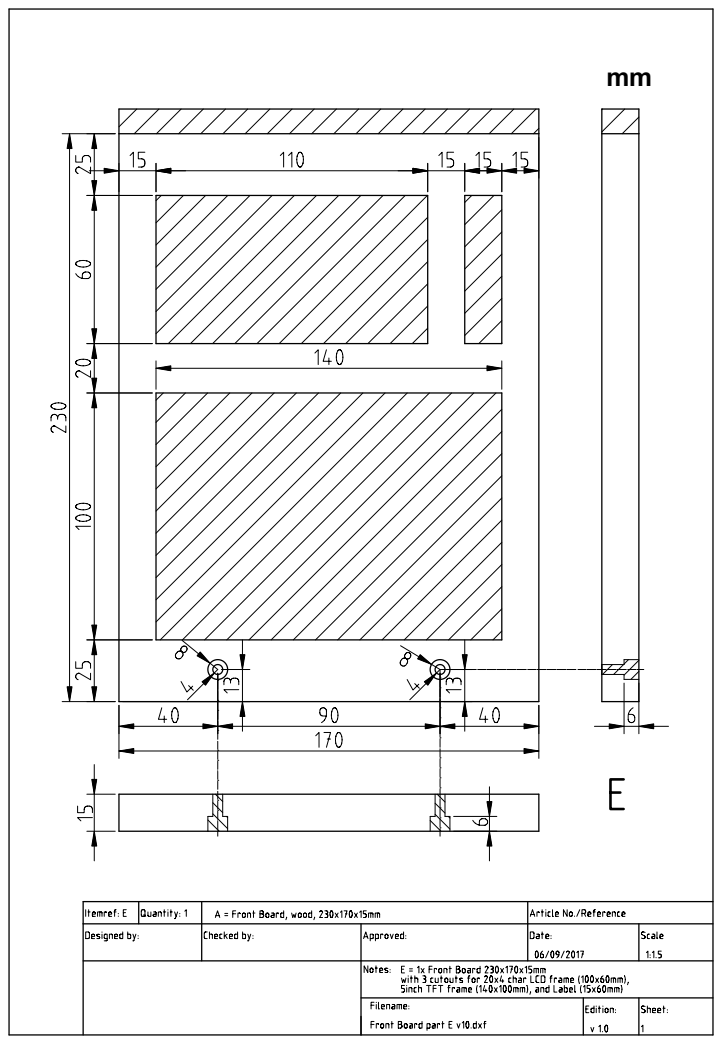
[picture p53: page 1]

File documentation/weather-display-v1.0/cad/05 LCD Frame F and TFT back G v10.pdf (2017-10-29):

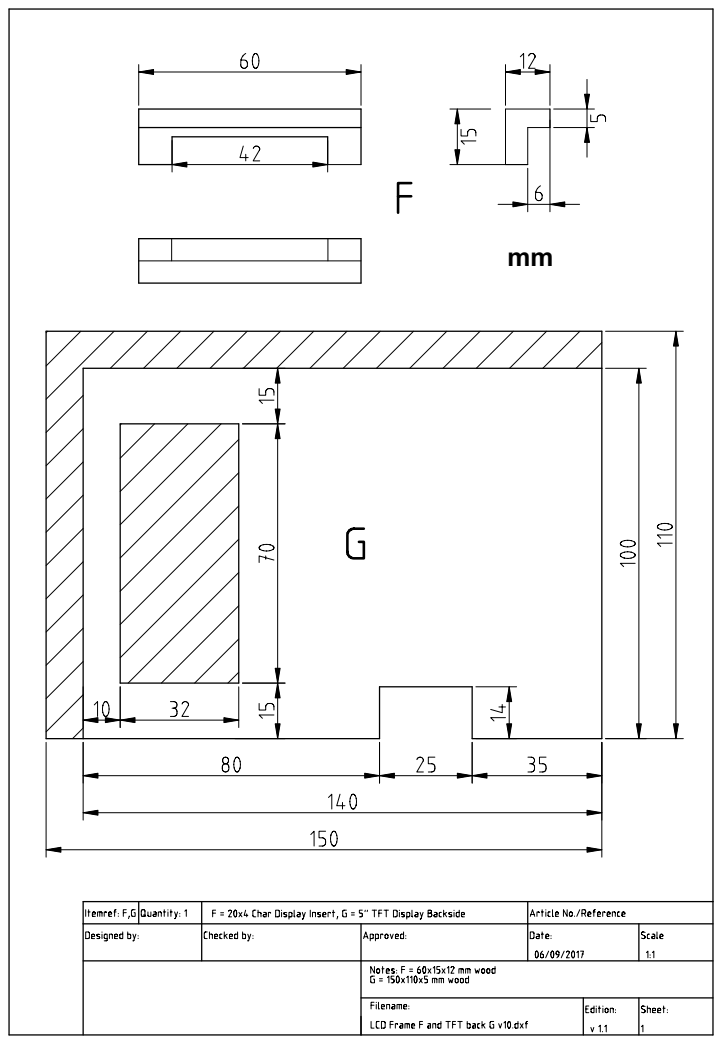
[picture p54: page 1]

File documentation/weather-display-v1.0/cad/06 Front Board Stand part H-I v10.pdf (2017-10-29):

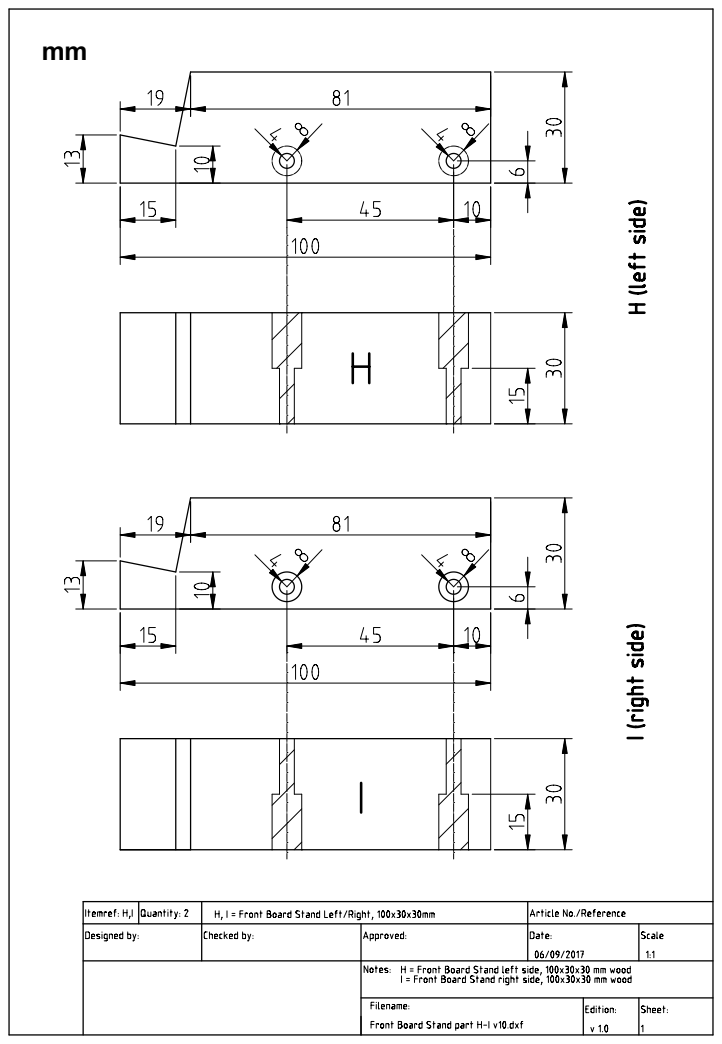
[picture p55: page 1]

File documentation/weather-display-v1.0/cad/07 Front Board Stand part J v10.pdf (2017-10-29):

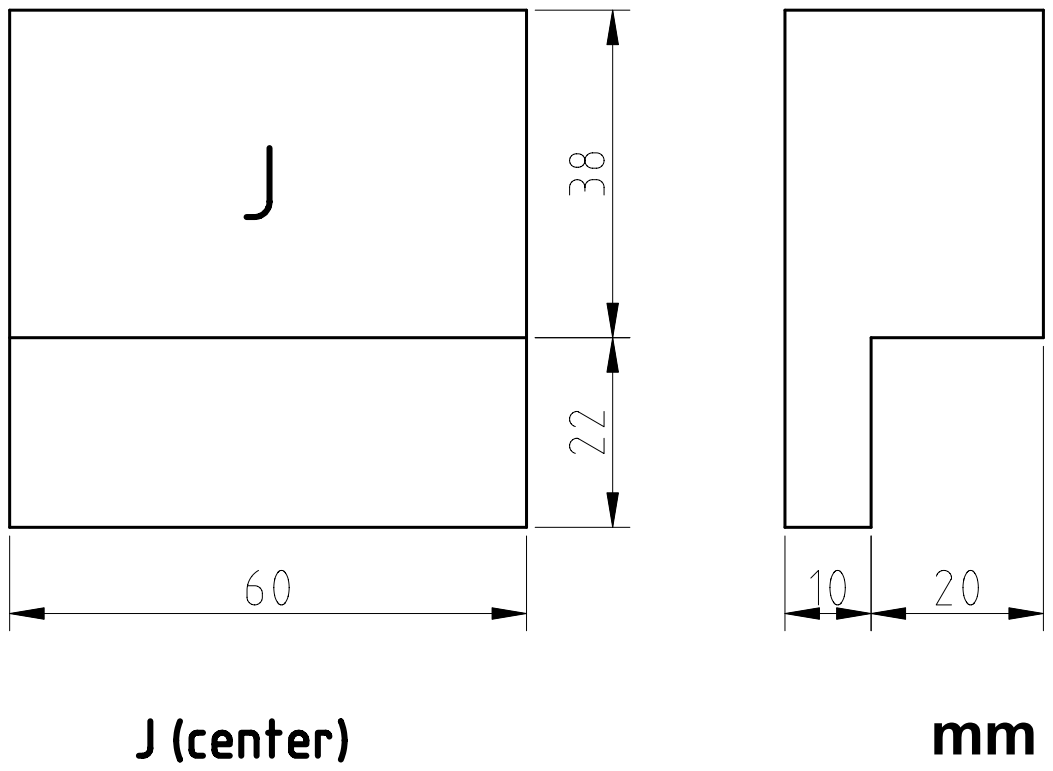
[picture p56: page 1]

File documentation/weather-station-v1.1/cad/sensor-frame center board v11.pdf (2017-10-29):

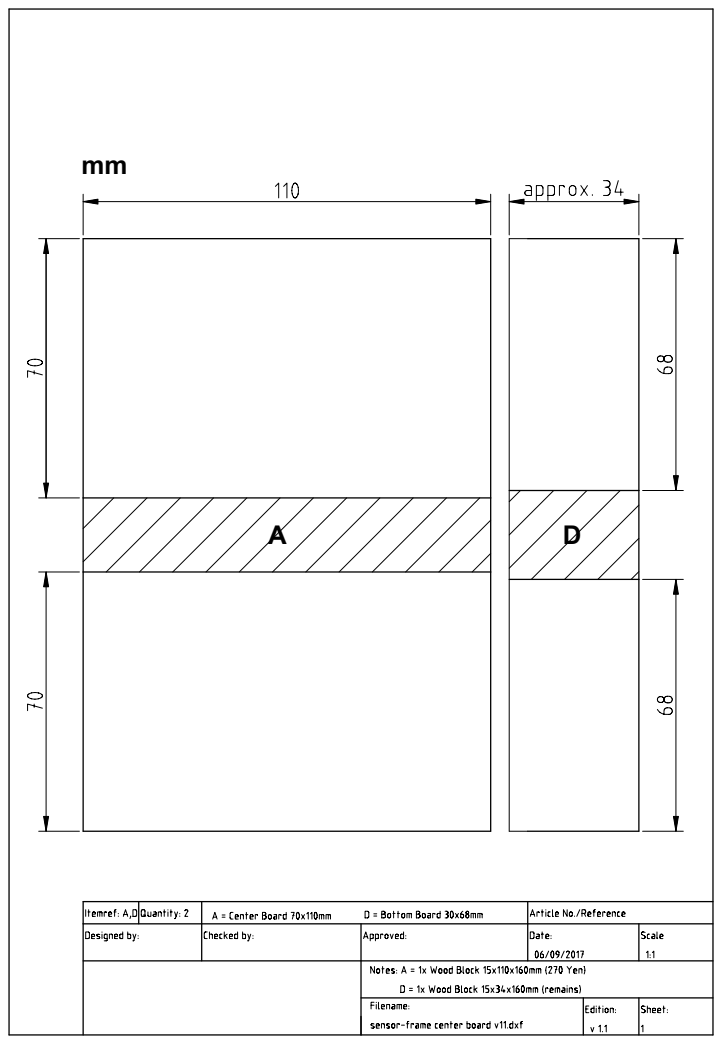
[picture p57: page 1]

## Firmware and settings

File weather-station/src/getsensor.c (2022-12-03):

/* ------------------------------------------------------------ *
 * file:        getsensor.c                                     *
 * purpose:     Read sensor data from a supported sensor module *
 *                                                              *
 * params:      -t = sensor type, supported are:                *
 *                   bme280 = Bosch BME 280 I2C sensor          *
 *                   am2302 = AM2302 one-wire sensor + BMP180   *
 *              -a = I2C address for BME280 or BMP180           *
 *              -p = the GPIO pin nunber of AM2302/DHT22 sensor *
 *              -b,c,d = calibration offset for temp, pressure  *
 *                   and humidity                               *
 *              -j = write results into JSON file               *
 *              -o = write results into html file               *
 *                                                              *
 * return:      0 on success, and -1 on errors.                 *
 *                                                              *
 * example:	./getsensor -t bme280 -a 0x76 -o getsensor.htm  *
 * 1493799157 Temp=24.46*C Humidity=35.82% Pressure=1007.84hPa  *
 *                                                              *
 * author:      05/04/2017 Frank4DD                             *
 * ------------------------------------------------------------ */
#include <stdlib.h>
#include <stdio.h>
#include <ctype.h>
#include <unistd.h>
#include <string.h>
#include <getopt.h>
#include <time.h>

#define DHT11 11
#define DHT22 22

/* ------------------------------------------------------------ *
 * Global variables and defaults                                *
 * ------------------------------------------------------------ */
int verbose = 0;
int outflag = 0;
char sentype[256];
char senaddr[256];
char outfile[256];
int sensorpin = 0;
int tempcalib = 0;
int humicalib = 0;
int bmprcalib = 0;
extern char *optarg;
extern int optind, opterr, optopt;

/* ------------------------------------------------------------ *
 * external function prototypes for sensor-type specific code
 * ------------------------------------------------------------ */
int read_bme280(char* addr, float *tptr, float *hptr, float *bptr, int verbose);
int read_am2302(int type, int pin, float *tptr, float *hptr, int verbose);
int read_bmp180(char* addr, float *bptr, int verbose);

/* ------------------------------------------------------------ *
 * print_usage() prints the programs commandline instructions.  *
 * ------------------------------------------------------------ */
void usage() {
   static char const usage[] = "Usage: getsensor -t [type] -a [hex i2c addr] -o [html-output] [-v]\n\
\n\
Command line parameters have the following format:\n\
   -t   sensor module type, Example: bme280\n\
        supported types: bme280, am2302 (in combination with BMP180)\n\
   -a   sensor address on the I2C bus in hex, Example: -a 0x76\n\
   -p   optional, sensor pin for AM2302 sensors, Example: -p 4\n\
   -b   optional, pressure calibration offset, Example: -b 100\n\
   -c   optional, temperature calibration offset, Example: -c -1\n\
   -d   optional, humidity calibration offset, Example: -d -2\n\
   -j   optional, write sensor data to JSON file, Example: -j ./getsensor.json\n\
   -o   optional, write sensor data to HTML file, Example: -o ./getsensor.html\n\
   -h   optional, display this message\n\
   -v   optional, enables debug output\n\
\n\
Usage examples:\n\
./getsensor -t bme280 -a 0x76 -b 50 -c -1 -d -2 -j ./getsensor.json -v\n\
./getsensor -t am2302 -a 0x76 -p 4 -c -1 -o ./getsensor.html -v\n";
   printf(usage);
}

/* ------------------------------------------------------------ *
 * parseargs() checks the commandline arguments with C getopt   *
 * ------------------------------------------------------------ */
void parseargs(int argc, char* argv[]) {
   int arg;
   opterr = 0;

   if(argc == 1) { usage(); exit(-1); }

   while ((arg = (int) getopt (argc, argv, "t:a:p:b:c:d:j:o:vh")) != -1) {
      switch (arg) {
         // arg -t + sensor type, type: string
         // mandatory, example: bme280
         case 't':
            if(verbose == 1) printf("Debug: arg -t, value %s\n", optarg);
            strncpy(sentype, optarg, sizeof(sentype)-1);
            break;

         // arg -a + sensor address, type: string
         // mandatory, example: 0x76
         case 'a':
            if(verbose == 1) printf("Debug: arg -a, value %s\n", optarg);
            strncpy(senaddr, optarg, sizeof(senaddr)-1);
            break;

         // arg -p + sensor pin, type: int
         // optional, example: 7
         case 'p':
            if(verbose == 1) printf("Debug: arg -p, value %s\n", optarg);
            sensorpin = atoi(optarg);
            break;

         // arg -b + barometric pressure calibration, type: int
         // optional, example: +100 (adds 100 Pa to pressure reading)
         case 'b':
            if(verbose == 1) printf("Debug: arg -b, value %s\n", optarg);
            bmprcalib = atoi(optarg);
            break;

         // arg -c + temp calibration, type: int
         // optional, example: -1 (reduces temp -1 degree)
         case 'c':
            if(verbose == 1) printf("Debug: arg -c, value %s\n", optarg);
            tempcalib = atoi(optarg);
            break;

         // arg -d + humidity calibration, type: int
         // optional, example: -2 (reduces humidity -2 %)
         case 'd':
            if(verbose == 1) printf("Debug: arg -d, value %s\n", optarg);
            humicalib = atoi(optarg);
            break;

         // arg -j + dst JSON file, type: string
         // optional, example: /tmp/sensor.json
         case 'j':
            outflag = 2;
            if(verbose == 1) printf("Debug: arg -j, value %s\n", optarg);
            strncpy(outfile, optarg, sizeof(outfile)-1);
            break;

         // arg -o + dst HTML file, type: string
         // optional, example: /tmp/sensor.htm
         case 'o':
            outflag = 1;
            if(verbose == 1) printf("Debug: arg -o, value %s\n", optarg);
            strncpy(outfile, optarg, sizeof(outfile)-1);
            break;

         // arg -v verbose, type: flag, optional
         case 'v':
            verbose = 1; break;

         // arg -h usage, type: flag, optional
         case 'h':
            usage(); exit(0);

         case '?':
            if(isprint (optopt))
               printf ("Error: Unknown option `-%c'.\n", optopt);
            else
               printf ("Error: Unknown option character `\\x%x'.\n", optopt);
            usage();
            exit(-1);

         default:
            usage();
      }
   }
   if (strlen(sentype) != 6) {
      printf("Error: Cannot get valid -t sensor type argument.\n");
      exit(-1);
   }
   if (strlen(senaddr) != 4) {
      printf("Error: Cannot get valid -a sensor address argument.\n");
      exit(-1);
   }
}

int main(int argc, char *argv[]) {
   float temp;
   float humi;
   float bmpr;
   /* ------------------------------------------------------------ *
    * Process the cmdline parameters                               *
    * ------------------------------------------------------------ */
   parseargs(argc, argv);

   /* ------------------------------------------------------------ *
    * get current time (now), write program start if verbose       *
    * ------------------------------------------------------------ */
   time_t tsnow = time(NULL);
   if(verbose == 1) printf("Debug: ts=[%lld] date=%s", (long long) tsnow, ctime(&tsnow));

   /* ----------------------------------------------------------- *
    *  Read the bme280 sensor                                     *
    * ----------------------------------------------------------- */
   int res = -1;
   if(strcmp(sentype, "bme280") == 0) {
      res = read_bme280(senaddr, &temp, &humi, &bmpr, verbose);
      if(res != 0) {
         printf("Error: Cannot read sensor %s, return code %d.\n", sentype, res);
         exit(-1);
      }
   }

   /* ----------------------------------------------------------- *
    *  Read the am2302/dht22 sensor, combined with bmp180         *
    * ----------------------------------------------------------- */
   if(strcmp(sentype, "am2302") == 0) {
      if(sensorpin == 0) {
         printf("Error: Cannot get valid -p sensor pin address argument.\n");
	 exit(-1);
      }

      /* -------------------------------------------------------- *
       * DHT sensor cannot be read frequently, only to be queried *
       * once in 2sec. If we hit the read error, retry 15x times  *
       * with 2sec wait in between before giving up after 30secs. *
       * -------------------------------------------------------- */
      int retry = 0;
      int retrymax = 15;
      while(retry < retrymax) {
        res = read_am2302(DHT22, sensorpin, &temp, &humi, verbose);
        if(res == 0) break;
        sleep(2);
        retry++;
      }

      if(res != 0) {
         printf("Error: Cannot read sensor %s after %d attempts, return code %d.\n", sentype, retrymax, res);
         exit(-1);
      }
      else {
        if(verbose == 1) printf("Debug: Sensor read success after %d retries.\n", retry);
      }

      res = read_bmp180(senaddr, &bmpr, verbose);
      if(res != 0) {
         printf("Error: Cannot read sensor bmp180, return code %d.\n", res);
         exit(-1);
      }
   } /* End reading am2302/dht22+bmp180 sensors */

   /* -------------------------------------------------------- *
    *  Add calibration values, adjust data before final output *
    * -------------------------------------------------------- */
   if(verbose == 1) printf("Debug: sensor read temp=[%.2f] humi=[%.2f] bmpr=[%.2f]\n", temp, humi, bmpr);
   if(tempcalib != 0) {
      temp = temp + tempcalib;
      if(verbose == 1) printf("Debug: Adjust temperature with calibration offset [%d]\n", tempcalib);
   }

   if(bmprcalib != 0) {
      bmpr = bmpr + bmprcalib;
      if(verbose == 1) printf("Debug: Adjust pressure with calibration offset [%d]\n", bmprcalib);
   }

   if(humicalib != 0) {
      humi = humi + humicalib;
      if(verbose == 1) printf("Debug: Adjust humidity with calibration offset [%d]\n", humicalib);
   }

   if(outflag == 1) {
      /* -------------------------------------------------------- *
       *  Open the html file for writing the table data           *
       * -------------------------------------------------------- */
      FILE *html;
      if(! (html=fopen(outfile, "w"))) {
         printf("Error open %s for writing.\n", outfile);
         exit(-1);
      }
      fprintf(html, "<table><tr>\n");
      fprintf(html, "<td class=\"sensordata\">Air Temperature:<span class=\"sensorvalue\">%.2f&deg;C</span></td>\n", temp);
      fprintf(html, "<td class=\"sensorspace\"></td>\n");
      fprintf(html, "<td class=\"sensordata\">Relative Humidity:<span class=\"sensorvalue\">%.2f&thinsp;%%</span></td>\n", humi);
      fprintf(html, "<td class=\"sensorspace\"></td>\n");
      fprintf(html, "<td class=\"sensordata\">Barometric Pressure:<span class=\"sensorvalue\">%.2f&thinsp;hPa</span></td>\n", bmpr/100);
      fprintf(html, "</tr></table>\n");
      fclose(html);
   }

   if(outflag == 2) {
      /* -------------------------------------------------------- *
       *  Open the JSON file for writing: { "time": 1649061666,   *
       *  "temp": 10.94, "humi": 85.91, "pres": 101957.88 }       *
       * -------------------------------------------------------- */
      FILE *json;
      if(! (json=fopen(outfile, "w"))) {
         printf("Error open %s for writing.\n", outfile);
         exit(-1);
      }
      fprintf(json, "{ \"time\": %lld, \"temp\": %.2f, \"humi\": %.2f, \"pres\": %.2f }", (long long) tsnow, temp, humi, bmpr);
      fclose(json);
   }

   /* ----------------------------------------------------------- *
    * print the formatted output string to stdout (Example below) *              
    * 1498385783 Temp=27.34*C Humidity=55.82% Pressure=99702.00Pa *
    * ----------------------------------------------------------- */
   printf("%lld Temp=%.2f*C Humidity=%.2f%% Pressure=%.2fPa\n",
         (long long) tsnow, temp, humi, bmpr);

   exit(0);
}

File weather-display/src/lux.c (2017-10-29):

#include "tsl2561.h"
#include <stdlib.h>
#include <stdio.h>
#include <unistd.h>

int main(int argc, char **argv) {
	int address = 0x39;
	char *i2c_device = "/dev/i2c-1";

	void *tsl = tsl2561_init(address, i2c_device);
	tsl2561_enable_autogain(tsl);
	tsl2561_set_integration_time(tsl, TSL2561_INTEGRATION_TIME_13MS);
 
	if(tsl == NULL){ // check if error is present
		exit(1);
	} 
	
	long lux = 0;
	lux = tsl2561_lux(tsl);
	//printf("%lu\n", lux);
	
	tsl2561_close(tsl);
	i2c_device = NULL;
	return lux;
}

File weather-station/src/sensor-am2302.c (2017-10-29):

/* ------------------------------------------------------------ *
 * file:        sensor-am2302.c                                 *
 * purpose:     Extract sensor data from AOSong DHT11/22 and    *
 *              AM2302  modules. Uses the proprietary one-wire  *
 *              bus signalling. Gets temperature and humidity.  *
 *              and writes it to global variables temp and humi *
 *                                                              *
 * Parameters:  type - supports the following AOSong modules:   *
 *              DHT11, DHT22 (also covers AM2302).              *
 *                                                              *
 *              pin - The Raspberry Pi pin number the sensors   *
 *              data line connects to, e.g. 7.                  *
 *                                                              *
 * Return Code:	Returns 0 on success, and -1 on error.          *
 *                                                              *
 * author:      06/23/2017 Frank4DD                             *
 *              after code from Adafruit Tony DiCola            *
 *                                                              *
 * compile: gcc sensor-am2302.c sensor-am2302.o                 *
 * ------------------------------------------------------------ */
#include <stdio.h>
#include <errno.h>
#include <sched.h>
#include <string.h>
#include <sys/time.h>
#include <time.h>
#include <stdbool.h>
#include <stdlib.h>
#include <stdint.h>
#include "mmio.h"

/* ------------------------------------------------------------ *
 * Define errors and return values.
 * ------------------------------------------------------------ */
#define DHT_ERROR_TIMEOUT -1
#define DHT_ERROR_CHECKSUM -2
#define DHT_ERROR_ARGUMENT -3
#define DHT_ERROR_GPIO -4
#define DHT_SUCCESS 0

/* ------------------------------------------------------------ *
 * Define sensor types.
 * ------------------------------------------------------------ */
#define DHT11 11
#define DHT22 22
#define AM2302 22

/* ------------------------------------------------------------ *
 * Max time to spin in a loop before bailing out considering 
 * read timeout. 32000 is suitable for a Pi or Beaglebone. 
 * ------------------------------------------------------------ */
#define DHT_MAXCOUNT 32000

/* ------------------------------------------------------------ *
 * Number of bit pulses. The first pulse is a constant 50 micros
 * pulse, following 40 pulses to represent the data afterwards.
 * ------------------------------------------------------------ */
#define DHT_PULSES 41

/* ------------------------------------------------------------ *
 * Busy wait delay for most accurate timing, but high CPU usage.
 * Only for short periods (a few hundred milliseconds at most!)
 * ------------------------------------------------------------ */
extern void busy_wait_milliseconds(uint32_t millis);

/* ------------------------------------------------------------ *
 * General delay that sleeps so CPU usage is low, accuracy is bad.
 * ------------------------------------------------------------ */
extern void sleep_milliseconds(uint32_t millis);

/* ------------------------------------------------------------ *
 * Increase scheduling priority, try to get 'real time' results.
 * ------------------------------------------------------------ */
extern void set_max_priority(void);

/* ------------------------------------------------------------ *
 * Drop scheduling priority back to normal/default.
 * ------------------------------------------------------------ */
extern void set_default_priority(void);

void busy_wait_milliseconds(uint32_t millis) {
   // Set delay time period.
   struct timeval deltatime;
   deltatime.tv_sec = millis / 1000;
   deltatime.tv_usec = (millis % 1000) * 1000;
   struct timeval walltime;
   // Get current time and add delay to find end time.
   gettimeofday(&walltime, NULL);
   struct timeval endtime;
   timeradd(&walltime, &deltatime, &endtime);
   // Tight loop to waste time (and CPU) until enough time as elapsed.
   while (timercmp(&walltime, &endtime, <)) {
      gettimeofday(&walltime, NULL);
   }
}

void sleep_milliseconds(uint32_t millis) {
   struct timespec sleep;
   sleep.tv_sec = millis / 1000;
   sleep.tv_nsec = (millis % 1000) * 1000000L;
   while (clock_nanosleep(CLOCK_MONOTONIC, 0, &sleep, &sleep) && errno == EINTR);
}

void set_max_priority(void) {
   struct sched_param sched;
   memset(&sched, 0, sizeof(sched));
   // Use FIFO scheduler with highest priority for the lowest chance of the kernel context switching.
   sched.sched_priority = sched_get_priority_max(SCHED_FIFO);
   sched_setscheduler(0, SCHED_FIFO, &sched);
}

void set_default_priority(void) {
   struct sched_param sched;
   memset(&sched, 0, sizeof(sched));
   // Go back to default scheduler with default 0 priority.
   sched.sched_priority = 0;
   sched_setscheduler(0, SCHED_OTHER, &sched);
}
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

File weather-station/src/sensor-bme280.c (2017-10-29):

/* ------------------------------------------------------------ *
 * file:        sensor-bme280.c                                 *
 * purpose:     Extract sensor data from Bosch BME280 modules.  *
 *              Connects through I2C bus and writes temperature *
 *              relative humidity and barometric air pressure   *
 *              into global variables for processing.           *
 *                                                              *
 * Parameters:  i2caddr is a string containing the hex address  *
 *              of the Bosch BME280 sensor connected to the I2C *
 *              bus. Akizuki Denshi modules use 0x76 and 0x77.  *
 *                                                              *
 *		verbose - enable extra debug output if needed.  *
 *                                                              *
 * Return Code:	Returns 0 on success, and -1 on error.          *
 *                                                              *
 * Requires:	I2C development packages                        *
 *                                                              *
 * author:      06/23/2017 Frank4DD                             *
 *                                                              *
 * compile: gcc sensor-bme280.c sensor-bme280.o                 *
 * ------------------------------------------------------------ */
#include <stdio.h>
#include <stdlib.h>
#include <linux/i2c-dev.h>
#include <sys/ioctl.h>
#include <unistd.h>
#include <string.h>
#include <fcntl.h>
#include <time.h>

int read_bme280(char *i2caddr, float *temp_ptr, float *humi_ptr,
                                  float *bmpr_ptr, int verbose) {
/* ------------------------------------------------------------ *
 * Get the I2C bus. Raspberry Pi 2 uses i2c-1, RPI 1 used i2c-0
 * ------------------------------------------------------------ */
   int file;
   char *bus = "/dev/i2c-1";
   if((file = open(bus, O_RDWR)) < 0) {
      printf("Error failed to open I2C bus [%s].\n", bus);
      return(-1);
   }
/* ------------------------------------------------------------ *
 * Set I2C device, by default the BME280 I2C address is 0x76(136)
 * ------------------------------------------------------------ */
   int addr = (int)strtol(i2caddr, NULL, 16);
   if(verbose == 1) printf("Debug: Sensor I2C address: [0x%X]\n", addr);

   ioctl(file, I2C_SLAVE, addr);

/* ------------------------------------------------------------ *
 * Read 1 byte, the sensors chip ID rom register(0xD0)
 * ------------------------------------------------------------ */
   char reg[1] = {0xD0};
   write(file, reg, 1);
   char data[8] = {0};
   if(read(file, data, 1) != 1) {
      printf("Error: Input/Output error while reading from bme280\n");
      return(-1);
   }
   int chip_id = data[0];
   if(verbose == 1) printf("Debug: Sensor chip ID: [%d]\n", chip_id);

/* ------------------------------------------------------------ *
 * Read 24 bytes calib00-23 calibration data from register(0x88)
 * ------------------------------------------------------------ */
   reg[0] = 0x88;
   write(file, reg, 1);

   char b1[24] = {0};
   if(read(file, b1, 24) != 24) {
      printf("Error: Cannot read 24 bytes calibration data\n");
      return(-1);
   }

/* ------------------------------------------------------------ *
 * Convert the data: temp coefficents
 * ------------------------------------------------------------ */
   int dig_T1 = (b1[0] + b1[1] * 256);
   int dig_T2 = (b1[2] + b1[3] * 256);
   if(dig_T2 > 32767) dig_T2 -= 65536;
   int dig_T3 = (b1[4] + b1[5] * 256);
   if(dig_T3 > 32767) dig_T3 -= 65536;

   // pressure coefficents
   int dig_P1 = (b1[6] + b1[7] * 256);
   int dig_P2 = (b1[8] + b1[9] * 256);
   if(dig_P2 > 32767) dig_P2 -= 65536;
   int dig_P3 = (b1[10] + b1[11] * 256);
   if(dig_P3 > 32767) dig_P3 -= 65536;
   int dig_P4 = (b1[12] + b1[13] * 256);
   if(dig_P4 > 32767) dig_P4 -= 65536;
   int dig_P5 = (b1[14] + b1[15] * 256);
   if(dig_P5 > 32767) dig_P5 -= 65536;
   int dig_P6 = (b1[16] + b1[17] * 256);
   if(dig_P6 > 32767) dig_P6 -= 65536;
   int dig_P7 = (b1[18] + b1[19] * 256);
   if(dig_P7 > 32767) dig_P7 -= 65536;
   int dig_P8 = (b1[20] + b1[21] * 256);
   if(dig_P8 > 32767) dig_P8 -= 65536;
   int dig_P9 = (b1[22] + b1[23] * 256);
   if(dig_P9 > 32767) dig_P9 -= 65536;

/* ------------------------------------------------------------ *
 * Read 1 byte of data from calibration register dig_H1 (0xA1)
 * ------------------------------------------------------------ */
   reg[0] = 0xA1;
   write(file, reg, 1);
   memset(data, 0, sizeof(data));
   read(file, data, 1);
   int dig_H1 = data[0];

/* ------------------------------------------------------------ *
 * Read 7 bytes of data from register(0xE1) calib26-41
 * ------------------------------------------------------------ */
   reg[0] = 0xE1;
   write(file, reg, 1);
   read(file, b1, 7);

/* ------------------------------------------------------------ *
 * Convert the data: humidity coefficents
 * ------------------------------------------------------------ */
   int dig_H2 = (b1[0] + b1[1] * 256);
   if(dig_H2 > 32767) dig_H2 -= 65536;
   int dig_H3 = b1[2] & 0xFF ;
   int dig_H4 = (b1[3] * 16 + (b1[4] & 0xF));
   if(dig_H4 > 32767) dig_H4 -= 65536;
   int dig_H5 = (b1[4] / 16) + (b1[5] * 16);
   if(dig_H5 > 32767) dig_H5 -= 65536;
   int dig_H6 = b1[6];
   if(dig_H6 > 127) dig_H6 -= 256;

/* ------------------------------------------------------------ *
 * Select control humidity register(0xF2). This register uses  
 * only 3-bit, remaining 5 are reserved (don't change). Example:
 * Humidity OS=1x: 0x01, OS=4x: 0x03
 * ------------------------------------------------------------ */
   char config[2] = {0};
   config[0] = 0xF2;
   config[1] = 0x01;
   write(file, config, 2);

/* ------------------------------------------------------------ *
 * Select control measurement register(0xF4): Settting mode and
 * oversampling for temp and pressure. Register definition:
 * osrs_t = 3 bit, osrs_h = 3 bit, mode = 2 bit. Examples:
 * OS=1x, mode=normal: osrs_t=001, osrs_h=001, mode=11 = 0x27
 * OS=1x, mode=forced: osrs_t=001, osrs_h=001, mode=01 = 0x25
 * OS=4x, mode=normal: osrs_t=011, osrs_h=011, mode=11 = 0x6F
 * OS=4x, mode=forced: osrs_t=011, osrs_h=011, mode=01 = 0x6D
 * ------------------------------------------------------------ */
   config[0] = 0xF4;
   config[1] = 0x6D;
   write(file, config, 2);
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

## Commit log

2017-10-29 initial upload
    [01 20x4 Char LCD frame parts A-B v10.dxf, 02 5 inch TFT frame part C v10.dxf, 03 5 inch TFT frame part D v10.dxf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]
2017-11-02 weather-station v1.1 BOM
    [weather-station-v11-bom.csv]
2018-04-01 version 1.1.2 update
    [weather-station-v11-bom.csv]
2018-04-11 20180411 update
    [obo-t100-inner-frame-v11.dxf, raspi-interface-schematics-v11.dxf]
2018-04-30 cad update
2020-08-24 add temperature average to daily/monthly/yearly tables
2022-04-09 switch getsensor to JSON output
2022-04-25 switch display to JSON data input
2022-12-04 update camera detect for latest raspios
2023-01-08 RPI bullseye switches avconv to ffmpeg
2023-01-25 rrdtool add neg temperature graph color, avconf to ffmpeg
